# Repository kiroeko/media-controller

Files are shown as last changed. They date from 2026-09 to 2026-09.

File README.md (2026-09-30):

# media-controller

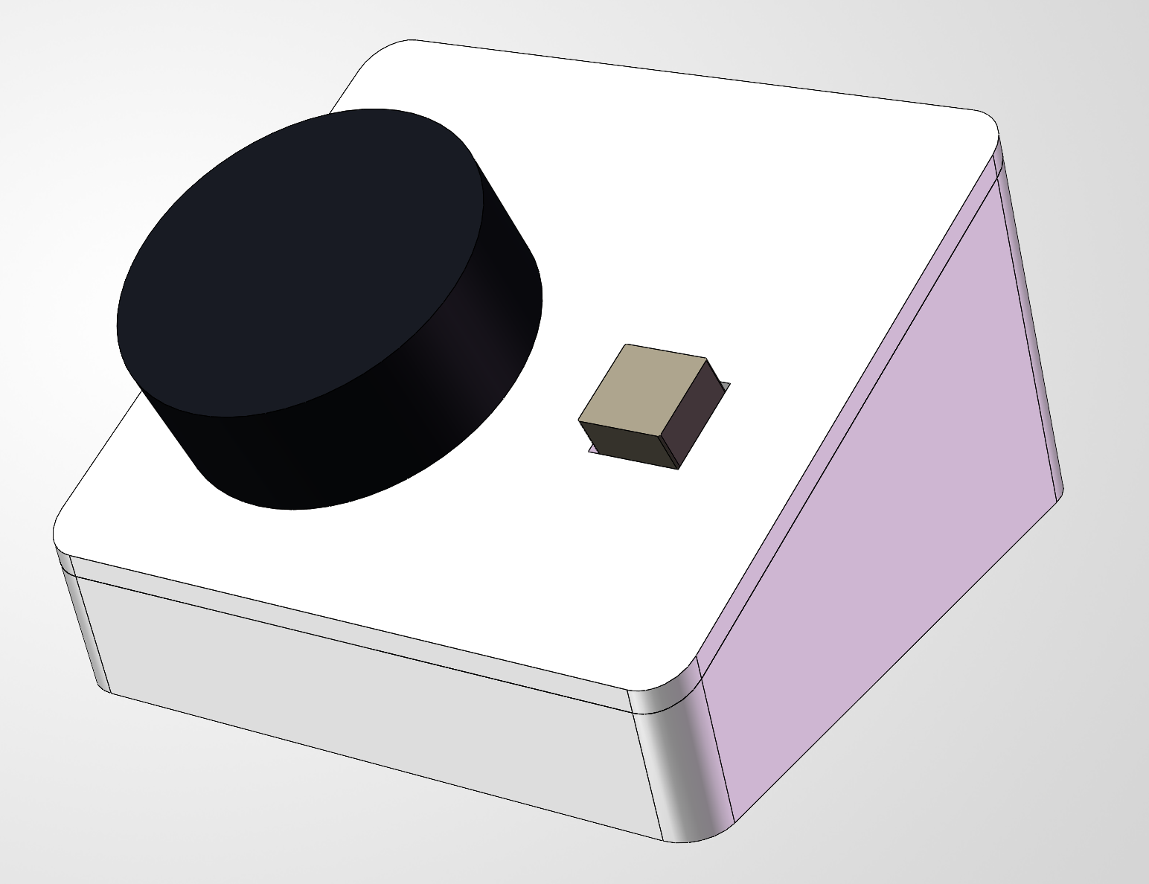
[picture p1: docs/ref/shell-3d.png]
整机外观：20° 斜面平整面板，左旋钮右按钮


一台 USB 媒体旋钮控制台：Type-C 接电脑，转旋钮调音量或切歌，按旋钮播放/暂停，长按静音，LED 自锁开关切换音量与切歌两种模式。电脑把它识别为标准 HID Consumer Control 设备，不需要安装专用驱动。

仓库包含这台设备完整的三部分设计，不只是固件。电气部分由三个现成模块组成，载板只做互连和 3V3/GND 分配，不重新设计电路；两个控件的固定、露出量和按压支撑全部交给外壳结构，载板上不布置它们的安装孔。

| 部分 | 位置 | 工具与格式 | 当前状态 |
| --- | --- | --- | --- |
| 固件 | `src/`、`include/`、`CMakeLists.txt` | C++17，Pico SDK 2.3.1 + TinyUSB | 已在整机上验证交互 |
| 载板 PCB | [hardware/pcb](hardware/pcb/README.md) | 嘉立创 EDA 专业版 `.eprj3` 工程 | v1.1 已下单并组装完成 |
| 外壳 | [hardware/enclosure](hardware/enclosure/README.md) | SOLIDWORKS 2026，导出 STL | 样件版次，待打印试装 |

三个模块是 **Waveshare RP2350-Zero** 主控、**Waveshare Rotation Sensor**（EC11 编码器带按键）和 **YFROBOT LED 自锁开关**，均为已购成品，实物资料在 [hardware/pcb/reference](hardware/pcb/reference/)。主控在调试阶段用带排针的 `-M` 版本，最终装配用无预焊排针版本，自行焊排针后插入载板排母。

## 仓库目录

```text
media-controller/
├─ README.md                 本文件：项目总览与固件说明
├─ CMakeLists.txt            板级定义 waveshare_rp2350_zero；产物 build/media-controller.uf2
├─ pico_sdk_import.cmake     pico-sdk 官方导入脚本
├─ src/                      固件实现，按分层分子目录
│  ├─ main.cpp               入口，只创建应用对象并启动
│  ├─ app/                   板级接线、运行状态与产品行为映射
│  ├─ device/                两个模块的引脚、电平、上下拉与采样节奏
│  ├─ input/                 去抖、格雷码与手势解码，不依赖 Pico SDK
│  └─ usb/                   TinyUSB 描述符、动作队列与报告发送
├─ include/                  头文件，子目录与 src/ 一一对应
├─ docs/
│  └─ ref/                   整机、载板与内部结构的参考渲染图
└─ hardware/
   ├─ pcb/                   载板：制板工程与设计记录
   │  ├─ kiro-media-controller-carrier-v1.1/   原理图、PCB 与拼板源工程
   │  ├─ reference/          三个已购模块的实物资料：主控尺寸图、按钮与编码器照片
   │  ├─ README.md           设计范围、连接方式与三个模块的实测尺寸
   │  ├─ ASSEMBLY.md         连接件规格、焊接步骤与接口方向
   │  └─ TUTORIAL.md         从新建工程到一键下单的分步教程
   └─ enclosure/             外壳：结构模型与打印文件
      ├─ cad/                Music_Controller.SLDASM 整机入口、4 个打印件、6 个 REF_ 参考件
      ├─ print/              4 个打印件的 STL
      ├─ docs/               装配与打印说明、STEP 导入、检查记录与三张剖面图
      └─ README.md           当前版次的结构改动与检查结果
```

`build/` 和 `.vscode/` 不纳入版本管理。硬件两个目录的说明各有侧重：PCB 侧记录实测尺寸、连接件选型和下单流程，外壳侧记录当前版次改了什么、检查到什么程度。SOLIDWORKS 整机入口是 `hardware/enclosure/cad/Music_Controller.SLDASM`，`cad` 里的 `REF_` 零件是器件参考模型，不打印，搬动装配体时要连整个 `cad` 目录一起带走。

下文说明固件的行为、接线、结构和构建刷写。

## 使用方式

模式开关使用 YFROBOT LED **自锁版**：每按一次切换开/关，松手后保持状态。

| LED 自锁开关 | 顺时针旋转 | 逆时针旋转 | 短按旋钮 | 长按旋钮 |
| --- | --- | --- | --- | --- |
| 熄灭：音量模式 | 音量加 | 音量减 | 播放/暂停 | 静音切换 |
| 点亮：切歌模式 | 下一首 | 上一首 | 播放/暂停 | 静音切换 |

旋转方向、模式切换、按键动作和切歌冷却机制已在整机上验证。当前冷却时间延长至 500 ms，时长的实际手感还需上板确认。LED 自锁开关单独通电时，测得灯灭时 `SIG` 对 `GND` 稳定约为 0 V、灯亮时约为 3.3 V，与固件设定的高电平有效极性一致。

在目前使用的 Windows 电脑上，一次音量动作会让系统显示值变化 2；电脑自带的独立音量键也是相同步长。这是主机侧的音量刻度，不能据此判断固件发送了两次动作。

短按在去抖后的松开时识别；长按在去抖后的按下状态持续 700 ms 后识别。手势解码器支持双击，但当前关闭该功能，250 ms 双击窗口不参与判断，也没有绑定媒体动作。

当主机挂起 USB 且允许远程唤醒时，新输入会尝试唤醒主机；成功入队的动作在总线恢复后继续发送。能否唤醒整机睡眠取决于主机配置，不能保证所有睡眠状态都可唤醒。

## 接线

两个模块都接开发板的 **3V3**，并与开发板共地；本项目不从 `5V` 或 `VBUS` 给模块供电。[RP2350 数据手册](https://datasheets.raspberrypi.com/rp2350/rp2350-datasheet.pdf)指出，使用的 GP2～GP5 属于容忍较高输入电压的 FT GPIO，且仅在 IOVDD 已供 3.3V 时才能容忍最高 5.5V 输入。统一使用 3.3V 供电可避免依赖这一条件及不同电源的上电顺序。

| 模块 | 信号 | RP2350-Zero-M |
| --- | --- | --- |
| LED 自锁开关 | `SIG` | `GP2` |
| EC11 Rotation Sensor | `SIA`（A 相） | `GP3` |
| EC11 Rotation Sensor | `SIB`（B 相） | `GP4` |
| EC11 Rotation Sensor | `SW`（内置按键） | `GP5` |
| 两个模块 | `VCC`、`GND` | `3V3`、`GND` |

LED 自锁开关的 `NC` 不接。EC11 模块的 A/B/SW 信号由模块板上拉高，固件不启用 MCU 内部上下拉。模式开关的 `SIG` 也不启用内部上下拉；单独供电实测灯灭时 `SIG` 对 `GND` 稳定约为 0 V，灯亮时约为 3.3 V。

开发板的排针丝印是裸数字，例如丝印 `3` 对应代码中的 `GP3`。接线时请以板上丝印和 [Waveshare RP2350-Zero 官方资料](https://www.waveshare.com/wiki/RP2350-Zero)中的引脚图为准，尤其要区分 `5V`、`GND` 与 `3V3`。

## 代码怎样运行

```text
main.cpp
  └─ MediaControllerApp::run()：初始化并持续轮询
       ├─ YfrobotLedLatchingSwitch / WaveshareRotationSensor：配置 GPIO、读取模块、控制采样节奏
       │    └─ DebouncedSwitch / ButtonGestureDecoder / QuadratureDecoder：只处理采样值
       ├─ 把模式、旋转格数和按键手势映射为媒体动作
       └─ media_hid：把动作排队，经 TinyUSB 发送 HID 报告
```

`main.cpp` 只创建应用对象并启动它。板上引脚编号和“旋转代表音量还是切歌”的规则集中在应用模块。器件类持有引脚，知道模块的高低电平、上下拉和采样节奏，向应用返回稳定状态、手势或机械卡点数。纯输入处理类接收采样值，按需要使用时间戳，不依赖 Pico SDK。`media_hid` 管理 USB 描述符、动作队列以及一次媒体按键的“按下 → 松开”报告。

| 位置 | 职责 |
| --- | --- |
| [src/main.cpp](src/main.cpp) | 固件入口 |
| [include/app/media_controller_app.h](include/app/media_controller_app.h) | 应用接口、运行状态以及板级接线和交互时序常量 |
| [src/app/media_controller_app.cpp](src/app/media_controller_app.cpp) | 初始化、主循环与产品行为映射 |
| [src/device/waveshare_rotation_sensor.cpp](src/device/waveshare_rotation_sensor.cpp) | 配置并读取 Waveshare 旋钮模块的 A/B/SW，A/B 两次采样至少间隔 1 ms |
| [src/device/yfrobot_led_latching_switch.cpp](src/device/yfrobot_led_latching_switch.cpp) | 配置并读取 YFROBOT LED 自锁开关的 SIG |
| [src/input/quadrature_decoder.cpp](src/input/quadrature_decoder.cpp) | 把两位 A/B 相位变化转换为带符号的机械卡点数 |
| [src/input/debounced_switch.cpp](src/input/debounced_switch.cpp) | 将原始有效/无效采样去抖，供模式开关和旋钮按键复用 |
| [src/input/button_gesture_decoder.cpp](src/input/button_gesture_decoder.cpp) | 从去抖后的按下/松开状态识别短按、长按、双击 |
| [include/input/button_gesture.h](include/input/button_gesture.h) | 器件、解码器和应用共用的手势事件与时间配置 |
| [src/usb/media_hid.cpp](src/usb/media_hid.cpp) | TinyUSB 描述符、HID 媒体报告与发送队列 |
| [include/usb/tusb_config.h](include/usb/tusb_config.h) | TinyUSB 编译配置；CMake 将此目录加入头文件搜索路径 |

这里没有额外包装 GPIO、SPI、USB 的通用“物理层”；底层访问直接使用 Pico SDK 和 TinyUSB。以后接屏幕时，屏幕驱动负责面板命令和总线传输；只有像素转换或渲染逻辑变复杂时，才需要单独提取不依赖硬件的编码组件。

设备自身的采样间隔、去抖时长和每格跳变数放在对应类的 `private static constexpr` 常量中，供该类型的所有实例共用。应用的接线和交互时序配置也集中在 `MediaControllerApp` 的类内常量中；读取时间的辅助函数是该类的私有静态函数。输入算法的转换表保存在对应 `.cpp` 文件内。[media_hid.cpp](src/usb/media_hid.cpp) 将 USB 描述符保存为文件内常量；`MediaHidState` 则保存序列号、字符串描述符缓冲区、动作队列和按键发送状态，供 USB 回调在固件运行期间使用。这些状态不暴露给应用层。

配置参数、描述符和查表常量的名称统一使用小写加下划线，例如 `sig_debounce_ms`、`device_descriptor`、`transition_delta`；常量性质由 `constexpr` 或 `const` 表达，名称不加 `k` 前缀。

### 初始化约定

`input` 和 `device` 类型使用默认构造，不显式定义构造函数，也不在构造时访问硬件。调用方通过一次 `init()` 提供所需的外部配置和初始状态。对象默认构造后仍须先调用 `init()`，才能调用 `update()` 或读取结果。

1. `MediaControllerApp::run()` 先调用 `board_init()`，再把接线配置和起始时间交给设备的 `init()`。旋转模块用自身的 `WaveshareRotationSensor::Config` 收拢三个引脚和手势规则；模式开关直接接收 SIG 引脚。
2. 设备的 `init()` 配置 GPIO、读取初始电平，再调用内部输入组件的 `init()`。模块自身的采样间隔、去抖时长和每格跳变数仍由设备实现定义。
3. 输入组件的 `init()` 一次接收算法配置、初始采样以及需要的时间戳，建立状态基准并清空累计结果或待取事件。后续 `update()` 持续处理新采样。

接口参数统一将配置放在前面，时间戳和初始采样放在后面。例如 `DebouncedSwitch::init(debounce_ms, now_ms, raw_active)`，以及 `ButtonGestureDecoder::init(config, now_ms, pressed)`。

### 从旋钮到电脑的一次操作

1. `WaveshareRotationSensor` 在主循环中至少间隔 1 ms 才再次读取 SIA/SIB，组成两位相位状态；SW 在主循环每轮读取。主循环如果延迟，A/B 相的采样也会变慢，不会补读中间状态。
2. `QuadratureDecoder` 查格雷码状态变化，每凑满一格就累计一次正向或反向计数。按本项目的 SIA→GP3、SIB→GP4 接线，查表约定使顺时针卡点为正、逆时针为负。当前主循环每轮最多更新解码器一次，随后立即调用 `take_detents()`，所以此处每轮只会得到 `-1`、`0` 或 `+1`；如果其他调用方连续更新多次后才取走计数，才可能一次得到多格。`DebouncedSwitch` 用时间戳去抖，`ButtonGestureDecoder` 再识别手势。模式自锁开关只使用去抖结果。
3. `MediaControllerApp` 根据模式开关状态，把卡点映射为音量或切歌动作，把短按/长按映射为播放暂停/静音。同一轮先排入按键动作，再排入旋转动作。切歌冷却属于产品交互规则，因此在应用层判断；输入解码器仍处理每个相位变化。
4. `media_hid` 向 TinyUSB 提交 HID Consumer Control 报告；每个动作先发送按下，至少 8 ms 后且 HID 端点就绪时再发送松开。

应用循环不能长时间阻塞，否则会漏掉旋钮相位或按键变化。旋钮的 `take_detents()` 返回的是机械卡点数，不是完整转了几圈。

### 切歌冷却与动作队列

`MediaControllerApp` 不保存待发送动作的队列；它决定输入对应什么媒体动作，再调用 `media_hid_enqueue()`。真正的待发送队列位于 `media_hid`，用来让主循环在 USB 按键发送期间继续读取输入。

1. 音量模式每个有效卡点尝试排入一次音量动作。切歌模式成功排入一次下一首或上一首后，开始固定的 500 ms 冷却期；期间的正反向旋转仍被采样和解码，但不产生切歌动作，也不会留到冷却结束后补发。被忽略的旋转不延长冷却期。只有成功入队才启动冷却；音量与旋钮按键不受它限制。
2. 同一轮同时识别到按键和旋转时，播放/暂停或静音先入队，旋转动作后入队。队列始终按入队顺序发送：新按键不会越过之前排队的旋转动作。
3. 队列使用 16 个数组位置，其中一个保持空闲以区分队列空和满，因此最多有 15 个**待发送**动作。当已有 14 个待发送动作时，旋转动作不能再入队，为按键留出最后一个位置；按键可使用该位置。队列满时新动作直接丢弃，不阻塞、不重试，也不合并或取消旧动作；连续按键同样可能占满队列。
4. USB 层按顺序为每个动作发送“按下”报告，至少 8 ms 后在 HID 端点就绪时发送“松开”报告，然后处理下一个动作。按下报告提交成功时，该动作就从待发送队列移除。切歌冷却从**入队时**计算，不等电脑实际收到动作；若队列积压，停转后仍可能继续发送先前入队的动作。

## 故障排查

| 现象 | 调整位置 |
| --- | --- |
| 顺逆时针相反 | 核对 `SIA`→`GP3`、`SIB`→`GP4` 接线和 [quadrature_decoder.cpp](src/input/quadrature_decoder.cpp) 的方向查表 |
| 灯亮时仍处于音量模式 | 核对 `SIG`→`GP2` 和共地接线；灯亮时 `SIG` 应约为 3.3 V，固件按高电平表示开处理 |
| 一格触发多次，或多格才触发一次 | 实测后调整 [waveshare_rotation_sensor.h](include/device/waveshare_rotation_sensor.h) 的 `transitions_per_detent` |
| 快速旋转漏格 | 检查主循环是否阻塞、USB 队列是否满，以及 [waveshare_rotation_sensor.h](include/device/waveshare_rotation_sensor.h) 的 `encoder_sample_interval_ms` |

[Waveshare Rotation Sensor 的规格页](https://www.waveshare.com/wiki/Rotation_Sensor)标称每圈 20 个脉冲，但没有给出机械卡点数；当前使用 `transitions_per_detent = 4`，实机操作得到预期的每格动作。应用模块的 `button_gesture_config` 设置长按阈值为 700 ms，250 ms 双击窗口当前未启用。方向查表的符号也已按 SIA→GP3、SIB→GP4 接线调整并完成实机验证。

## 构建与刷写

项目使用 Pico SDK v2.3.1、ARM 工具链和 Ninja。`CMakeLists.txt` 选择 pico-sdk 自带的 `waveshare_rp2350_zero` 板级定义；VS Code 用户可以通过 Raspberry Pi Pico 官方扩展导入本目录。CMake 文件顶部的 VS Code 扩展钩子由扩展管理。

在项目根目录执行以下命令，开发调试时显式选择 Debug：

```powershell
cmake -S . -B build -G Ninja -DCMAKE_BUILD_TYPE=Debug
cmake --build build
```

需要 Release 时，显式指定 Ninja；如果 `build/` 已经由 Ninja 生成，可以直接在同一个目录切换构建类型，无需删除它：

```powershell
cmake -S . -B build -G Ninja -DCMAKE_BUILD_TYPE=Release
cmake --build build
```

`cmake --build build` 使用构建目录中已经保存的配置，不会自动选择 Debug 或 Release。设置构建类型后，后续只修改源码时直接运行这条命令即可。

配置命令中的 `-G Ninja` 指定生成器。Windows 上新建构建目录时若省略它，CMake 可能默认选择 Visual Studio，随后 `cmake --build build` 就会调用 MSBuild；VS Code 中的 `cmake.generator` 设置也不会自动应用到手动执行的命令。

当前 Pico SDK 工具链的主要编译参数如下，两种配置生成的 UF2 都可以刷到板子上运行：

| 配置 | 主要编译参数 | 用途 |
| --- | --- | --- |
| Debug | `-Og -g` | 方便调试，适度优化 |
| Release | `-g -O3 -DNDEBUG` | 更强的优化，保留调试符号，默认禁用标准 `assert` |

普通 Ninja 在配置阶段通过 `CMAKE_BUILD_TYPE` 选择构建类型；`--config Release` 用于 Visual Studio、Ninja Multi-Config 等多配置生成器，不用于切换本项目普通 Ninja 的构建类型。参见 [CMake 官方说明](https://cmake.org/cmake/help/latest/variable/CMAKE_BUILD_TYPE.html)。

如果构建日志出现 MSBuild，或者报错找不到 `boot_stage2/Debug/bs2_default.elf`，先检查 `build/CMakeCache.txt` 中的 `CMAKE_GENERATOR`。本项目使用 Ninja 构建；若该目录已经由 Visual Studio 生成，需要重建 CMake 配置缓存后切换生成器：

```powershell
cmake --fresh -S . -B build -G Ninja -DCMAKE_BUILD_TYPE=Release
cmake --build build
```

`--fresh` 需要 CMake 3.24 或更新版本，会重建构建目录内的 `CMakeCache.txt` 和 `CMakeFiles/`，不修改源码。恢复之后，继续使用普通的配置和构建命令即可。Visual Studio 是多配置生成器，`CMAKE_BUILD_TYPE=Release` 不会为它选中 Release，这也是不能只修改构建类型来解决上述问题的原因。参见 [CMake 的 `--fresh` 说明](https://cmake.org/cmake/help/latest/manual/cmake.1.html#cmdoption-cmake-fresh)。

编译产物是 `build/media-controller.uf2`。按住开发板 `BOOT` 键，通过数据线连接电脑；出现 `RPI-RP2` 盘后，将 UF2 文件复制进去，开发板会重启并枚举为 USB HID 媒体控制设备。

第一次刷写时可以先拔下 GP2～GP5 的外设线，只确认电脑能识别 HID 设备，再接回模块核对方向、模式和按键手势。

USB 产品名当前是 `Kiro Media Controller`，定义在 [media_hid.cpp](src/usb/media_hid.cpp) 的字符串描述符中。每块板子的序列号由 RP2350 唯一 ID 生成。首次刷写前修改名称不会遇到旧设备缓存；以后若在相同 VID/PID/序列号下修改描述符，建议同步更新 `device_descriptor` 中的 `bcdDevice`，并让主机重新枚举设备。

当前 VID `0xCAFE` 是 TinyUSB 示例值，并非分配给本项目；对外销售时需要更换为合法取得的 VID/PID。远程唤醒也需要电脑允许，Windows 设备管理器不一定会为此类设备提供或启用唤醒选项。

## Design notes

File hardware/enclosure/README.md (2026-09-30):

# 音乐控制器外壳：当前版本

**用 SOLIDWORKS 2026 打开 [cad/Music_Controller.SLDASM](cad/Music_Controller.SLDASM)。这是唯一的整机入口。**

本目录是 2026-09-27 整理后的当前设计：20° 斜面、左旋钮右按钮、平整面板、内部固定、后部居中 USB-C。它是待实物试装的样件，尚未打印验证。

外壳外观：平整面板，左旋钮右按钮，20° 斜面

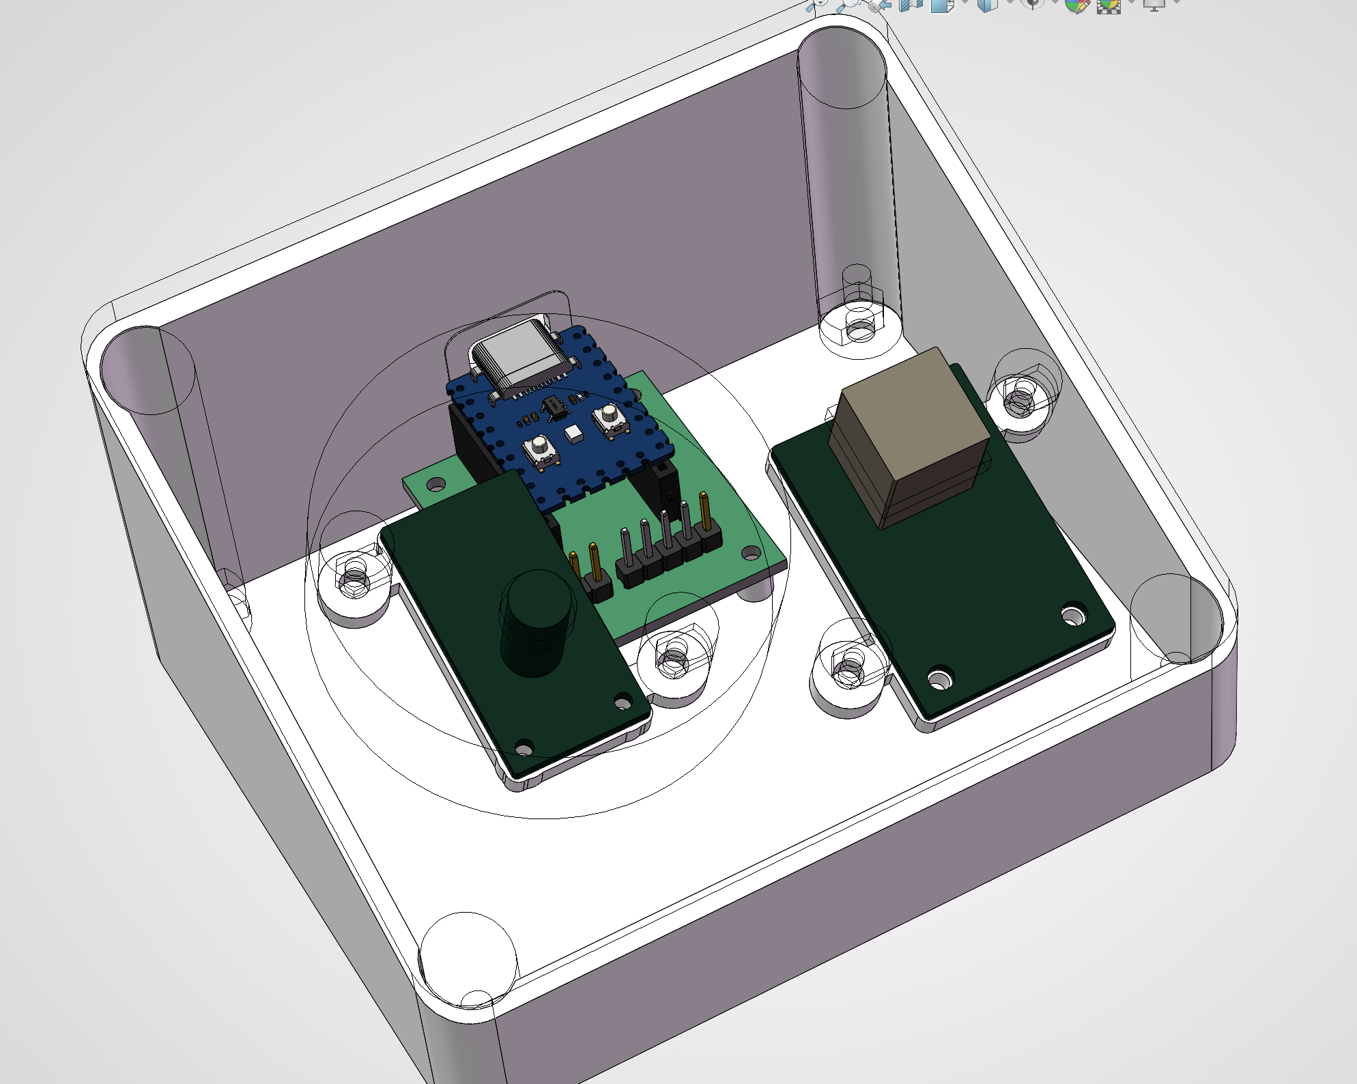
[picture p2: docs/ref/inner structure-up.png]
底壳内部俯视：载板居后中，编码器与按钮模块装在各自托架上


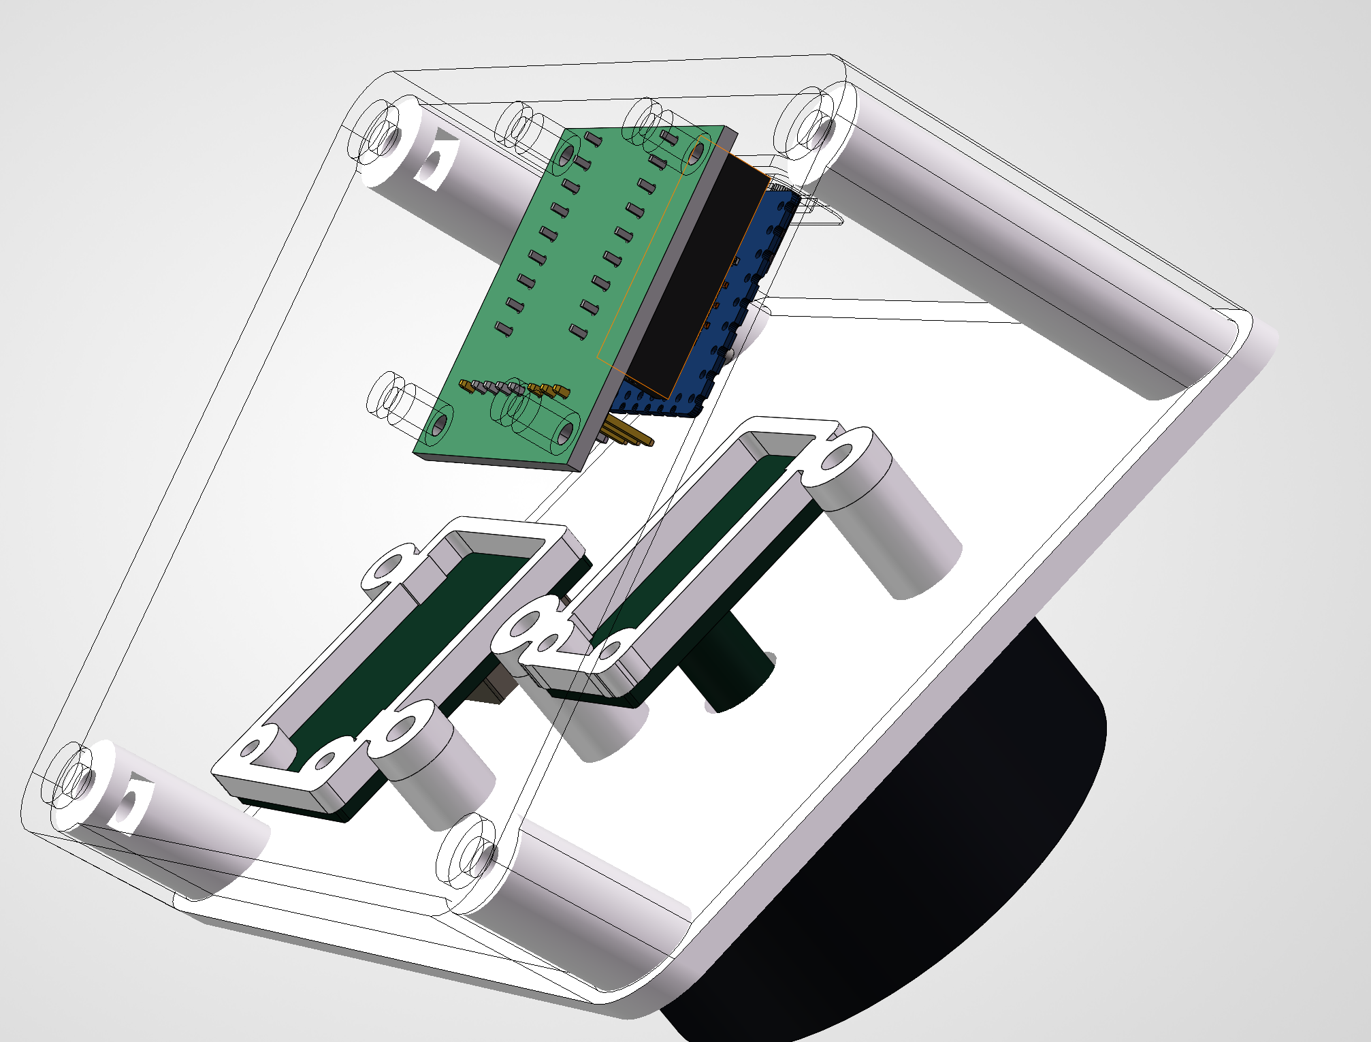
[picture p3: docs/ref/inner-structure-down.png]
上盖内侧：两个托架、固定柱与侧装螺母位置


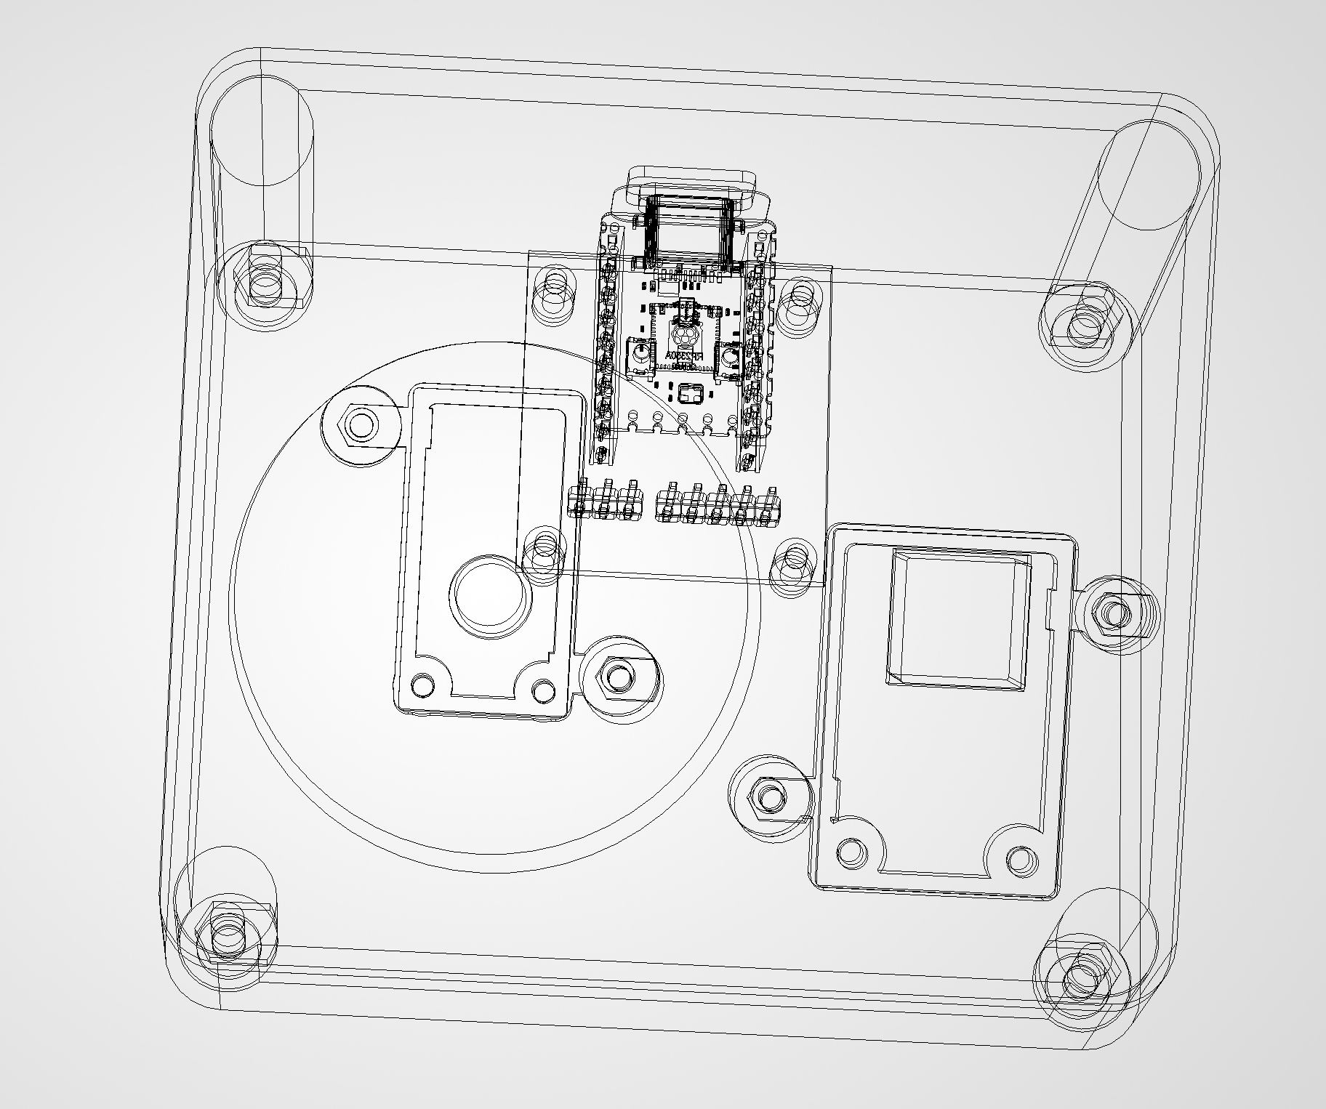
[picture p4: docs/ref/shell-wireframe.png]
整机线框顶视：内部占位、螺丝柱与螺母


**编码器已转为排针朝后，旋钮中心保持原位。** 上盖内对应两根固定柱、螺丝孔及螺母槽已移动，原编码器托架旋转 90° 后继续使用。按实测总长约 48.5 mm，板边外预留取整为 22 mm，额外留约 5.8 mm；以宽 16.92 mm、高 6 mm 的接头与弯线检查范围复核，未碰到现有实体。截面为设计假设，仍需实物确认。结构变化集中在 [上盖 STL](print/Lid_Smooth_20deg.STL)，底壳和两个托架形状不变；四个 STL 已统一从当前 CAD 重新导出。[查看内部布局](docs/ENCODER_REAR_LAYOUT.png)；[装配和检查详情](docs/ASSEMBLY.md#编码器出线复核2026-09-27)。

**已修正上盖八处螺母槽的薄壁角落。** 原矩形槽使最小按钮柱局部仅剩约 0.135 mm；现采用普通六角螺母适配的封闭端，并将右侧按钮柱加粗至 Ø7.6 mm。最终 STL 的槽封闭端截面最小壁厚约 1.37 mm，其余对应部位约 1.57 或 1.65 mm。螺丝孔位置、M2/M3 规格不变。需重新上传当前上盖 STL 给打印厂复审。[查看截面对比](docs/NUT_SLOT_SECTION.png)。

**当前底壳 USB-C 改为圆角内凹结构：外槽 13 × 8 mm、深 1.2 mm，内孔 10.5 × 5 mm，槽底厚 1.5 mm。** 按实测 11.26 × 6.43 mm 线头包胶、插到底后包胶前沿距插座口 1.8 mm 设计，包胶距槽底名义余量约 1.06 mm。小孔周围的槽底遮挡内部，保留装配间隙。重新提交打印审核使用 [print/Base_Smooth_20deg.STL](print/Base_Smooth_20deg.STL)，无需另找新版文件夹。[查看原生装配预览](docs/USB_RECESS.png)。

| 要做什么 | 使用哪个文件 |
|---|---|
| 查看、继续设计整机 | `cad/Music_Controller.SLDASM` |
| 修改底壳 | `cad/Base_Smooth_20deg.SLDPRT` |
| 修改上盖 | `cad/Lid_Smooth_20deg.SLDPRT` |
| 修改旋钮模块托架 | `cad/Encoder_Cradle.SLDPRT` |
| 修改按钮模块托架 | `cad/Button_Cradle.SLDPRT` |
| 3D 打印 | `print` 中的四个 STL，各一件，mm、100% 比例 |
| 看装配尺寸、螺丝与打印方向 | [装配与打印](docs/ASSEMBLY.md) |
| 处理嘉立创 STEP 保存问题 | [STEP 导入说明](docs/STEP_IMPORT.md) |

`cad` 中的六个 `REF_` 零件是整机需要的电子器件参考，不是旧版，也不用打印。请把整个 `cad` 文件夹一起保留或复制，不要单独搬走装配体。

目录只保留当前 CAD、打印文件和说明。旧版、重复导出、临时脚本与测试文件已删除，原 Pictures 工作目录也已清理。无需运行宏或导入 STEP。

10 个组件全部从 `cad` 加载。载板参考为独立实体零件，没有对嘉立创 STEP 的外部文件依赖。当前十个组件重建成功、实体干涉为零；四个打印零件均为单一实体、特征无错误，保存和 STL 导出均为 0 错误、0 警告。整机透视状态在操作前后均为开启，已随装配保存。四个 STL 的闭合、边方向、法向及自交检查通过。槽封闭端的局部壁厚另做截面核对，尚未获得打印厂对本次新文件的复审结论。详见 [检查记录](docs/VERIFICATION.txt)。

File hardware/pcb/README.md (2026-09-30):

# PCB 设计

本目录用于保存媒体控制器载板的嘉立创 EDA 工程，包括原理图、PCB 布局及工程使用的本地库文件。

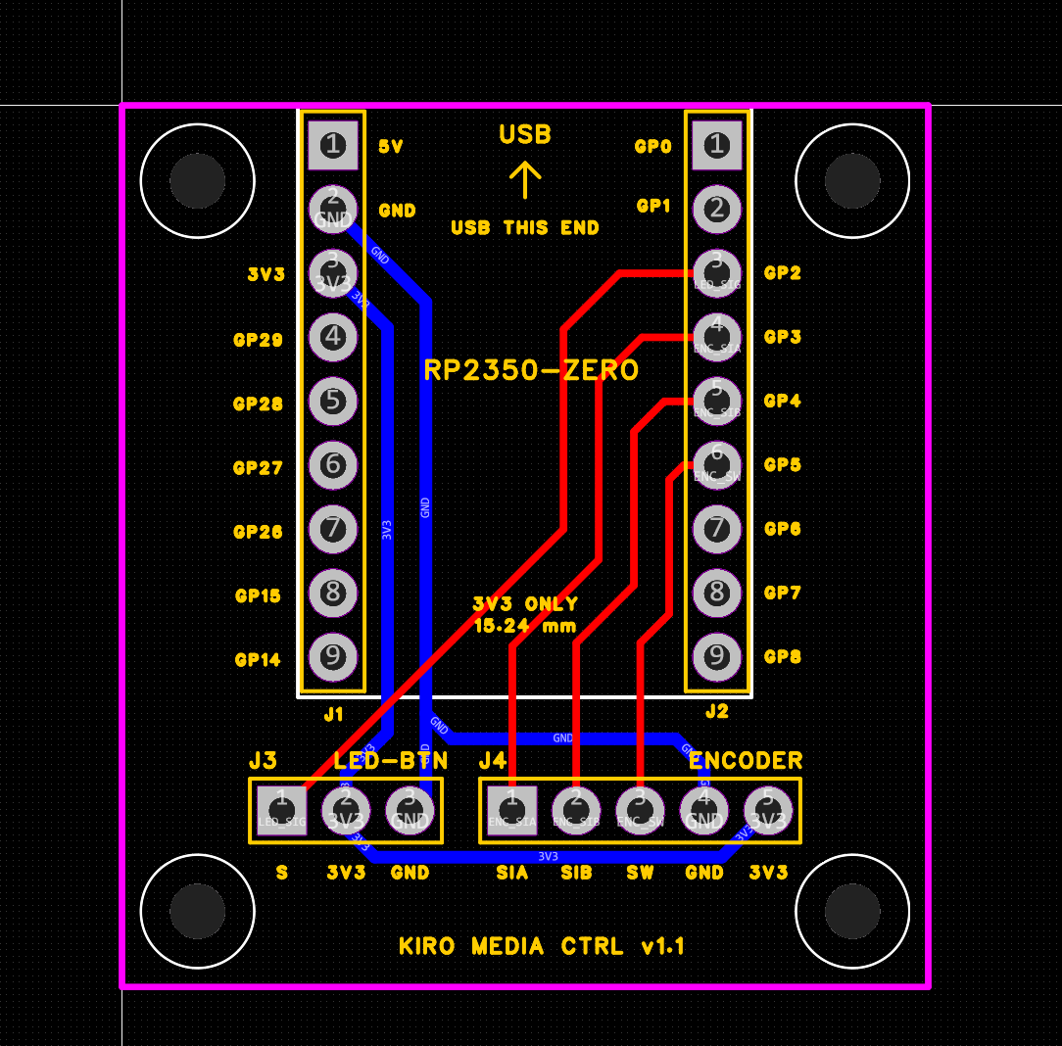
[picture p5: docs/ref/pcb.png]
载板二维布局：J1/J2 两条 1×9 排母、J3 三针与 J4 五针排针、四角固定孔


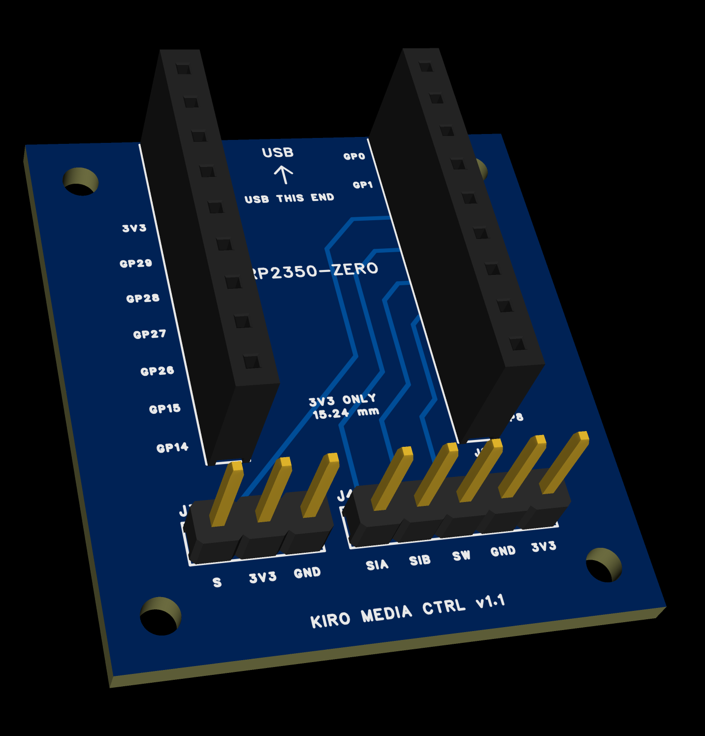
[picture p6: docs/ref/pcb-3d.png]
载板三维：两条排母与 J3/J4 排针装入后的外观


学习从零绘制同类接线板：[从新建工程到制板的分步教程](TUTORIAL.md)。

当前工程入口：[kiro-media-controller-carrier-v1.1.eprj3](kiro-media-controller-carrier-v1.1/kiro-media-controller-carrier-v1.1.eprj3)（嘉立创 EDA 专业版，Git 友好格式）。v1.1 已下单，板子已焊接组装完成（2026-09-30）。请先阅读 [连接件清单与装配说明](ASSEMBLY.md)。

当前 PCB 丝印为 `KIRO MEDIA CTRL v1.1`。可编辑工程使用嘉立创 EDA 的目录格式，直接纳入 Git；保留整个 `kiro-media-controller-carrier-v1.1/`，不要只复制其中的 `.eprj3` 索引文件。

源工程包含 J1～J4 的完整针脚标签，左右标签间距一致，地线统一标为 `GND`。制板使用嘉立创 EDA 一键下单，由客户端自动上传生产文件，不需要手动导出或上传 ZIP；仓库保留可编辑源工程，不保留制造 ZIP。

## 目录与版本管理

| 路径 | 用途 |
| --- | --- |
| `kiro-media-controller-carrier-v1.1/` | 唯一的正式原理图与 PCB 源工程 |
| `ASSEMBLY.md` | 连接件规格、焊接步骤和接口方向 |
| `reference/` | 三个已购模块的实物资料：主控官方尺寸图、LED 按钮与编码器照片 |
| 本文件 | 设计说明与用户确认的测量记录 |

制板前在 EDA 保存工程并运行 DRC，核对下单文件预览；用 Git 提交或标签记录对应的源工程版本，生产资料按订单留存。本地保存或推送 Git 不会自动更新工厂订单。需要分享工程时，可从 Git 获取整个源工程目录；不在仓库重复保存工程压缩包、制造 ZIP、Gerber 解压副本、预览图或生成过程文件。

## 已购硬件与实物资料

三个模块都是已购成品，`reference/` 只保留它们的实物资料，作为封装、接线和外壳核对的依据：

| 已购模块 | 资料 | 用途 |
| --- | --- | --- |
| Waveshare RP2350-Zero（调试用带排针 `-M`，最终装配用无预焊排针版） | [官方尺寸标注图](reference/rp2350-zero-official-dimensions.png) | 主控封装、焊孔排列与排母位置以此图为准 |
| YFROBOT LED 自锁开关 | [模块与原装转接线照片](reference/led-button-side-profile.jpg) | 按钮外形、侧面轮廓与 S/V/G 线序的依据 |
| Waveshare Rotation Sensor | [模块正面照片](reference/rotation.jpg) | 安装孔位置、`SIA/SIB/SW/GND/VCC` 丝印与弯排针方向的依据 |

编码器照片里未装圆帽、已装弯排针；下文实测尺寸记录的是装好日常圆帽的状态。LED 按钮照片里转接线一端是带卡扣的白色插头（接模块插座），另一端是三孔杜邦母头。

检查结论：原理图 DRC 0 错误、0 警告；PCB 原生 DRC 141 项、0 问题。几何摘要（读自 v1.1 源工程）：六个网络 `3V3`、`GND`、`LED_SIG`、`ENC_SIA`、`ENC_SIB`、`ENC_SW` 全部布通；26 个连接器孔和 4 个固定孔；板框 32 × 35 mm，单一矩形；无过孔；连接器焊孔 1.05 mm、焊盘外径 1.9 mm。最小异网铜间距按几何计算为 **0.596 mm**，出现在两处：底层 `3V3` 斜线到 J4.4 `GND` 焊盘、底层 `GND` 斜线到 J1.3 `3V3` 焊盘；相邻连接器焊盘之间为 0.640 mm（2.54 − 1.90），线与线之间最小 1.024 mm。读法见下文「最小异网铜间距怎么读」。这些结论不代替实物焊接和功能测试。

### 最小异网铜间距怎么读

设计规则里的安全间距是**要求**，不是实测值：顶部菜单「设计 → 设计规则」的间距规则/安全间距表格设置两个不同网络图元之间的间距要求。「设计 → 检查DRC」只报违反已启用规则的位置，面板给出错误类型和每条错误的信息、可跳转到对应规则，但不会直接给出全局最小间距。[官方：检查DRC](https://prodocs.lceda.cn/cn/pcb/design-check-drc/)、[官方：设计规则](https://prodocs.lceda.cn/cn/pcb/design-design-rule/)

读实际数值有两条路：

1. **量指定两处**：「工具 → 测量距离」点选两个异网铜对象，读出的就是该处间隙。本板铜对象很少（35 段线、14 个有网络的焊盘），最紧处就是上面列的两处。
2. **扫全局最小**：把安全间距临时调到比预期大的值（例如 0.8 mm）跑一次检查DRC，报出来的就是所有比它紧的位置；逐步下调到 0 问题，最后一次报错的阈值附近即实际最小值。调回正式规则值后再跑一次，确认仍是 0 问题。

## 设计范围

设计方向已由用户收窄为紧凑电气接线板：保留 RP2350-Zero、Waveshare Rotation Sensor 和 YFROBOT LED 自锁开关三个现成模块，PCB 只负责主控连接、3V3/GND 分配及信号互连。LED 和编码器的线既可插接，也可直接焊接；两个控件的固定、露出量和按压支撑交给外壳结构设计，不在接线板上布置这两个模块的定位安装孔，也不要求三个模块共用同一安装平面。接线 PCB 已由 v1.1 完成并组装，外壳结构见 [hardware/enclosure](../enclosure/README.md)。

用户已澄清：最终装配的 RP2350-Zero 没有预焊排针，调试使用的则是 RP2350-Zero-M；不能把调试板的排针高度套用到最终硬件。用户确认能够自行焊接，主控按焊排针后插入连接板排母的方向安排，采用常规约 8.5 mm 高排母与约 2.54 mm 塑料定位条的公针，配合规格见装配说明。编码器和 LED 模块保留原有接口，通过配套杜邦转接线连接 PCB。

接口采用 2.54 mm 间距的通孔焊盘。LED 的 1×3 接口和编码器的 1×5 接口可选焊公排针后插接原配杜邦线，或不装排针、将导线直接焊入同一组通孔；默认保留完整原线并使用插接。每个焊盘均应有清楚的信号丝印。载板设四个 2.2 mm 非金属化固定孔，孔位坐标见装配说明；这些孔与两块控件模块原有安装孔无关。

## 已确认的连接方式

- **RP2350-Zero**：用户明确主控板只有电气焊孔，没有独立的螺丝固定孔。用户自行焊排针，插入载板上对应排母进行连接和支撑。排针布局采用用户提供的官方尺寸图：左右各一排 9 孔、孔距 2.54 mm、两排中心距 15.24 mm；载板对应两条 1×9 排母。通用连接件规格已列在装配说明中，精确装配高度以实际插合为准，不要求用户重复测量图纸已给出的焊孔布局。
- **旋转编码器**：保留模块上的现有五针接口。用户说明配套的五路杜邦转接接头可组合使用，也可拆成独立接头，并确认组合后能完全配合调试主控的连续排针，因此载板接口采用 1×5、2.54 mm 间距公头，按 SIA、SIB、SW、GND、3V3 标注（3V3 对应模块 VCC）。
- **LED 按钮模块**：用户说明模块端为内凹的公头，原配转接线带卡扣，另一端为固定连体三孔杜邦母头。保留完整的原配 4Pin 转 3Pin 杜邦线，载板使用匹配的三针公头，不需要剪断线材或拆改模块插座；模块端空脚不接。用户报告线色对应为 G = 黑、V = 红、S = 白，并确认三孔母头中间为红线 V，两端为黑线 G 和白线 S，即沿插孔排列为 S–V–G（反向观察为 G–V–S）。此处记录用户提供的信息，未做独立电气核验。用户确认三孔母头能完全配合调试主控的连续排针，因此载板接口采用 1×3、2.54 mm 间距公头，按 S、3V3、GND 顺序标注，3V3 位于中间。

### 载板连接关系

用户说明当前调试接线通过面包板分配共用的 3V3 和 GND。载板用铜箔连接这两个公共网络，为 LED 和编码器各自的接口提供电源和地，替代面包板的分线作用。主控的电源针不需要叠插多个杜邦接头。

| RP2350-Zero | LED 接口 | 编码器接口 |
| --- | --- | --- |
| 3V3 | V（红线，中间针） | VCC |
| GND | G（黑线） | GND |
| GP2 | S（白线） | — |
| GP3 | — | SIA |
| GP4 | — | SIB |
| GP5 | — | SW |

上述信号对应沿用项目现有固件和调试接线；两个模块均使用 3V3，不接主控 5V。原理图和 PCB 已按此表连接。

用户补充当前面包板一共使用 14 个接线点：3 个 3V3、3 个 GND，以及 8 个信号接线点。对应的是 6 个独立电气网络：3V3 和 GND 各连接三个端点，GP2/S、GP3/SIA、GP4/SIB、GP5/SW 各连接两个端点。8 个信号接线点不是 8 路独立信号。

按设备划分，主控侧需要 6 个端点（3V3、GND、GP2、GP3、GP4、GP5），LED 侧 3 个端点，编码器侧 5 个端点，合计 6 + 3 + 5 = 14。用户已明确选择沿用主控直接插板的方案：主控插入两条 1×9 排母，其中 6 个主控针位用于本项目连接，主控侧不需要另接六根跳线。外设接口仍为 LED 的 3 针和编码器的 5 针，不另设独立的主控六针转接接口。

因此接线板具有两条 1×9 主控排母的焊孔，以及 1×3 LED、1×5 编码器通孔接口，共 26 个连接器焊孔，其中 14 个接点参与当前电路，其余 12 个主控针位不接网络。物理焊孔总数与用户原面包板上使用的接线点数含义不同，不据 14 个接线点削减主控排母的机械配合位置。

## LED 自锁开关模块实测尺寸

数据由用户于 2026-09-26 使用数显卡尺提供。方向：模块正面朝上，按钮在上、白色插座在下；安装使用插座左右的两个小孔。

| 项目 | 数值（mm） |
| --- | ---: |
| PCB 宽度 | 24.05 |
| PCB 长度 | 35.73 |
| 左、右安装孔内径 | 3.00 |
| 左孔左边缘到左板边 A | 2.00 |
| 右孔右边缘到右板边 B | 2.00 |
| 左孔下边缘到下板边 C | 1.86 |
| 右孔下边缘到下板边 D | 1.86 |
| PCB 板厚 t | 1.60 |
| PCB 下表面到弹起按钮顶面的高度 H | 15.00 |
| PCB 下表面到背面最突出物末端 B | 1.00 |
| 按钮顶面高于 PCB 上表面（H − t） | 13.40 |
| 背面最低点到按钮顶面的整体高度（H + B） | 16.00 |

以 PCB 左下角为原点，X 向右、Y 向上，按实测孔径 3.00 mm 推算：

- 左孔中心：`(3.50, 3.36) mm`。
- 右孔中心：`(20.55, 3.36) mm`。
- 两孔中心距：`17.05 mm`。
- 两孔中心距上板边：`32.37 mm`。

孔位是实测推算值，尚未验证厂家公称尺寸，不自动取整成 17 mm。用户已按统一高度基准提供 `t = 1.6 mm`、`H = 15 mm`、`B = 1 mm`：按钮顶面高于 PCB 上表面 `15 - 1.6 = 13.4 mm`，模块整体高度为 `15 + 1 = 16 mm`。

## 旋转编码器模块实测尺寸

数据由用户于 2026-09-26 提供，模块照片见 [reference/rotation.jpg](reference/rotation.jpg)。方向以模块正面照片为准：两个安装孔位于左侧，5Pin 弯排针朝右；背面照片的左右方向相反。

| 项目 | 数值（mm） |
| --- | ---: |
| PCB 长度 L（左右，不含排针） | 32.30 |
| PCB 宽度 W（上下） | 16.92 |
| 弯排针裸针长度（2026-09-27 补测） | 6.69 |
| 编码器沿 PCB 长边方向总占位（2026-09-27 最新补测） | 约 48.5；当前沿用此前包含接头及导线弯折的测量口径 |
| 排针侧 PCB 板边外占位（由最新总长推算） | 约 16.2 = 48.5 − 32.30；此前单独测得 15.62，后续布局采用较大的 16.2，不再另加裸针长度 |
| 可拆旋钮帽外径 | 50.00 |
| 上、下安装孔内径 | 2.03 |
| 上孔左边缘到左板边 A | 1.35 |
| 下孔左边缘到左板边 B | 1.35 |
| 上孔上边缘到上板边 C | 1.35 |
| 下孔下边缘到下板边 D | 1.35 |
| 带螺纹轴套的实测外径 | 6.81 |
| 轴心距上、下板边（用户确认宽度方向居中） | 8.46 |
| 轴心距非引脚侧板边（用户最新激光放样长度测试） | 12.275 |
| 轴心距 5Pin 引脚侧板边（用户最新激光放样长度测试） | 20.025 |
| PCB 板厚 t | 1.78 |
| PCB 下表面到装好圆帽顶面的高度 H（未按下） | 33.97 |
| PCB 下表面到背面最突出物末端 B | 2.41 |
| 圆帽顶面高于 PCB 上表面（H − t） | 32.19 |
| 背面最低点到圆帽顶面的整体高度（H + B） | 36.38 |
| 圆帽自身轴向高度 K | 18.07 |
| 圆帽下沿距 PCB 下表面（H − K） | 15.90 |
| 圆帽下沿距 PCB 上表面（H − K − t） | 14.12 |

以正面视图的 PCB 左下角为原点，X 向右、Y 向上，按实测孔径 2.03 mm 推算：

- 上孔中心：`(2.365, 14.555) mm`。
- 下孔中心：`(2.365, 2.365) mm`。
- 上下孔中心距：`12.190 mm`。

推算结果保留了半径运算产生的小数位，不代表卡尺测量具有 0.001 mm 精度。未按照片比例或厂家公称尺寸改写用户实测数据。轴套外径 6.81 mm 单独记录，尚未据此确定螺纹规格、螺距或面板开孔尺寸。

用户确认轴心在宽度方向居中，因此其 Y 坐标按 `16.92 / 2 = 8.46 mm` 记录。长边方向采用用户最新标注为“激光放样长度测试”的读数：非引脚侧 12.275 mm、5Pin 引脚侧 20.025 mm；两者合计 32.300 mm，与板长一致。按此前确定的方向，轴心坐标更新为 `(12.275, 8.46) mm`，替换之前的 12.28 mm 结果。保留用户提供的小数位，独立记录的 6.81 mm 螺纹轴套外径不变。

旋钮帽的平面投影半径为 25 mm。按最新轴心坐标计算，圆帽包围盒为 `X = -12.725～37.275 mm`、`Y = -16.54～33.46 mm`；这些仅用于检查初步布局，不能作为精确面板开孔或最终外壳尺寸。用户已按统一高度基准提供 `t = 1.78 mm`、`H = 33.97 mm`、`B = 2.41 mm`、圆帽自身轴向高度 `K = 18.07 mm`，由此得到圆帽顶面高于 PCB 上表面 32.19 mm，模块整体高度 36.38 mm。圆帽下沿距 PCB 下表面 `33.97 - 18.07 = 15.90 mm`，距 PCB 上表面 `15.90 - 1.78 = 14.12 mm`。布局时需结合圆帽与 LED 按钮的位置检查干涉和操作空间，不能只按编码器小 PCB 的轮廓安排两个控件，也不据此直接确定载板外形。

## RP2350-Zero 最终装配版本

用户提供了无预焊排针版本的正反面照片，并明确它与调试用板不同。本轮测量只记录这块实际装配板自身的尺寸，不计尚未安装的排针、排母或其他连接件。

### 官方尺寸图：主控封装与排母位置的依据

用户随后提供并明确优先采用[官方尺寸标注图](reference/rp2350-zero-official-dimensions.png)。后续主控封装、焊孔排列与排母位置按该图标注确定，不按照片像素比例估算，也不随此前实测外形尺寸缩放孔距。图示正面朝上、USB-C 在上，所有尺寸单位为 mm。

| 项目 | 官方图标注或据标注推算的值 |
| --- | --- |
| PCB 公称外形（长 × 宽） | 23.50 × 18.00 |
| 左右两排电气焊孔 | 每排 9 孔，孔距 2.54 |
| 左排孔中心距左板边 | 1.38 |
| 右排孔中心距右板边 | 1.38，由底边标注 3.92 − 2.54 推算 |
| 左右两排孔中心距 | 15.24，由 18.00 − 1.38 − 1.38 推算 |
| 最上方孔中心距上板边 | 1.59 |
| 同排首末孔中心距 | 20.32，由 8 × 2.54 推算 |
| 最下方孔中心距下板边 | 1.59，由 23.50 − 1.59 − 20.32 推算 |
| 底边两角孔之间的附加焊孔 | 5 孔，孔距 2.54 |
| 图示板角圆弧 | R1.00 |

按图中正面方向，各排信号顺序如下：

- 左排自上而下：5V、GND、3V3、GP29、GP28、GP27、GP26、GP15、GP14。
- 右排自上而下：GP0、GP1、GP2、GP3、GP4、GP5、GP6、GP7、GP8。
- 底边五个附加焊孔自左而右：GP13、GP12、GP11、GP10、GP9。

本项目使用的 GP2～GP5、3V3 和 GND 均位于左右两排，可采用两条 1×9、2.54 mm 间距的排针与排母，底边五孔可不焊排针。主控没有独立螺丝固定孔。v1.1 已据此创建两排插座封装并完成 PCB 绘制。

### 用户实测尺寸：装配参考与历史对照

此前实测板材外形为 24.01 × 18.01 mm，与图纸公称值分别保留。用户已指定主控封装以官方图为准，不将两套外形尺寸混用于孔位计算。

| 项目 | 数值（mm） |
| --- | ---: |
| PCB 板材长度（不含 USB-C 伸出部分） | 24.01 |
| 板宽（用户所报实测值） | 18.01 |
| 含 USB-C 伸出部分的总长 | 24.65 |
| USB-C 超出 PCB 板边的长度（24.65 − 24.01） | 0.64 |
| PCB 板厚 t | 1.01 |
| PCB 下表面到 USB Type-C 接口顶面 H | 4.29 |
| USB Type-C 接口高出 PCB 上表面（H − t） | 3.28 |
| PCB 下表面到背面最突出物末端 B | 1.01 |
| 背面最低点到 USB-C 顶面的整体高度（H + B） | 5.30 |

用户确认 24.01 mm 只量 PCB 板材，含 USB-C 的最长处为 24.65 mm。按这组实测长度相减，USB-C 伸出板边约 `24.65 - 24.01 = 0.64 mm`；该值仅作为实测对照，不将实测总长与官方图纸板长相减。USB 接口详细外形暂不追加测量，当前阶段不设计外壳开孔。

- 高度方向以带 USB-C、BOOT 和 RUN 按钮的一面为正面（用户提供的第二张照片）。
- 带 RP2350 芯片、晶振和其他贴片元件的一面为背面（用户提供的第一张照片）。
- `t = 1.01 mm`。用户确认正面最高部件为 USB Type-C 接口，`H = 4.29 mm` 包含板厚；接口顶面高于 PCB 上表面 `4.29 - 1.01 = 3.28 mm`。
- 用户提供 `B = 1.01 mm`，从背面的 PCB 板材表面量到背面最突出元件或焊点的末端。模块整体高度为 `4.29 + 1.01 = 5.30 mm`，不计尚未安装的连接件。
- 用户确认可自行焊接，采用主控焊排针、载板焊排母的插拔连接方式。按官方图使用两排 1×9、2.54 mm 间距连接件，两排中心距 15.24 mm；载板采用常规排母和公针，约 11 mm 板间距为背面元件提供空间，精确高度依实际选件而定。

### 无预焊排针主控的安装方法

用户说明主控需要通过 PCB 安装，且尚不清楚裸板焊孔如何固定。采用以下装配方式：

1. 在 RP2350-Zero 两侧各焊一条 1×9、2.54 mm 间距的公排针。USB-C/BOOT/RUN 面朝上，公排针短端穿过主控焊孔并焊牢，长端朝下用于插接；排针塑料定位条位于主控背面一侧。
2. 接线 PCB 上焊两条对应的 1×9 排母，两排中心距 15.24 mm。主控通过两排公针插入排母完成电气连接、定位和支撑；裸焊孔本身不作为插接触点。
3. 接线 PCB 预留其自身的外壳固定孔，后续用螺丝/支柱固定到壳体；这些孔不需要与主控或两个控件模块的孔位对应。
4. 外壳设计时为主控安排限位或压片，使 USB 插拔时主控不易随插头松脱。排针/排母提供支撑和可拆连接，最终抗拔固定由壳体结构配合完成。

通用连接件规格见装配说明，须给主控背面实测突出 1.01 mm 的元件留出空间，并检查焊接可达性。PCB 封装已创建；实物焊接尚未进行。

## 测量阶段记录：三个硬件的高度和位置

用户要求先测量、暂不建模或继续 EDA 绘制；随后确认机械装配由壳体解决，PCB 收窄为可插接/可焊线的接线板。已记录的控件机械数据保留供后续壳体设计使用，不再作为继续绘制接线板所需的额外测量任务。编码器轴心位置采用上述数值，不再追加该项测量。

三个模块统一以各自 **PCB 板材的下表面** 为高度基准，不以桌面、焊点底端或排针末端为基准：

- `t`：PCB 板材厚度。
- `H`：从 PCB 下表面到正面最高点的垂直距离。按钮保持未按下；编码器装好日常使用的圆帽。
- `B`：从 PCB 下表面到背面最突出物末端的垂直距离，包含伸到背面的焊点、元件或针脚。
- 正面最高点距 PCB 上表面的高度为 `H - t`；整体高度为 `H + B`。
- 编码器另测圆帽自身的轴向高度 `K`（底面到顶面）。装好后的圆帽下沿距 PCB 下表面为 `H - K`。

| 硬件 | 板厚 t（mm） | 正面最高点 H（mm） | 背面突出 B（mm） | 其他 |
| --- | --- | --- | --- | --- |
| LED 自锁开关 | 1.60 | 15.00 | 1.00 | 帽顶距 PCB 上表面 13.40；整体高度 16.00 |
| 旋转编码器（装上圆帽） | 1.78 | 33.97 | 2.41 | K = 18.07；帽顶距 PCB 上表面 32.19；帽下沿距 PCB 下表面 15.90；整体高度 36.38 |
| RP2350-Zero（无预焊排针） | 1.01 | 4.29（USB Type-C 接口） | 1.01 | 接口顶面高出 PCB 上表面 3.28；整体高度 5.30；不计调试板排针高度 |

三个模块的基础尺寸、高度和接口信息已足以开始初步布局规划。上述是模块自身尺寸；控件安装柱高度由外壳确定，主控排母规格见装配说明。基础测量阶段已结束，用户随后授权完成接线 PCB；外壳此后已按这些测量值设计，见 [hardware/enclosure](../enclosure/README.md)。

此前确定的接线板设计事项：按已记录的电气连接表安排主控排母、LED 三针和编码器五针接口，选定连接件型号并留插拔空间，再确定板框与布线。主控电气焊孔排列采用上述官方图，两种杜邦接口均已按实物配合确认采用 2.54 mm 间距，不重复要求测量这些数据。控件露出量、原模块安装孔和支架归入外壳设计，接线板不以这些机械尺寸为布线前提。这套设计事项已在 v1.1 中落地并下单组装。通用连接件规格与装配方法见 ASSEMBLY.md。

## 面板露出量与机械固定：外壳设计的输入

用户已明确目标方向：从外壳外表面沿垂直于模块 PCB 板面的方向量外露尺寸。按钮该向量长度保持 5.3 mm；旋钮在此前明确的 18.9 mm 基础上按用户要求增加 1 mm，更新为 19.9 mm。按板面法线方向记录，不按曲面或斜边路径长度解释，也不把外露量当作圆帽自身高度。以下安装深度计算采用面板与模块 PCB 平行，并沿用此前 H 所对应的未按压状态与控件外端；这两个几何计算前提不改变用户指定的外露目标。

用户补充：旋钮按压行程约 0.5 mm，LED 按钮按压行程约 1 mm。此前用户指出按钮侧面有马鞍面，并提供[实物侧面照片](reference/led-button-side-profile.jpg)；随后进一步确认按钮是方形、直上直下运动，没有阻碍。按钮按方形开口与直线按压处理，适配其实际最大外轮廓并留活动间隙，不需要额外设计贴合马鞍曲面的孔边，也不因此追加曲面测量任务。

建议分工：

- 旋钮：小模块通过既有安装孔固定到壳体专用支架，圆帽先按完整露在外侧考虑，轴穿过面板。只有确认螺纹段与面板的配合后，才能改用螺母夹持面板；目前不假定已有足够螺纹长度。
- LED 按钮：小模块通过既有安装孔固定到面板内侧支架，按所需露出量确定支架高度。按压力由机械支架承受，原配杜邦线只负责电气连接。
- 主控与电气连接板：主控插在排母上；连接板自身固定到壳体内部的合适位置，通过短线连两个控件。它不必位于两个控件正下方，也不承担两者的共同高度定位。

以下按用户指定外露目标推算安装位置，尚未包括制造公差或验证实际配合，不是最终生产尺寸。以面板外表面为共同基准，沿模块 PCB 法线计算：

| 量 | 目标与计算（mm） |
| --- | --- |
| 旋钮沿板面法线的目标外露量 | 19.90 |
| 旋钮帽底到面板的静止间隙 g | 19.90 − 18.07 = 1.83 |
| 旋钮按到底后的名义间隙 | 1.83 − 0.50 ≈ 1.33 |
| 编码器 PCB 下表面位于面板以下的深度 | 33.97 − 19.90 = 14.07 |
| 按钮沿板面法线的目标外露量 | 5.30 |
| 按钮按到底后的外露量 | 5.30 − 1.00 ≈ 4.30 |
| 按钮 PCB 下表面位于面板以下的深度 | 15.00 − 5.30 = 9.70 |
| 两个模块 PCB 下表面的高度差 | 按钮模块比编码器模块高 14.07 − 9.70 = 4.37 |

上述按钮安装计算沿用此前 H 的端点，交互剖面中的按钮外框仅表示占位范围，没有根据照片猜测帽子或开孔的具体长宽。示意采用 2 mm 面板厚度；实际面板材料、厚度、开口大小、支架与紧固件均未选定。旋钮增加 1 mm 外露量后，按到底的名义间隙约为 1.33 mm，比此前更充足；最终装配时仍需进行实际配合检查。这些结构关系已作为外壳设计的输入，实际外壳模型见 [hardware/enclosure](../enclosure/README.md)，其中 20° 斜面、内部固定柱与后部居中 USB-C 的具体尺寸以该目录为准。

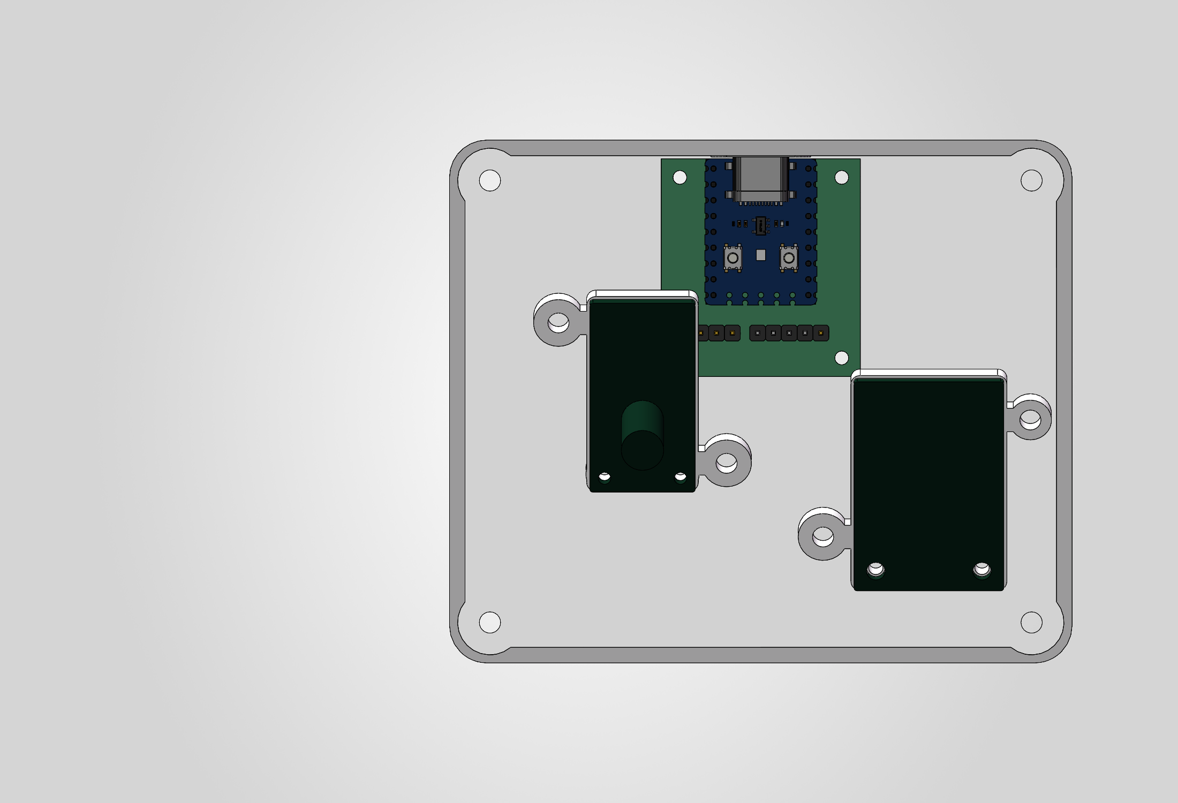
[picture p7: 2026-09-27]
hardware/enclosure/docs/ENCODER_REAR_LAYOUT.png

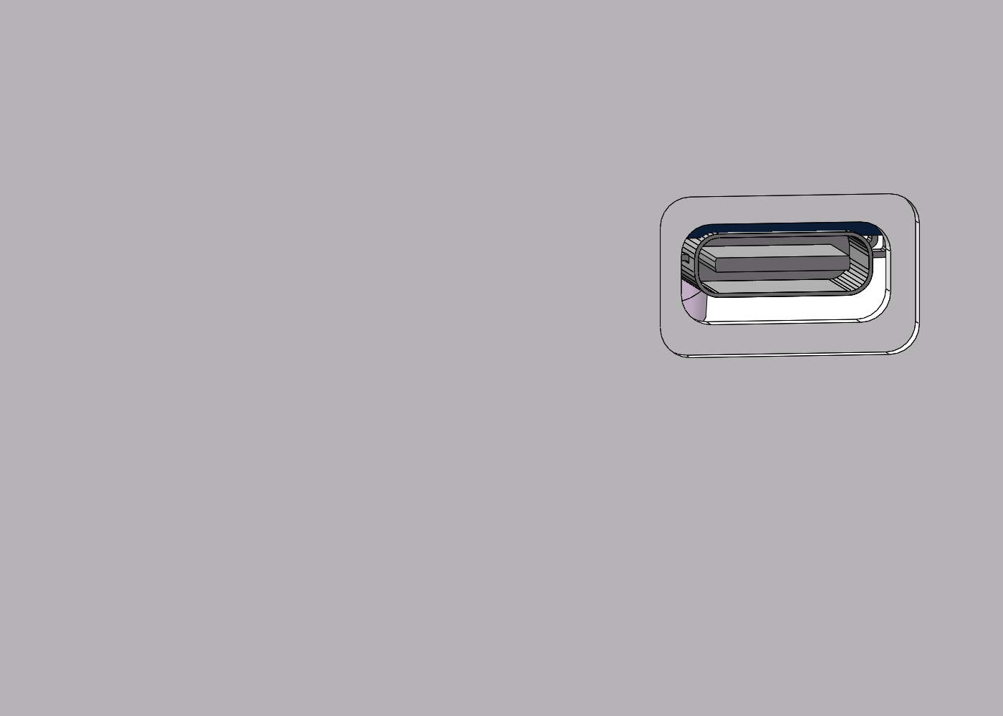
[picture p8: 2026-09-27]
hardware/enclosure/docs/USB_RECESS.png

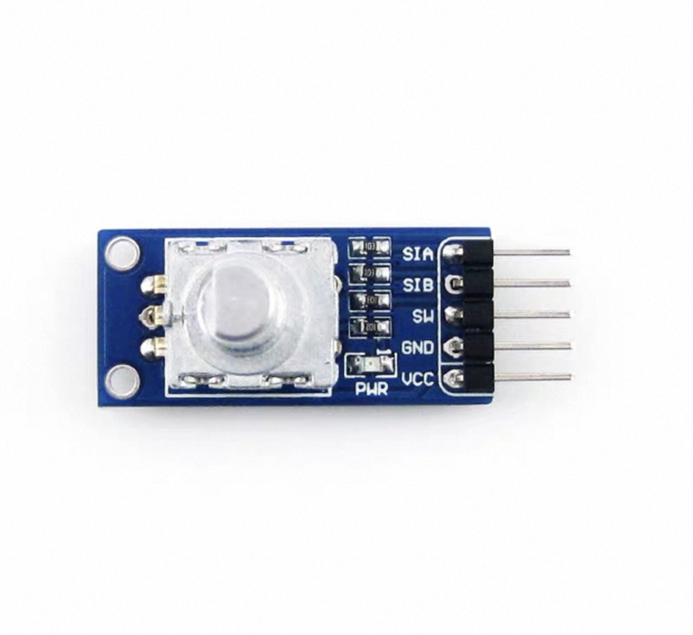
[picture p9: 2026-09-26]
hardware/pcb/reference/rotation.jpg

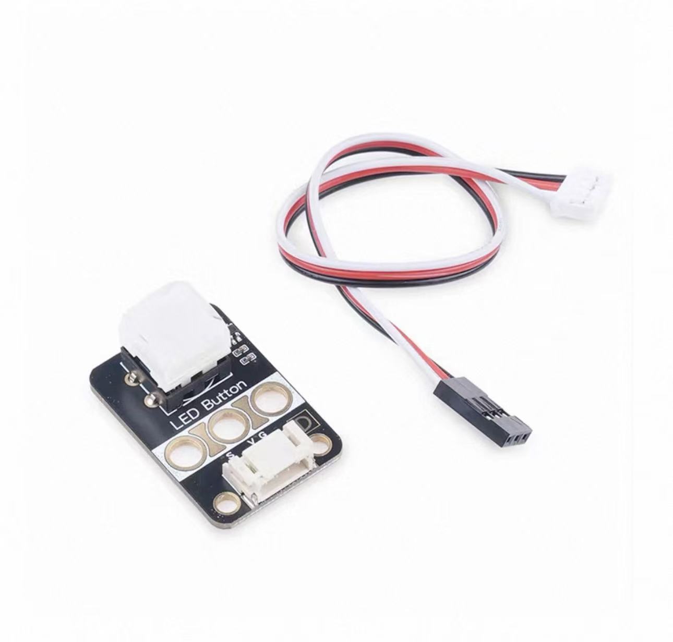
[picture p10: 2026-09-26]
hardware/pcb/reference/led-button-side-profile.jpg

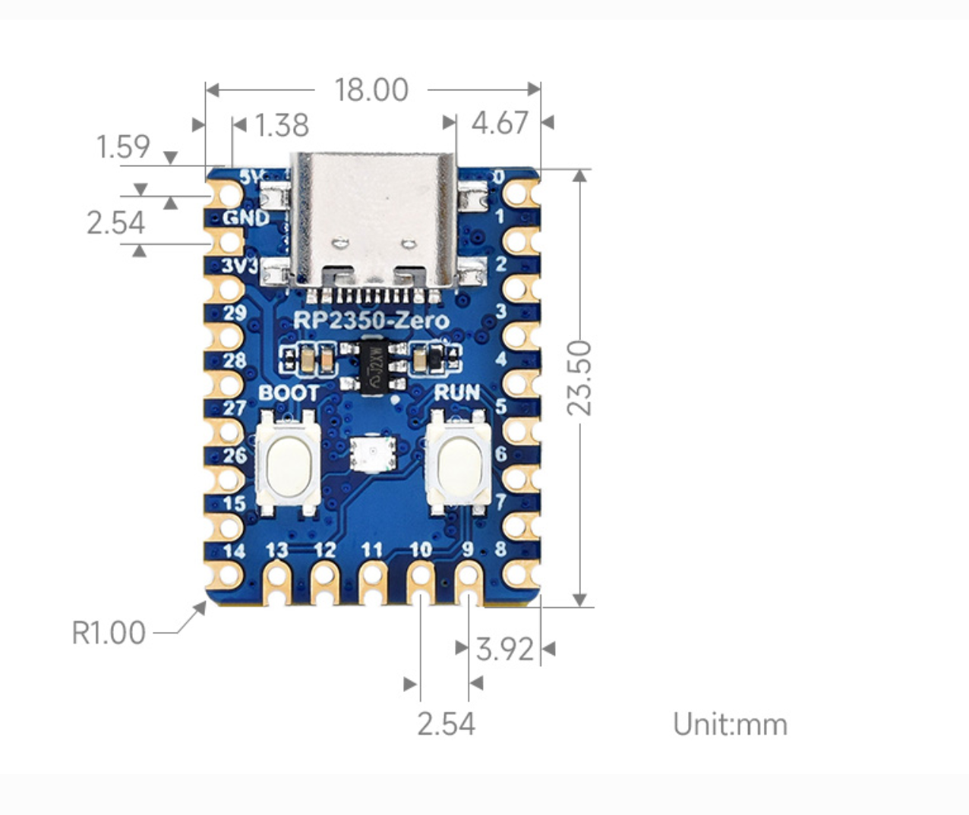
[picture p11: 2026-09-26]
hardware/pcb/reference/rp2350-zero-official-dimensions.png

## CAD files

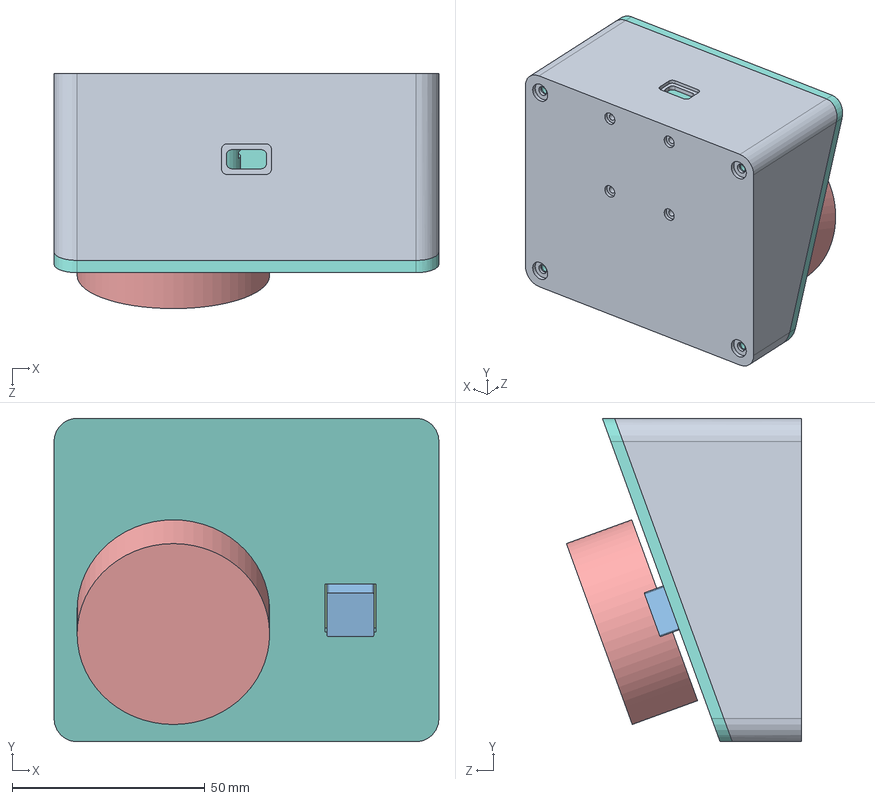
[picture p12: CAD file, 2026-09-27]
hardware/enclosure/cad/Music_Controller.SLDASM
100.0 x 84.0 x 61.1 mm
Base_Smooth_20deg
Lid_Smooth_20deg
REF_Carrier
REF_Encoder
REF_Knob
REF_Button_PCB
REF_Button_Cap
Button_Cradle
Encoder_Cradle

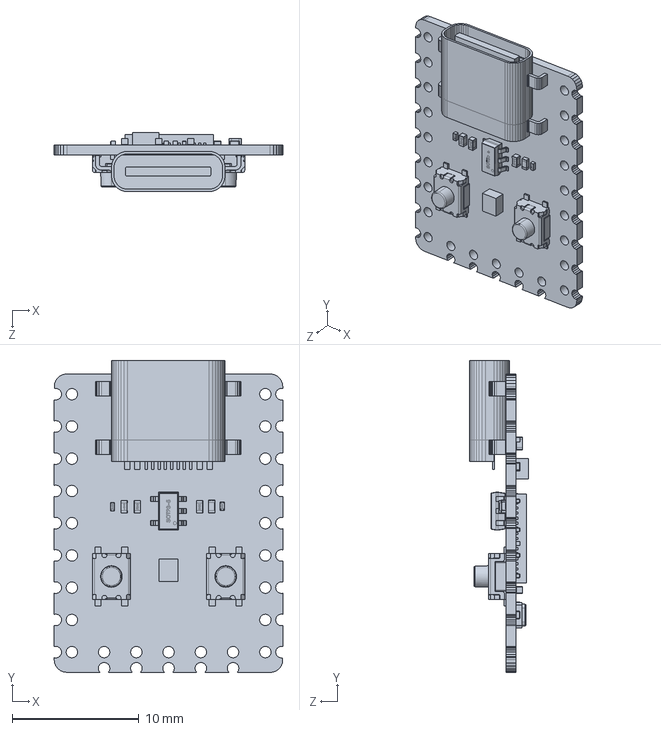
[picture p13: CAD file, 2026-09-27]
hardware/enclosure/cad/REF_RP2350_Official.SLDPRT
18.0 x 24.6 x 4.66 mm

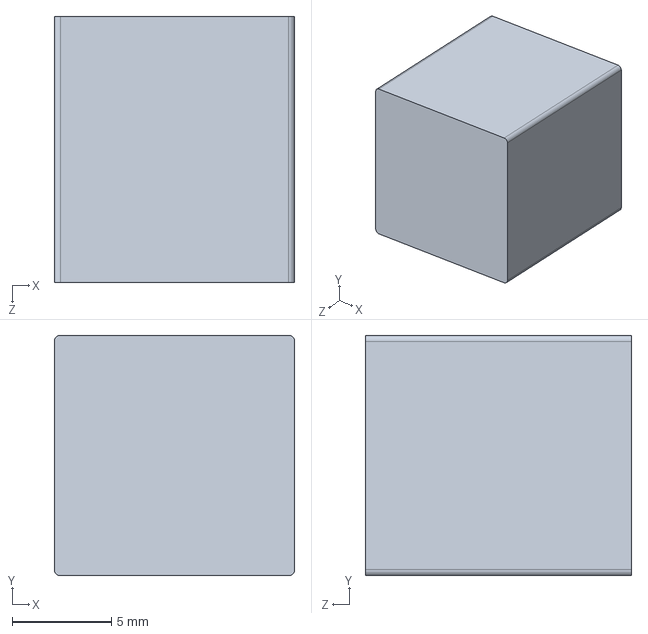
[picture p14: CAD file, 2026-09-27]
hardware/enclosure/cad/REF_Button_Cap.SLDPRT
12.1 x 12.1 x 13.4 mm

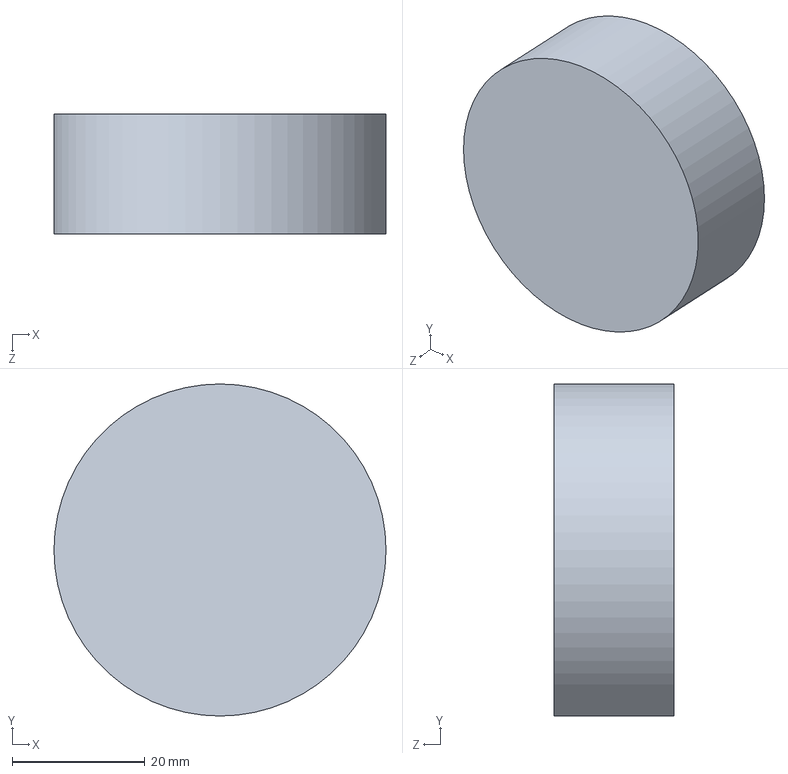
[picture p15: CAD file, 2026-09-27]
hardware/enclosure/cad/REF_Knob.SLDPRT
50.0 x 50.0 x 18.1 mm

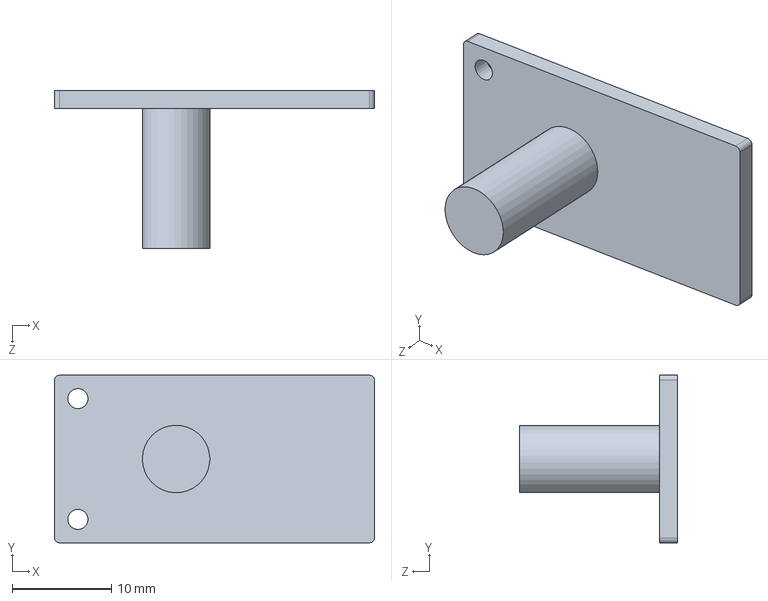
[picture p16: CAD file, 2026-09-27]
hardware/enclosure/cad/REF_Encoder.SLDPRT
32.3 x 16.9 x 15.9 mm

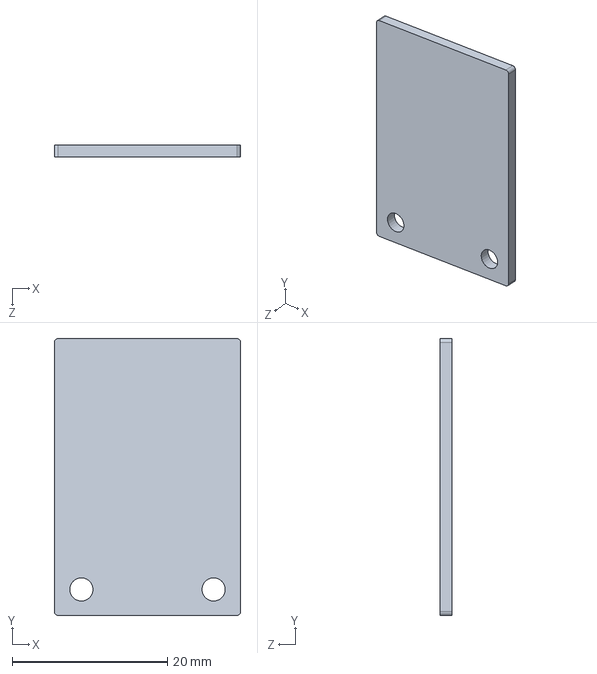
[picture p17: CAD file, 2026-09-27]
hardware/enclosure/cad/REF_Button_PCB.SLDPRT
24.0 x 35.7 x 1.60 mm

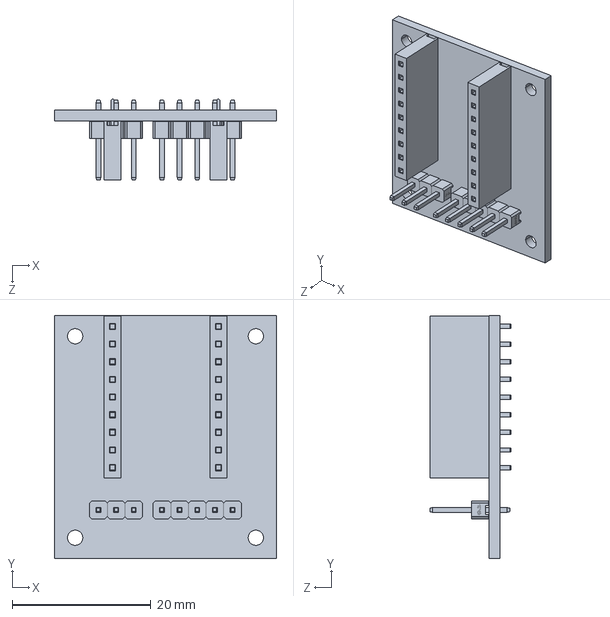
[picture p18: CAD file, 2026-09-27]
hardware/enclosure/cad/REF_Carrier.SLDPRT
32.0 x 35.0 x 11.7 mm

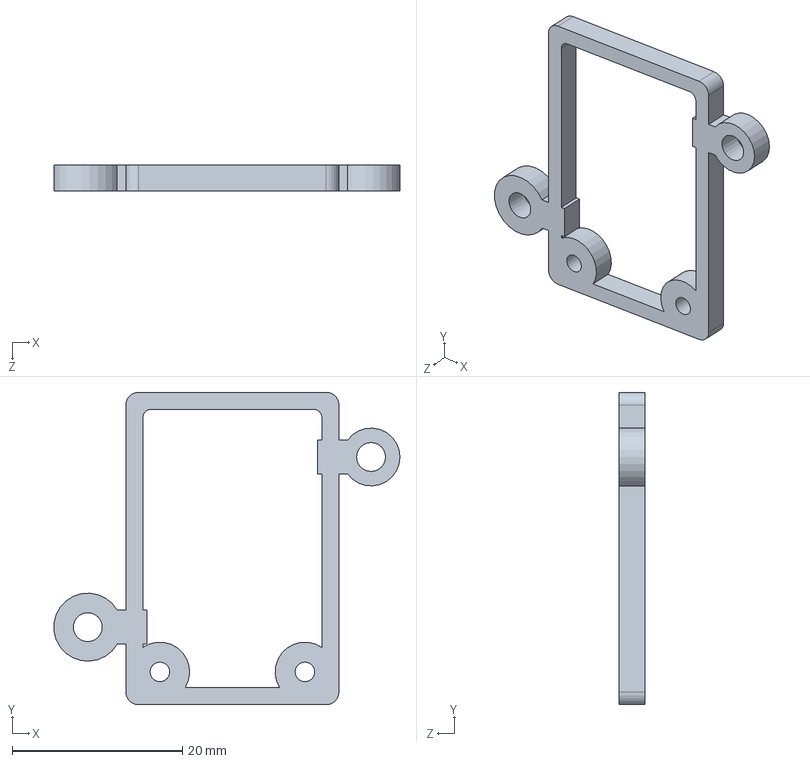
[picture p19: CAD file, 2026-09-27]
hardware/enclosure/cad/Button_Cradle.SLDPRT
40.7 x 36.7 x 3.00 mm

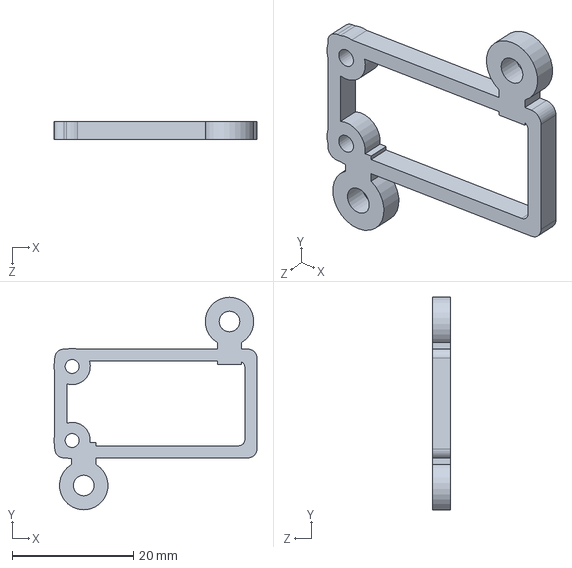
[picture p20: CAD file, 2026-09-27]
hardware/enclosure/cad/Encoder_Cradle.SLDPRT
33.4 x 35.0 x 3.00 mm

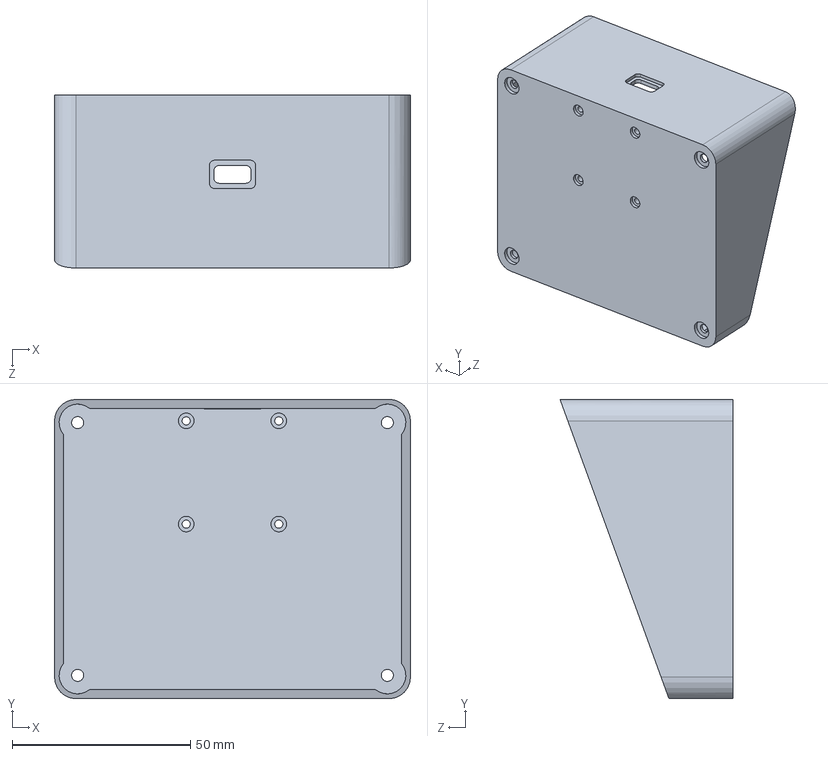
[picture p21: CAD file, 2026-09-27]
hardware/enclosure/cad/Base_Smooth_20deg.SLDPRT
100.0 x 84.0 x 48.6 mm

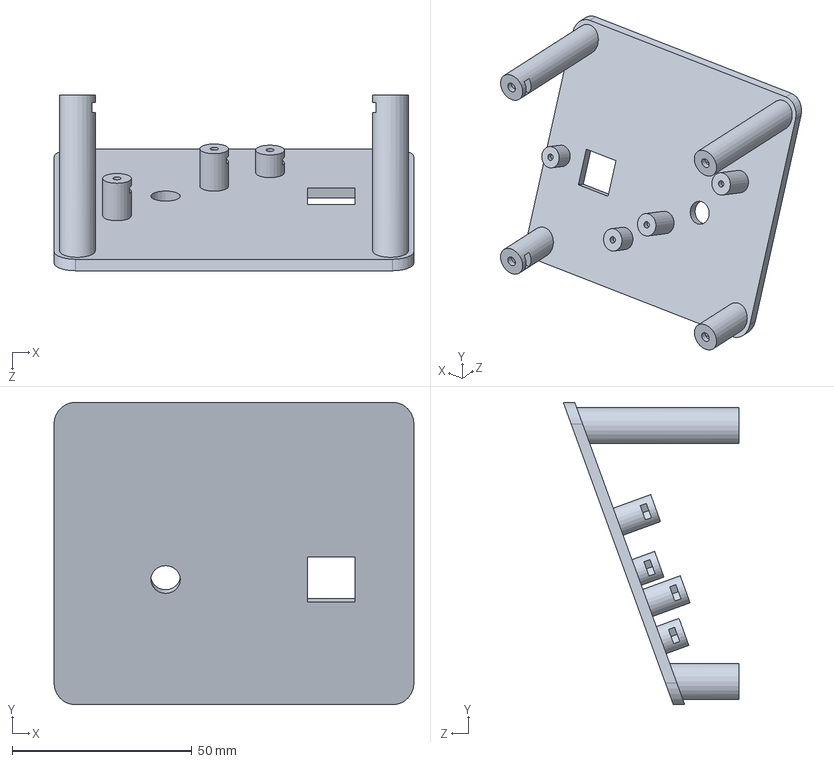
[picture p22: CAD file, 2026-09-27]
hardware/enclosure/cad/Lid_Smooth_20deg.SLDPRT
100.0 x 84.0 x 48.8 mm

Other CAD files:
hardware/enclosure/print/Base_Smooth_20deg.STL
hardware/enclosure/print/Button_Cradle.STL
hardware/enclosure/print/Encoder_Cradle.STL
hardware/enclosure/print/Lid_Smooth_20deg.STL

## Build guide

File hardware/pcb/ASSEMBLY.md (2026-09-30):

# 媒体控制器接线载板 v1.1

32 × 35 mm 的双层接线板。RP2350-Zero 插在载板上，按钮和编码器使用原配线束连接，两个控件由外壳单独支撑。板子已下单并完成焊接组装（2026-09-30）。

## 文件

- 可编辑工程：[kiro-media-controller-carrier-v1.1.eprj3](kiro-media-controller-carrier-v1.1/kiro-media-controller-carrier-v1.1.eprj3)。须保留同目录的 `sch`、`pcb` 和 `panel` 文件夹。
- 制板：通过嘉立创 EDA 一键下单，客户端自动上传生产文件；不需要手动导出或上传 ZIP，仓库也不保留制造 ZIP。
- 原理图和 PCB 预览直接在工程内查看，避免导出副本与手动修改后的工程不一致。

## 需要准备的连接件

| 安装位置 | 数量 | 规格 |
| --- | ---: | --- |
| 载板 J1、J2 | 2 条 | 1×9、2.54 mm 间距、直插单排排母，配合 0.64 mm 方针；采用常规约 8.5 mm 高塑壳款 |
| 主控左右两侧 | 2 条 | 1×9、2.54 mm 间距公排针，0.64 mm 方针；约 2.54 mm 塑料定位条、约 6 mm 插接端、约 3 mm 焊接端 |
| 载板 J3 | 1 条 | 1×3、2.54 mm 直插公排针，约 6 mm 插接端 |
| 载板 J4 | 1 条 | 1×5、2.54 mm 直插公排针，约 6 mm 插接端 |
| 载板固定 | 最多 4 组 | M2 螺丝/支柱，螺丝头或垫圈外径不超过 4.5 mm；长度按后续外壳确定 |

这些是连接件配合规格，未指定供应商品牌或料号。载板连接器焊孔为 1.05 mm，焊盘外径 1.9 mm。采购时核对所选连接件图纸满足上述间距、针径与塑壳尺寸。排母约 8.5 mm 高加公针定位条通常形成约 11 mm 的板间距离，最终高度以实际插合为准；主控背面突出 1.01 mm 的元件需保持悬空。

J3、J4 也可不装排针，直接把导线焊进同一组孔。保留原配线插接即可，不必剪线。

## 方向与接线

从载板有文字的一面看，`USB` 箭头朝上。主控的 USB-C、BOOT、RUN 一面朝上，USB-C 指向箭头。J1 在左，J2 在右。两排中心距 15.24 mm，纵向孔距 2.54 mm。

| 从 USB 端向下数 | J1 左排 | J2 右排 |
| ---: | --- | --- |
| 1（方焊盘） | 5V，本载板未接出 | GP0，未使用 |
| 2 | GND | GP1，未使用 |
| 3 | 3V3 | GP2 → LED S |
| 4 | GP29，未使用 | GP3 → SIA |
| 5 | GP28，未使用 | GP4 → SIB |
| 6 | GP27，未使用 | GP5 → SW |
| 7 | GP26，未使用 | GP6，未使用 |
| 8 | GP15，未使用 | GP7，未使用 |
| 9 | GP14，未使用 | GP8，未使用 |

主控底边另外五个孔不焊排针。不要把主控反面朝上或调转 USB 方向插入。

**J3 LED，从左到右：** `S — 3V3 — GND`，对应白线、红线、黑线。红线在中间，白线靠方焊盘。LED 模块端保留原来的带卡扣插头。

**J4 ENCODER，从左到右：** `A — B — SW — GND — 3V3`，分别对应模块的 `SIA — SIB — SW — GND — VCC`。A 靠方焊盘。以模块丝印确认每根线的去向。

模块或线束上的 `G` 和载板上的 `GND` 都表示地线，接线功能相同。

两种杜邦插头没有防反插结构，插之前对齐丝印；所有模块电源均来自主控的 3V3。当前固件的 GP2/3/4/5 分配保持不变。

## 焊接及首次使用

1. 将两条公排针的短端穿入主控左右两侧孔，塑料定位条位于主控背面，长端朝下。用两条排母暂时套住长端辅助保持平行，再焊主控。
2. 把排母插脚放入载板 J1/J2，确认主控 USB 朝箭头方向。每条先点焊一个脚，核对垂直和平齐，再完成其余焊点。避免长时间加热同一脚。
3. 装 J3/J4 排针，短端穿板焊接，长端朝上；或直接焊入对应导线。
4. 断电时检查焊锡桥；取下主控与模块，用万用表通断档确认 J1.3、J3.2、J4.5 连通，J1.2、J3.3、J4.4 连通，3V3 与 GND 不短路。
5. 插回主控和原配线束，通过主控 USB 供电。确认 LED 按钮、旋转方向和旋钮按压均与现有固件调试结果一致。

USB 插拔时扶住主控。两个控件由独立托架固定并承受按压力，载板通过四个固定孔锁在外壳内部，具体尺寸见 [hardware/enclosure](../enclosure/README.md)。

## 制板及固定尺寸

以下数值取自 v1.1 源工程。

- 2 层，FR-4，板厚 1.6 mm，外层铜厚 1 oz，常规阻焊/白色丝印；可选常规无铅喷锡。本设计全为通孔手焊，不需要钢网或贴片代工。
- 板外形 32 × 35 mm，板框为单一矩形，无内槽；Gerber 板框中心线给出精确外形。
- 26 个 1.05 mm 金属化连接器孔；4 个 2.20 mm 非金属化固定孔；无过孔。
- 原点为左上板角，X 向右、Y 向下。固定孔中心为 `(3,3)`、`(29,3)`、`(3,32)`、`(29,32)` mm，中心距 26 × 29 mm。
- 信号线 0.30 mm，全部走顶层；3V3/GND 线 0.50 mm，全部走底层。6 个网络（`3V3`、`GND`、`LED_SIG`、`ENC_SIA`、`ENC_SIB`、`ENC_SW`）均已布通。
- 板上有拼板工程 `panel/Panel1.epan2`。
- 文档层和钻孔图层用于参考；制板时由 EDA 上传包含实际钻孔数据的生产文件。

按钮外露 5.3 mm、旋钮外露 19.9 mm 及模块原孔位保留在 [测量记录](README.md)；外壳已按这些数据设计，当前模型和打印文件见 [hardware/enclosure](../enclosure/README.md)。

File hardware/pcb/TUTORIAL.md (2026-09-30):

# 从零画一块模块接线 PCB

以本项目的 RP2350-Zero 媒体控制器载板为练习。依据工程、接线表与嘉立创 EDA 专业版官方文档整理，适用于专业版 4.1.60。客户端版本不同，菜单位置可能略有变化。

目标是自己完成一块电气连接等效的板子。连接、孔位和装配方向必须正确，导线的每个拐弯不需要与 v1.1 相同。练习工程取名 `media-controller-practice`，正式工程作为对照。

本文尺寸、间距、线宽和坐标统一使用 **mm**；在 PCB 和封装编辑器中输入这些数值前，先将单位设为 **mm**。

**先认识设计过程。**

```mermaid
flowchart LR
  A[接线表<br/>哪几个脚相连] --> B[原理图<br/>表达电气连接]
  B --> C[符号与封装对应<br/>引脚号对应焊盘号]
  C --> D[PCB布局<br/>真实位置和尺寸]
  D --> E[布线与检查<br/>用铜连接焊盘]
  E --> F[一键下单<br/>上传生产文件]
```

原理图中两个器件相距多远，不决定实物上相距多远；PCB 中的尺寸才对应实物。原理图的导线告诉软件“应该相连”，PCB 的铜线负责实现连接。

**第 1 步：新建练习工程。**

1. 打开嘉立创 EDA 专业版，在开始页选择新建工程，名称填 `media-controller-practice`。也可使用顶部“新建 → 工程”入口；部分客户端在“文件”菜单内。
2. 如果询问保存位置，为练习工程选一个独立文件夹。
3. 展开左侧工程树。新工程通常已有一块板子，以及所属的原理图和 PCB。
4. 打开原理图下面的图页，通常名为 `P1`。如果已打开空白图页，就无需再建一页。
5. 保存工程。目录格式的工程需要保留整个目录，不能只保留 `.eprj3` 入口。

完成标志：标题是练习工程名，左侧能找到原理图和 PCB，中央是原理图画布。[官方：创建工程](https://prodocs.lceda.cn/cn/project/file-new-project/)

**第 2 步：先确定要焊的四个连接器。**

这块载板本身焊接的是连接器。RP2350-Zero、按钮模块、编码器模块都是现成的；练习图用连接器代表它们的接口。

| 位号 | 实物 | 数量 | 间距 |
| --- | --- | ---: | --- |
| J1 | 主控左侧 1×9 直插排母 | 1 | 2.54 mm |
| J2 | 主控右侧 1×9 直插排母 | 1 | 2.54 mm |
| J3 | LED 线束接口，1×3 直插公排针 | 1 | 2.54 mm |
| J4 | 编码器线束接口，1×5 直插公排针 | 1 | 2.54 mm |

点击“放置 → 器件”，也可按 `Shift+F`。分别搜索 `排母 1x9 2.54`、`排针 1x3 2.54`、`排针 1x5 2.54`；搜索不到时试 `1*9`、`1*3`、`1*5` 等写法。

挑选时看符号和封装预览：必须是单排、对应针数、2.54 mm、直插通孔。符号是原理图中的画法，封装是 PCB 上焊盘和外形的画法。只有名称相似还不够，要核对尺寸和编号。

放入两只 9 针、一只 3 针、一只 5 针器件。选中后在属性里将位号改为 J1～J4，备注分别写 `MCU LEFT`、`MCU RIGHT`、`LED`、`ENCODER`。原理图中先把 J1/J2 放左侧，J3/J4 放右侧，留出导线和名称的空间。

不要求搜索到与 v1.1 完全同名的自定义器件；使用尺寸和编号经过核对的通用连接器即可。[官方：放置器件](https://prodocs.lceda.cn/cn/schematic/place-device/)

完成标志：四个器件，合计 26 个引脚，每个器件都带封装。

**第 3 步：分清“第几脚”和“这个脚叫什么”。**

以实物正面朝上、USB 朝上为准，左右两排都从上向下编号 1～9。

| 引脚编号 | J1 左排对应主控脚 | J2 右排对应主控脚 |
| ---: | --- | --- |
| 1 | 5V，本项目不接 | GP0，不接 |
| 2 | GND | GP1，不接 |
| 3 | 3V3 | GP2 |
| 4 | GP29，不接 | GP3 |
| 5 | GP28，不接 | GP4 |
| 6 | GP27，不接 | GP5 |
| 7 | GP26，不接 | GP6，不接 |
| 8 | GP15，不接 | GP7，不接 |
| 9 | GP14，不接 | GP8，不接 |

J3 的 1、2、3 脚依次是 S、3V3、GND；J4 的 1～5 脚依次是 SIA、SIB、SW、GND、3V3。

例如 `J2.3` 表示“J2 的第 3 脚”，它对应主控的 **GP2**，不是 GP3。原理图中的 J2 第 3 脚最终必须映射到 PCB 中 J2 的 3 号焊盘。芯片 GPIO 名称与连接器引脚编号是两回事。[官方：引脚编号与焊盘编号](https://prodocs.lceda.cn/cn/symbol/side-panel-right-pin-property/)

**第 4 步：按这张表连接六个网络。**

“网络”就是应该导通的一组点。一个网络可以连接两个点，也可以像电源一样连接三个或更多点。

| 网络名称 | 主控连接器 | LED 连接器 | 编码器连接器 |
| --- | --- | --- | --- |
| `3V3` | J1.3 | J3.2 | J4.5 |
| `GND` | J1.2 | J3.3 | J4.4 |
| `LED_SIG` | J2.3（GP2） | J3.1 | — |
| `ENC_SIA` | J2.4（GP3） | — | J4.1 |
| `ENC_SIB` | J2.5（GP4） | — | J4.2 |
| `ENC_SW` | J2.6（GP5） | — | J4.3 |

先实际完成一条：

1. 点击“放置 → 导线”，从 J2 的 3 号引脚连接端画出一小段导线，结束绘制。
2. 用“放置 → 网络标签”给这段导线命名 `LED_SIG`。标签必须落在导线上；普通文本没有电气连接作用。
3. 从 J3 的 1 号引脚也画出短线，同样命名 `LED_SIG`。
4. 在同一图页内，这两段同名网络表示电气相连，不需要画一条横跨整页的长线。
5. 使用网络高亮或网络面板，确认这两个端点属于同一网络。

按同样方法完成其余五行。`3V3` 和 `GND` 各有三个端点，都使用一致的名称。模块上写 VCC、V 或 G，并不要求原理图也使用不同名称；本板统一使用 `3V3` 和 `GND`。

专业版中的网络标签会设置导线的名称属性；可以选中导线，在右侧属性中检查网络名。为便于第一次练习，全部连接放在同一图页，避免跨页作用域差异。[官方：网络标签](https://prodocs.lceda.cn/cn/schematic/place-net-label/)

剩余 12 个主控连接器引脚使用“放置 → 非连接标识”，表示“有意不接”。保留它们的物理焊盘，用于完整安装排母；不要把“不接”误理解为要删掉焊盘。

完成标志：6 个使用中的网络，3V3/GND 各 3 个端点，4 个信号网络各 2 个端点。主控 5V 不连接到这两块外设。

**第 5 步：检查原理图与封装映射。**

先执行“设计 → 检查 DRC”。点击检查结果逐项定位，常见问题包括导线没有落在引脚连接点、标签拼写不一致、遗漏非连接标识。不要靠关闭规则把提示藏起来。

打开“工具 → 封装管理器”，逐个核对：J1/J2 都有 1～9 号焊盘，J3 有 1～3，J4 有 1～5，并与符号编号一一对应。只在图旁写 `GP2` 文本，不能改变引脚的实际对应关系。

再人工对照第 4 步的六行接线表。DRC 能检查很多连接与规则问题，但不知道你的线束应当白线接 S、红线接 3V3，也不知道固件把哪个 GPIO 当作编码器输入。

把原理图上的接线表、说明和图框排好位置，避免与元件或导线重叠。可先把接线表放到图的下方，留出独立区域。

完成标志：没有未解决的电气错误，四个器件的符号引脚与封装焊盘对应正确。

**第 6 步：把原理图转换到 PCB。**

在原理图界面点击“设计 → 更新/转换原理图到 PCB”，查看变更列表并确认。进入 PCB 后应看到四个连接器和待连接的飞线。飞线只是提示，还不是工厂会制造的铜线。[官方：原理图更新到 PCB](https://prodocs.lceda.cn/cn/private/designer/design-schematic.html)

后面如要修改电气连接，先改原理图，再更新已有 PCB；更新前保存，检查变更列表。不要为了继续编辑而反复生成互不关联的新 PCB。

**第 7 步：设板框、图层和尺寸。**

把 PCB 显示单位切换为 **mm**。打开“工具 → 图层管理器”，点击左上角“铜箔层”数字右侧的下拉箭头，选择 **2**，再点“确认”。已经是 2 时保持原值；丝印、阻焊、板框等图层继续保留。

本教程后续所有坐标统一为：**左上板角 `(0,0)`，X 向右为正，Y 向上为正，板内 Y 使用负数，单位 mm。表内数值可直接填写，不需要再次取负。** 原点和坐标方向须先与此约定一致。

使用“放置 → 边框/板框”创建宽 **32**、高 **35** 的闭合矩形。板框几何中心是 **`(16.00, -17.50)`**；如果属性使用中心定位，填写这个中心和宽高。若属性使用角点，则四角为 `(0,0)`、`(32,0)`、`(32,-35)`、`(0,-35)`。必须是板框，丝印层上画一个矩形不能代替板框。[官方：板框](https://prodocs.lceda.cn/cn/pcb/place-board-outline/)

各类对象的坐标填写位置：元件表用于选中**整个连接器**后的元件位置；焊盘和安装孔表用于孔中心；文字表用于**对齐方式为“中心”**的文字中心。文字对齐方式不会改变连接器的封装原点。

| 项目 | 本板尺寸 |
| --- | --- |
| 连接器相邻孔中心距 | 2.54 mm |
| J1 与 J2 两排孔中心距 | 15.24 mm |
| 连接器焊孔 | 1.05 mm，金属化通孔 |
| 连接器铜焊盘尺寸 | 宽、高均为 1.90 mm，保留所选封装的焊盘形状 |
| 安装孔 | 2.20 mm，非金属化通孔 |
| 制造板厚 | 1.60 mm |

库里的通用封装可能使用不同孔径或铜环尺寸。若要复现本板，编辑练习工程使用的封装并核对以上尺寸。不同型号连接器仍应以实际厂家图纸为准，不能把这个孔径用于所有排针。

在 PCB/封装编辑中选中焊盘，确认右侧标题为“焊盘”。“图层”设为“多层”；“大小”中的宽、高都填 **1.90**；“钻孔属性”中的形状选“圆形”、直径填 **1.05**、“金属化”选“是”。每次输入后按 Enter 应用，保留焊盘编号和网络。连接器的全部 26 个焊盘都要核对。

直接在 PCB 中修改只作用于选中的焊盘，不会自动修改其他同型号元件。也可以右键元件选择“编辑封装”修改工程库模板，保存后核对同步范围。完成后重新核对全部焊盘的编号和间距。[官方：编辑工程封装](https://prodocs.lceda.cn/cn/pcb/place-device/)

板厚在“工具 → 图层管理器 → 物理堆叠”中查看。如果“当前堆叠厚度”已经是 **1.6 mm**，保持即可；需要修改时，在上方“板厚”输入 **1.6**，点击“自动分配基板厚度”，再点“确认”。实际下单时还要选择板厚 **1.6 mm**；物理堆叠设置不会替代订单参数。[官方：物理堆叠](https://prodocs.lceda.cn/cn/pcb/tools-layer-manager/)

**第 8 步：先放好连接器，再布线。**

先设置整个连接器的位置。点击连接器外框，确认右侧显示元件属性及其位号，再填写位置 X/Y 和旋转角度；如果右侧标题是“焊盘”，应重新选中整个元件。

下面的元件中心坐标适用于当前练习工程使用的封装：J1/J2 为 `HDR-TH_9P-P2.54-V-F-1`，J3 为 `HDR-TH_3P-P2.54-V-M-1`，J4 为 `HDR-TH_5P-P2.54-V-M-3`。这些封装的原点位于中间焊盘附近：J1/J2 的 5 号、J3 的 2 号、J4 的 3 号。J4 库坐标存在小于 0.0001 mm 的舍入偏差，以下按 0.01 mm 给出。

| 整个元件 | 中心 X | 中心 Y | 旋转角度 | 放置后方向 |
| --- | ---: | ---: | ---: | --- |
| J1 左排 | 8.38 | -11.75 | -90°（等同 270°） | 1 号在上，9 号在下 |
| J2 右排 | 23.62 | -11.75 | -90°（等同 270°） | 1 号在上，9 号在下 |
| J3 LED | 8.89 | -28.00 | 0° | 1 号在左，3 号在右 |
| J4 ENCODER | 20.57 | -28.00 | 0° | 1 号在左，5 号在右 |

更换封装后，原点和初始方向可能不同，需要重新换算元件位置。下面的孔中心位置是最终核对依据。**移动整只连接器时使用上表，下面的焊盘表用于核对孔位。**

**J1/J2 黄色丝印框与板框重叠时，先核对丝印尺寸。** 当前通用排母封装的丝印框沿 9 个孔排列方向长约 **23.36 mm**、线宽 **0.254 mm**；示例对应长度为 **23.02 mm**、线宽约 **0.152 mm**。两者的 1 号孔中心都距板顶 **1.59 mm**，但通用封装的上边线中心距板顶仅约 **0.07 mm**，加上线宽后会越过板边。示例上边线中心距板顶 **0.24 mm**，因此能看到间隙。

保留上表中的元件位置和所有焊盘位置，将黄色丝印框调整为下面的尺寸：

1. 在 PCB 中右键 J1，选择“编辑封装”，进入工程封装编辑器。当前库封装在此处的 9 个孔为水平排列，原点在第 5 孔。
2. 选择**顶层丝印层**上的四条外框线，将线宽设为 **0.152 mm**。这个库的框由四条线组成；线宽保留三位小数即可。
3. 按下表调整四条线的端点，使矩形中心为 `(0,0)`，横向长 **23.02 mm**、纵向宽 **2.50 mm**。端点坐标属于**封装局部坐标**，只用于这四条丝印线。
4. 保存后回到 PCB，检查 J1/J2 都已同步。PCB 上的竖框中心仍为 `(8.38,-11.75)`、`(23.62,-11.75)`，宽 **2.50 mm**、高 **23.02 mm**；上边线中心 Y 为 **-0.24 mm**。这里调整的是印刷外框，实际塑壳外形仍按实物和厂家尺寸核对。[官方：编辑工程封装](https://prodocs.lceda.cn/cn/pcb/place-device/)

| 封装编辑器中的丝印线 | 起点 X | 起点 Y | 终点 X | 终点 Y |
| --- | ---: | ---: | ---: | ---: |
| 上侧长边 | -11.51 | 1.25 | 11.51 | 1.25 |
| 下侧长边 | -11.51 | -1.25 | 11.51 | -1.25 |
| 左端短边 | -11.51 | -1.25 | -11.51 | 1.25 |
| 右端短边 | 11.51 | -1.25 | 11.51 | 1.25 |

J1/J2 的全部孔中心：

| 焊盘号 | J1 中心 X | J1 中心 Y | J2 中心 X | J2 中心 Y |
| ---: | ---: | ---: | ---: | ---: |
| 1 | 8.38 | -1.59 | 23.62 | -1.59 |
| 2 | 8.38 | -4.13 | 23.62 | -4.13 |
| 3 | 8.38 | -6.67 | 23.62 | -6.67 |
| 4 | 8.38 | -9.21 | 23.62 | -9.21 |
| 5 | 8.38 | -11.75 | 23.62 | -11.75 |
| 6 | 8.38 | -14.29 | 23.62 | -14.29 |
| 7 | 8.38 | -16.83 | 23.62 | -16.83 |
| 8 | 8.38 | -19.37 | 23.62 | -19.37 |
| 9 | 8.38 | -21.91 | 23.62 | -21.91 |

J3/J4 的全部孔中心：

| 焊盘 | 中心 X | 中心 Y |
| --- | ---: | ---: |
| J3.1 | 6.35 | -28.00 |
| J3.2 | 8.89 | -28.00 |
| J3.3 | 11.43 | -28.00 |
| J4.1 | 15.49 | -28.00 |
| J4.2 | 18.03 | -28.00 |
| J4.3 | 20.57 | -28.00 |
| J4.4 | 23.11 | -28.00 |
| J4.5 | 25.65 | -28.00 |

核对 J1/J2 排距为 `23.62 − 8.38 = 15.24 mm`，相邻孔中心距为 **2.54 mm**。第 9 孔 Y 为 `-1.59 − 8 × 2.54 = -21.91 mm`。J3/J4 位于下方，给两种线束留出插拔空间。以 J1/J2 孔位为基准，核对主控外形约 **18 × 23.5 mm**，USB 朝上；主控底边五个额外焊孔不在本次插座内。

接着添加四个安装孔。点击“放置 → 焊盘”，在空白处放置后按 Esc 退出，选中该焊盘设置：图层为“多层”，网络留空，大小形状为“圆形”、宽高均为 **2.20**，钻孔形状为“圆形”、直径为 **2.20**，**金属化为“否”**。外径与孔径相同，确认没有额外的导电铜环。复制或继续放置到四个，再逐个填写中心坐标并核对金属化属性。[官方：焊盘](https://prodocs.lceda.cn/cn/pcb/place-pad/)

为与示例一致，选中每个安装孔，展开右侧“阻焊/助焊扩展”，将**顶层阻焊扩展、底层阻焊扩展都自定义为 `0 mm`**。本练习的默认焊盘规则为每侧扩展约 **0.051 mm**；若保持“通用/跟随规则”，2.20 mm 孔周围会显示直径约 **2.30 mm** 的阻焊开窗，形成一圈紫色。示例设为 0，开窗边界与孔边重合，因此看不到孔外的紫圈。紫色表示阻焊开窗；孔壁是否金属化仍由“金属化”属性决定。这项自定义只用于四个安装孔，连接器焊盘继续按第 7 步设置。[官方：阻焊扩展规则](https://prodocs.lceda.cn/cn/pcb/design-design-rule/)

| 安装孔 | 中心 X | 中心 Y | 孔径 | 金属化 |
| --- | ---: | ---: | ---: | --- |
| 左上 | 3.00 | -3.00 | 2.20 | 否 |
| 右上 | 29.00 | -3.00 | 2.20 | 否 |
| 左下 | 3.00 | -32.00 | 2.20 | 否 |
| 右下 | 29.00 | -32.00 | 2.20 | 否 |

安装孔内显示的编号是编辑器标记，不会自动成为成品丝印文字。也可使用核对过尺寸的 NPTH 安装孔封装。

这些安装孔固定的是载板。LED/编码器模块仍由外壳支撑。螺丝头/垫圈外径按不超过 4.5 mm 考虑，周围给铜和元件留空间。

**示例安装孔外面的白圈是螺丝头/垫圈占位参考。** 中心实际钻孔直径为 **2.20 mm**；白圈直径为 **4.50 mm**，画在**文档层**，线宽 **0.10 mm**，与安装孔同心。白圈不增加钻孔或铜环，不印到成品，也不会自动禁止铜线或元件进入。

需要画同样的白圈时，选择文档层，用圆形工具绘制四个空心圆，圆心分别填写上面安装孔表的四组坐标；直径填 **4.50**（如果属性显示半径，则填 **2.25**），线宽填 **0.10**。用这些圈检查螺丝头/垫圈是否挤到元件或压到裸露焊盘，实际采用其他尺寸的螺丝头/垫圈时按实物调整参考范围。

尺寸最终用测量工具复核；能打印时，以 100% 实际尺寸打印焊孔图，并核对打印比例后用实物排针对孔。3D 预览不能代替孔距测量。

可在文档层画主控小板的外形参考，帮助检查放置位置。本工程二维视图中的白框就是这个参考；黄色窄框位于顶层丝印层，是两条排母的轮廓。两者代表不同物体，边缘不需要重合。文档层参考框不印到成品板上，黄色丝印在白色字符工艺下会印成白色。核对装配时看焊孔中心距和主控方向，不要为了让两个框重合而移动排母。图层名称比显示颜色更可靠。

完成标志：26 个连接器孔、4 个安装孔；J1/J2 排距 15.24 mm；主控方向与线束针序正确。

**第 9 步：把飞线变成铜线。**

在“设计 → 设计规则”里查看工厂常规两层板规则，练习时启用实时检查。对这块低速、小电流载板，采用下列练习值：信号线宽 0.30 mm，3V3/GND 线宽 0.50 mm；不同网络铜间距至少 0.25 mm，铜到板边至少 0.40 mm。这里的间距是本练习取值，不是复述 v1.1 所有默认规则，更不是所有电路的通用参数。[官方：设计规则](https://prodocs.lceda.cn/cn/pcb/design-design-rule/)

从最容易的一条开始：

1. 选择顶层，使用“布线 → 单路布线”。
2. 从 J2.3 焊盘起线，确认当前网络是 `LED_SIG`，线宽为 0.30 mm。
3. 沿空白区域走到 J3.1 的铜焊盘上，结束布线。转弯先用 45°，路线清楚即可。
4. 看这两个点之间的飞线是否消失；选中铜线，检查它仍属于 `LED_SIG`。
5. 继续完成 `ENC_SIA`、`ENC_SIB`、`ENC_SW`，遇到挡路可移动拐点或重新规划路径。
6. 选择底层，以 0.50 mm 连接 3V3 的三个焊盘，再连接 GND 的三个焊盘。

v1.1 的四个信号网络走顶层，电源和地走底层，没有过孔，也没有铺铜。所有接口是金属化通孔焊盘，本身可以连接顶底两层，所以可以分别从同一个焊盘的顶层或底层出线。

两根线在不同铜层上投影相交，不会自动导通；同层不同网络碰在一起会短路。不能只在空白处切换层，就认为两个铜层之间已经连上；途中换层需要过孔，本练习优先通过调整路径完成。

3V3/GND 每个网络是三个点，连完其中两个还不算完成。也不要把飞线隐藏，当成已经连完。

完成标志：所有要求的连接都已布通，未布线连接数为 0；没有短路或线间距错误。

**第 10 步：加上装配时看得懂的文字。**

每个接口都标完整，未使用的主控脚也标出名称。丝印只说明这个位置对应哪个脚；例如写上 `5V`，不会把原本未接出的 5V 焊盘连接到外设。

先实际放置一个标签，以 J2 最下方的 `GP8` 为例：

1. 在 PCB 中把单位切换为 **mm**，选择 **顶层丝印层**，不要选成顶层铜、阻焊或锡膏层。
2. 使用工具栏的文本工具，在目标焊盘旁边放置文字，然后退出放置状态。
3. 选中文字，打开右侧“属性”。内容填 `GP8`，核对图层为顶层丝印层、旋转角度为 0、镜像为“否”。字体使用默认字体，**对齐方式选“中心”**（水平和垂直都居中）；先设置对齐方式，再填写坐标。
4. 按本板样式，主控针脚文字高度为 **0.75 mm**，线宽为 **0.152 mm**。J3/J4 的针脚文字高度为 0.78 mm。复制现有标签再改内容和坐标，可以保持样式一致。
5. 在“中心 X / 中心 Y”中填位置，`GP8` 填 **X = 26.22、Y = -21.91**。输入后按 Enter 应用，再确认文字确实移动到对应孔旁。下面所有文字表都使用同样的中心对齐和坐标方向。
6. 保存工程，在二维和三维预览中检查标签内容、位置和可读性。

不要一次输入一整列名字再用空格或换行凑位置。每个针脚用一个独立文字对象，文字中心与对应焊盘中心处于同一水平线。

J1/J2 的 18 个针脚文字坐标如下，取自正式板。每一行放两个独立文本；所有文本对齐方式为“中心”、高度 **0.75**、线宽 **0.152**、角度 **0°**。左右两列的 Y 不完全相同，按表逐格填写：

| 焊盘号 | J1 文字 | J1 中心 X | J1 中心 Y | J2 文字 | J2 中心 X | J2 中心 Y |
| ---: | --- | ---: | ---: | --- | ---: | ---: |
| 1 | `5V` | 10.67 | -1.65 | `GP0` | 21.08 | -1.65 |
| 2 | `GND` | 10.92 | -4.19 | `GP1` | 21.08 | -4.00 |
| 3 | `3V3` | 5.71 | -6.73 | `GP2` | 26.22 | -6.67 |
| 4 | `GP29` | 5.40 | -9.34 | `GP3` | 26.22 | -9.21 |
| 5 | `GP28` | 5.40 | -11.88 | `GP4` | 26.22 | -11.75 |
| 6 | `GP27` | 5.40 | -14.42 | `GP5` | 26.22 | -14.29 |
| 7 | `GP26` | 5.40 | -16.96 | `GP6` | 26.22 | -16.83 |
| 8 | `GP15` | 5.40 | -19.50 | `GP7` | 26.22 | -19.37 |
| 9 | `GP14` | 5.40 | -22.04 | `GP8` | 26.22 | -21.91 |

第 1、2 脚文字位于孔排内侧，避开顶部安装孔和螺丝头空间；第 3～9 脚文字位于外侧。外侧文字到孔排中心的距离左右并不相同（左列约 2.98 mm、右列约 2.60 mm），正式板是按“让开黄色丝印框”逐格摆放的，不追求左右对称。

顶部四个标签在主控插上后可能被遮住，用于插装前核对。其余标签保持在外侧。不同名字的字数不同，应按文字中心对齐，而不是比较文字最左或最右的一笔。

J3/J4 按 1 号到末号的顺序，在每个焊盘正下方放一个独立标签。全部对齐方式为“中心”、高度 **0.78**、线宽 **0.152**、角度 **0°**：

| 对应焊盘 | 文字 | 文字中心 X | 文字中心 Y |
| --- | --- | ---: | ---: |
| J3.1 | `S` | 6.35 | -30.47 |
| J3.2 | `3V3` | 8.89 | -30.47 |
| J3.3 | `GND` | 11.43 | -30.47 |
| J4.1 | `SIA` | 15.49 | -30.47 |
| J4.2 | `SIB` | 18.03 | -30.47 |
| J4.3 | `SW` | 20.57 | -30.47 |
| J4.4 | `GND` | 23.11 | -30.47 |
| J4.5 | `3V3` | 25.65 | -30.47 |

编码器两路相位在板上直接写模块丝印名 `SIA`/`SIB`，不缩写成 `A`/`B`。地线统一写为 `GND`；模块或线束上的 `G` 也表示地线。

接口标题、USB 方向、板名和版本号按正式板使用下面这组内容和位置。全部放在顶层丝印层，**对齐方式为“中心”**、角度 **0°**、镜像为“否”、线宽 **0.152**：

| 文字内容 | 文字中心 X | 文字中心 Y | 字高 |
| --- | ---: | ---: | ---: |
| `LED-BTN` | 10.67 | -26.03 | 1.00 |
| `ENCODER` | 24.76 | -26.03 | 1.00 |
| `USB` | 16.00 | -1.17 | 1.10 |
| `USB THIS END` | 16.00 | -4.87 | 0.80 |
| `RP2350-ZERO` | 16.26 | -10.54 | 1.20 |
| `3V3 ONLY` | 16.00 | -19.81 | 0.80 |
| `15.24 mm` | 16.00 | -20.67 | 0.80 |
| `KIRO MEDIA CTRL v1.1` | 16.64 | -33.40 | 1.00 |

`USB` 与 `USB THIS END` 之间还有一个朝上的箭头，用丝印层线段画，指向板顶的 USB 方向。`J1`～`J4` 是元件位号，由软件自动显示，位置可单独调整；接口说明用上面的 `LED-BTN`、`ENCODER` 两个独立文本，不与位号重复。板名和版本号合成一条 `KIRO MEDIA CTRL v1.1`，版本号按实际工程版本填写。正式板的二维视图见 [pcb.png](../../docs/ref/pcb.png)，三维见 [pcb-3d.png](../../docs/ref/pcb-3d.png)。

文字不要压到焊盘开窗、固定孔或其他文字，也要考虑连接器塑壳和螺丝头遮挡；改变字体、字高或文字内容后重新检查。丝印不会导电；把网络名字写在丝印上，不会替你完成电气连接。

完成标志：J1/J2 共 18 个针脚、J3/J4 共 8 个针脚都有对应标签；左右间距一致；拿着板子能判断 USB 朝向、白/红/黑线和编码器线序。

**第 11 步：制造前做两类检查。**

先执行 PCB 的“设计 → 检查 DRC”，逐条处理短路、未连接、间距、铜到板边、孔距和丝印等问题。检查完成后，再打开 2D/3D 预览检查方向与可见的机械冲突。

区分 DRC 结果和 3D 模型提示：如果预览提示 J1～J4“未绑定 3D 模型”，表示所选连接器没有立体外形，预览只有板子和焊盘，不能据此检查塑壳的实际遮挡。这不影响已定义焊盘的制板数据。需要完整装配预览时，绑定尺寸匹配的排针/排母模型；短路、未连接等 DRC 问题仍需单独解决。

然后用自己的接线表复核实际设计：

| 检查对象 | 应该看到的结果 |
| --- | --- |
| 3V3 网络高亮 | J1.3、J3.2、J4.5 |
| GND 网络高亮 | J1.2、J3.3、J4.4 |
| 四路信号 | 与第 4 步的表一一对应 |
| 主控安装 | 两排 1×9、排距 15.24、USB 向上 |
| 固定孔 | 4 个、2.2 mm、非金属化 |
| 孔/焊盘总数 | 26 个连接器通孔，加 4 个固定孔 |
| 板框 | 闭合、32 × 35 mm |
| 针脚丝印 | 26 个针脚均有标签，与第 3 步的引脚表逐一对应 |
| 预览 | 丝印完整、方向正确，文字不压焊盘开窗或固定孔 |

DRC 通过表示通过已启用规则的检查，不等于固件脚位、线序和机械配合一定正确。完成软件检查后，还需按第 12 步验证实物。

**第 12 步：保存、一键下单和验证实物。**

1. 保存原理图和 PCB。
2. 在 PCB 界面点击“PCB/FPC 下单”，由嘉立创 EDA 自动上传生产文件，再到跳转的订单页面继续，不需要手动导出或上传 ZIP。
3. 提交前核对订单页面的文件预览。若修改了铜线、孔位或丝印，先保存并重新检查，再从当前 PCB 发起下单；已有订单不会随本地编辑自动更新。
4. 一键下单时核对文件预览和参数：32 × 35 mm、两层 FR-4、1.6 mm、1 oz、单片出货。本板是手焊通孔连接器，不需要 SMT 和钢网。按本项目的制板参数，表面处理选 OSP；价格和促销以当时页面为准。重点核对预览中的针脚文字、板框和钻孔是否与保存的工程一致。
5. 工程目录纳入 Git，正式下单版本通过提交或标签记录；对应的生产资料按订单留存，便于以后知道制造的是哪一版。
6. 收到板子，先对孔、焊接，再在断电且主控/模块取下时检查连通性和 3V3/GND 是否短路，最后插上模块进行功能测试。具体焊接步骤见 [装配说明](ASSEMBLY.md)。

**下次换一个模块时，先回答五个问题。**

1. 模块供电电压、信号电平、电流是否与主控兼容？已有模块是否已经包含需要的外围电路？
2. 每个信号接哪一个 GPIO，固件是否与接线一致？
3. 实际插头是公头还是母头，针数、间距、编号方向是什么？
4. 哪些位置必须固定，哪些接口需要留出插拔空间？
5. 软件检查和实物检查分别如何证明连接正确？

学会这条流程后，就能把已经验证过的低速模块接线做成转接板。电压转换、电源变换、大电流或高速接口需要另行计算与设计，不能只复制连接器和本板线宽。

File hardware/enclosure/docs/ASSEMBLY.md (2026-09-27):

# 音乐控制器外壳 · 平整面板版

2026-09-27；长度单位均为 mm。桌面操作面前低后高，倾角 20°。这是待实物试装的可打印样件。

## 文件

打开 `../cad/Music_Controller.SLDASM` 查看整机。

打印 `../print` 中的四件：`Base_Smooth_20deg` 底壳、`Lid_Smooth_20deg` 上盖、`Encoder_Cradle` 编码器托架、`Button_Cradle` 按钮托架。不要打印 `REF_` 开头的电子器件参考件。

本目录只保留当前平整面板版。

## 此次修改

- 上盖外表面平整，只留编码器轴孔和按钮开口；四角凸台、正面安装螺丝孔取消。
- 四颗外壳螺丝改从底部旋入上盖内部柱子里的侧装螺母。
- 两个控制模块先固定在独立托架上，再从内部装到上盖盲孔柱。面板正面不穿螺丝。
- 编码器及原托架绕轴心旋转 90°，排针朝后；上盖内两根对应固定柱、螺丝孔、螺母槽随之移位。旋钮中心及按钮位置不变。
- 修复打印厂指出的螺母槽薄壁：八个槽改为六角封闭端，右侧按钮固定柱从 Ø6.8 加粗至 Ø7.6；轴孔、按钮开口、螺丝孔中心不变。
- 上盖使用中性灰默认外观。软件颜色不指定实际打印材料颜色。
- 载板及主控移至后部中间，USB-C 开口中心 X=50。USB-C、RUN、BOOT 所在面朝上，接口朝后。
- 主控用微雪官方 RP2350-Zero STEP 参考模型替换简单占位块。
- 根据打印厂薄壁反馈及外观要求，USB-C 改为圆角内凹结构：外槽 13 × 8、深 1.2，内孔 10.5 × 5；槽底厚 1.5，取代原 0.5 厚薄边。主后壁保持 2.5 厚。

## 外形与位置

| 项目 | 数值 |
|---|---:|
| 外壳宽 × 深 | 100 × 84 |
| 外轮廓圆角 | R6 |
| 前缘／后缘面板外表面高度 | 21.193／51.766 |
| 壁厚／底厚／面板法向厚度 | 2.5／2.5／3 |
| 按钮开口 | 13.3 × 13.3 |
| 编码器轴孔 | Ø8.2 |
| USB-C 包胶避让外槽（宽 × 高） | 13 × 8，R1.5，深 1.2 |
| USB-C 槽底内孔（宽 × 高） | 10.5 × 5，R1.5 |
| USB-C 槽底厚度 | 1.5 |
| USB-C 开口中心 | X=50，Z=22.29 |

USB-C 外槽按实测线头包胶 11.26 × 6.43 取整留余量为 13 × 8，四角 R1.5。它是圆角矩形，不是两端完整半圆，避免圆弧挤占包胶四角的空间。与外槽居中时，包胶左右每侧名义余量 0.87，上下每侧 0.785；按矩形包胶检查圆角处，最小余量约 0.55。考虑官方模型接口中心的竖向偏差后，最小角部余量约 0.26。

外槽范围 X=43.5..56.5、Z=18.29..26.29，槽底在 Y=82.8，距后壁外表面 Y=84 为 1.2。槽底小孔范围 X=44.75..55.25、Z=19.79..24.79，宽 10.5、高 5、R1.5。内侧增加 16 × 10、R2.5 的局部背衬，从 Y=81.3 延伸到后壁，槽底实体厚度为 82.8−81.3=1.5，高于本次工厂提出的 1 mm 要求；主后壁厚仍为 2.5。局部背衬距参考主控 PCB 后边约 0.29，装配检查未发现体积干涉。

线头金属露出长度为 6.9；用户另实测完全插到底后，包胶前沿距插座口为 1.8..2，本版采用较小的 1.8。参考插座最靠外端 Y≈82.065，槽底比插座口向外 0.735，所以插到底时包胶距槽底名义余量为 1.8−0.735≈1.065。这个计算采用实际插合后的距离，不把金属总长当作有效插合深度。

外槽允许包胶进入，小孔周围的槽底遮住大部分内部空间；接口周围仍留装配缝，不构成密封。仍需用该实测线材试插，确认打印公差、实际主控高度及包胶后段没有造成阻挡。[查看原生装配预览](USB_RECESS.png)。

上述 USB 修订更新底壳原生零件和 `../print/Base_Smooth_20deg.STL`。随后的编码器朝后修订另更新上盖原生零件、`../print/Lid_Smooth_20deg.STL` 和整机装配；底壳及两件托架没有因编码器转向而改变。打印时使用当前 `print` 文件夹中的四件，均已统一从当前原生 CAD 重新导出。随后螺母槽薄壁修订再次更新上盖几何，其余三件几何不变。

世界坐标：X 向右、Y 向后、Z 向上。载板参考范围 X=34..66、Y=46..81，底面 Z=7；固定孔中心为 `(37,49)`、`(63,49)`、`(37,78)`、`(63,78)`。后壁 Y=84。

面板局部坐标 U 向右、V 沿斜面向后、W 垂直面板向外，外表面 W=0。旋钮中心 `(31,37)`，按钮中心 `(77,37)`。旋钮帽顶面 W=19.90，未按下按钮顶面 W=5.30。编码器 PCB 底面 W=-14.07，按钮 PCB 底面 W=-9.70。

托架的外侧安装孔 Ø3.4 配 M2 螺丝，理论径向可调约 0.7。实际调整范围还受按钮开口、轴孔、托架边缘、垫片和线束限制；应先居中、试按，再锁紧。模块自身原安装孔使用 M2，位置误差由整个托架调节，不靠扩大模块 PCB 孔解决。

## 螺丝与装配

### 编码器出线复核（2026-09-27）

编码器已绕轴心转 90°，排针朝后，原接头仍可保留。旋钮中心 `(U,V)=(31,37)` 不动，编码器托架本体不改形状，只改变装配方向。上盖内部两根对应固定柱、盲螺丝孔和侧装螺母槽已移位；螺丝规格不变。**此次需要替换打印文件的是 `Lid_Smooth_20deg.STL`。现有编码器托架可继续使用；旧上盖的固定柱位置不适配新方向。**

用户补测裸针长 6.69，此前测得插合后排针侧 PCB 板边到接头及导线弯折外端共 15.62。最新总长约 48.5 沿用包含接头及弯折的口径，减去 PCB 长 32.30，板边外占位采用约 16.2，不再重复加裸针长度。设计先额外留 5，再把板边外预留取整为 **22**，即整套检查长度 **54.3**，比实测总长多约 **5.8**。这是布局余量，不是线材规格规定的最小弯曲半径。

原朝右方案在接头高度处到按钮托架仅约 13.45，小于上述约 16.2 的占位，因此改为朝后。

| 项目（面板局部坐标，mm） | 当前范围／位置 |
|---|---|
| 编码器 PCB | U=22.54..39.46，V=24.725..57.025 |
| 编码器 PCB 底面 | W=-14.07 |
| 排针方向 | +V，沿面板向后 |
| 托架右侧固定柱中心 | U=44.5，V=29 |
| 托架左侧固定柱中心 | U=17.5，V=53 |
| 接头与弯线检查范围 | U=22.54..39.46，V=57.025..79.025，W=-12.29..-6.29 |

检查范围的截面暂按 **16.92 宽 × 6 高**，从编码器 PCB 上表面起算，覆盖 PCB 全宽；这个截面是设计假设，实际包胶高度及弯线横向形状尚未完整测量。用当前原生装配导出的各零件表面与该范围逐三角形检查，没有相交。该范围距主后壁最小约 **3.04**，距上盖内面 **3.29**；其最低点比官方主控参考模型最高点高约 **5.63**。预留区不要再塞入别的线束，接头后的导线自然弯向载板，避免合盖时被拉紧或夹住。

整机现有实体体积干涉检查为 0。上述线束空间检查与实体检查分别进行，不把未建模的真实导线等同于已验证的实体。试装时保持接头和弯线在预留区内；若实际接头高于 6 或导线超出范围，应先复核再合盖，不能靠压线获得空间。

[当前内部布局预览](ENCODER_REAR_LAYOUT.png)：图中为简化参考模块，没有绘出实际排针和弯线；编码器长板的后端为排针侧，上盖、旋钮帽和按钮帽暂时隐藏以显示内部。

### 上盖螺母槽薄壁修正（2026-09-27）

工厂标出的 0.13 mm 来自槽角到柱外壁的距离：旧右侧按钮柱半径 3.4，矩形槽封闭端距柱心 2.5、槽半宽 2.1，因此最薄处为 `3.4−√(2.5²+2.1²)≈0.135`。柱子不是整体掏空，但螺丝孔与侧装螺母槽周围必须保留足够材料。此前实体干涉和 STL 网格检查不能发现或证明这项壁厚要求。

现将八个矩形槽的封闭端改成六角形的两条斜边，匹配普通六角螺母，保留从侧面插入的通道。M2 槽对边 4.2、高 1.8，M3 槽对边 5.8、高 2.8；右侧按钮柱加粗到 Ø7.6，其余柱径不变。原矩形切除特征已压缩，末尾新增命名的六角槽草图与切除特征，仍可直接编辑。普通六角螺母的一对平行边对准槽两侧，尖角朝封闭端；不要按此槽采购方螺母、法兰螺母或热熔嵌件。

| 检查部位 | CAD 理论壁厚 | 导出 STL 截面最小壁厚 |
|---|---:|---:|
| 四角 M3 柱的槽封闭端 | 1.651 | 1.645 |
| 两根编码器柱及左侧按钮柱的槽封闭端 | 1.575 | 1.569 |
| 右侧按钮柱的槽封闭端 | 1.375 | 1.370 |

以上数值是槽中间高度处，从六角封闭端两条斜边到柱外圆轮廓的最短距离，不把有意敞开的装入槽口视作封闭壁，也不等同于全模型壁厚认证。加粗后的按钮柱距底壳右内壁名义净距 0.4；原生装配实体干涉为零。M2/M3 螺丝孔、螺母槽高度位置和原有螺丝长度保持不变。新上盖 STL 应重新上传让工厂审核，再做实物装配验证。

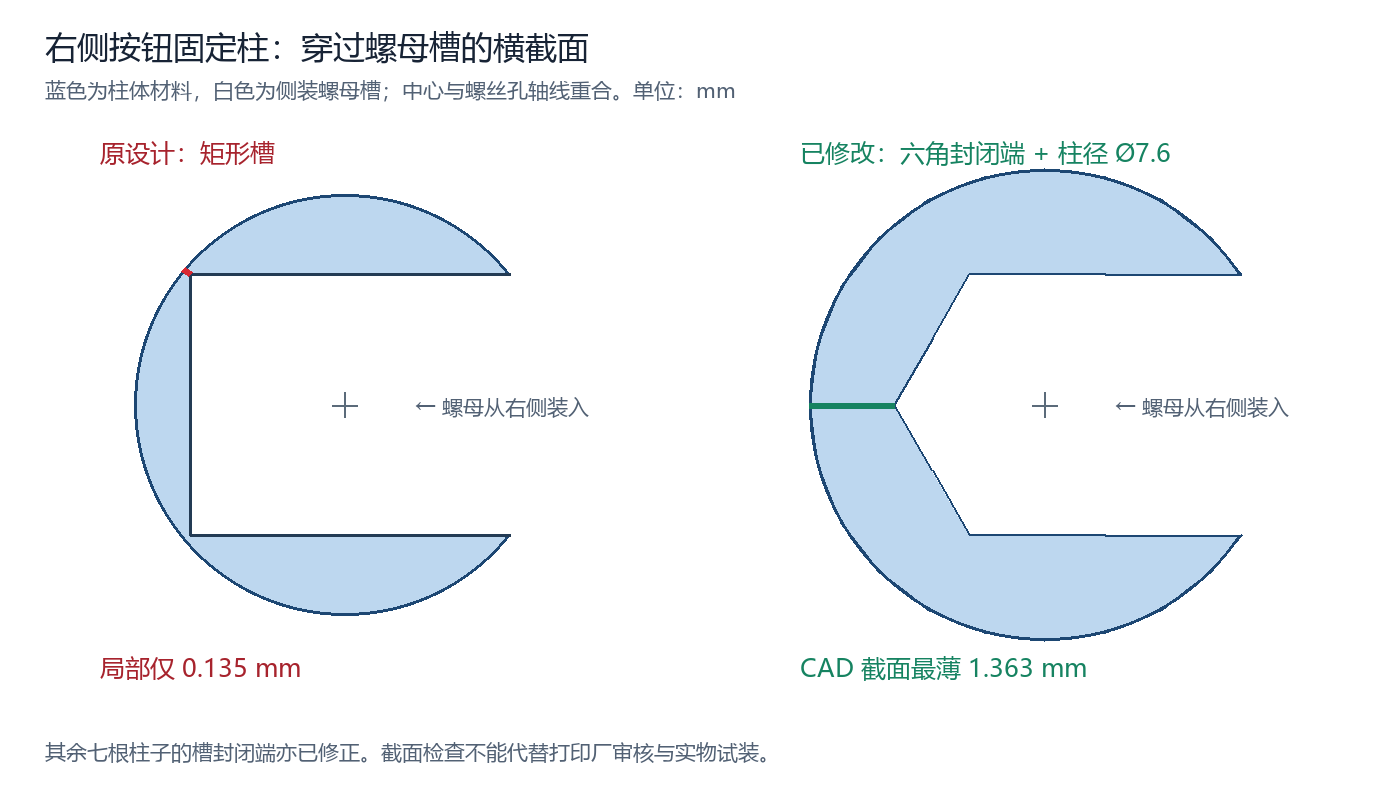
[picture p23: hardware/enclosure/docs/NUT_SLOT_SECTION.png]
右侧按钮柱螺母槽截面对比


### 螺丝清单

| 位置 | 规格 | 数量 |
|---|---|---:|
| 外壳底部四角 | M3×10 螺丝，头径不超过 6.6 | 4 |
| 上盖内部四角 | M3 六角螺母，常见对边 5.5；槽宽 5.8、高 2.8 | 4 |
| 托架固定到盖内柱 | M2×8 螺丝、薄平垫片（外径约 5） | 各 4 |
| 托架固定到盖内柱 | M2 六角螺母，常见对边 4；槽宽 4.2、高 1.8 | 4 |
| 模块 PCB 固定到托架 | M2×8 螺丝、M2 螺母 | 各 4 |
| 模块 PCB 固定到托架 | 薄垫片，编码器侧外径不超过 4.5 | 适量 |
| 载板固定到底壳 | M2×10 螺丝、M2 螺母，板面紧固件外径不超过 4.5 | 各 4 |
| 底面防滑与螺丝头避让 | 约 2 厚自粘脚垫 | 4 |

1. 将四颗 M3 螺母从上盖内部长柱侧面的槽插入；将四颗 M2 螺母装入控制模块安装柱侧槽。
2. 把按钮 PCB 和编码器 PCB 分别固定到托架；编码器排针朝后，与旋钮轴同侧的两个 PCB 安装孔朝前。托架开放中间避让背面电子器件；试装确认器件、插座、焊点没有压在支承边上。
3. 把托架从内部装到上盖。M2×8 螺丝由托架底面向上旋入柱内螺母，先保持略松。校正按钮与轴在开口中的位置，试按确认不擦边，再适度拧紧。
4. 载板安装到四个短柱，主控通过排针插入排母。USB-C、RUN、BOOT 朝上，USB 指向后壁居中开口。
5. 线束留活动余量，先用实际 USB 线试插，确认插入充分且不挤压主控，再合盖。
6. 四颗 M3×10 从底部穿入上盖盲孔柱，分次均匀锁紧，贴脚垫。

控制模块的固定螺丝已从旧版 M2×16 改为 M2×8。外壳四角采用 M3×10，是按底部新固定结构选取，不能仅为了短而任意换成接触不到螺母的长度。试装以实际螺丝头、垫片、螺母尺寸确认啮合和盲孔余量。

## 打印和检查边界

四个 STL 应以 mm、100% 比例导入切片。底壳和托架平底朝下；上盖外表面朝下，平面直接贴床，内部柱朝上。侧装螺母槽、USB 窗口顶边是否加局部支撑，依打印机桥接能力决定。不要让支撑堵死螺母槽。

按钮实测宽 12.11，开口每侧名义余量约 0.595；轴套实测直径 6.81，轴孔径向余量约 0.695。这些余量是为了装配和测量误差保留，不代表已验证打印机精度。

主控官方模型来源：https://www.waveshare.com/wiki/RP2350-Zero ，下载文件名为 `RP2350_Zero_step.zip`，现已转换为 `../cad/REF_RP2350_Official.SLDPRT` 独立零件。官方模型接口宽约 8.94；官方 CAD 的板厚、接口高度与用户实测略有差别，本版接口开口高度仍兼顾用户实测接口高出 PCB 上表面 3.28。主控正面 PCB 表面定位 Z=20.65，实际排针插合高度还需试装核对。不能将官方模型每一处几何都视为实物绝对尺寸。

编码器、按钮和线束仍为简化参考；现有实体检查不包含模块全部小元件和焊锡；编码器接头及弯线另按上文的预留范围检查，不能代替真实线束试装。当前样件未经过实际打印、按压或插拔试验。先试装上盖和两托架，再确认整机。

检查记录见 `VERIFICATION.txt`。原生特征保留为草图、拉伸和切除，后续可直接学习修改，无需运行宏即可打开模型。

## 本版数字检查结果

当前上盖为单一实体，特征检查无错误；编码器朝后装配保存、关闭、重新打开和重建成功，十个组件引用均位于本 CAD 文件夹，现有实体体积干涉为零。四个打印零件在螺母槽修正后统一重建并按 mm 重新导出，均为单实体、无特征错误；全部 STL 的闭合、单壳体、边方向、法向及自交检查通过。上盖调整为外面板朝下的打印方向，不缩放。整机透视状态已保留并保存；保存和导出均为 0 错误、0 警告。八处槽封闭端另做 CAD 表面与导出 STL 截面检查，结果见上文。接头及弯线另按上述假设截面复核通过；尚未做实物打印和试装。

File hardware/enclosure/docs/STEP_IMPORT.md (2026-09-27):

# 嘉立创 STEP 保存问题与本次验证

本机：嘉立创 EDA 专业版 4.1.60，SOLIDWORKS 2026 SP0.0；2026-09-27 实测。

用户遇到的现象是 STEP 能导入、能显示，但保存时报 `.step.SLDASM` 已损坏。报错对象是导入过程生成的装配体；单凭这个提示不能认定原始 STEP 的几何损坏。

## 本工程怎么打开

直接打开 `../cad/Music_Controller.SLDASM`。载板已是 `REF_Carrier.SLDPRT` 独立实体零件，主控也是独立的 `REF_RP2350_Official.SLDPRT`。整机不需要重新导入 STEP，也不依赖原 Pictures 或 Windows Temp 目录。

## 以后导入新载板

1. 在嘉立创打开 PCB，选择 **文件 → 导出 → 3D 文件**。
2. 选择 **STEP**，保留 PCB、元件模型、3D 体。做外壳尺寸参考时，可关闭丝印和信号层线路；本次新样本使用 **质量优先**。
3. 在 SOLIDWORKS 关闭之前导入的那份 STEP 文档。
4. 进入 **工具 → 选项 → 系统选项 → 导入**，取消 **启用 3D Interconnect**，然后重新打开 STEP。
5. 若导入结果是装配体，选择 **文件 → 另存为 → SOLIDWORKS 零件（*.SLDPRT）**，保留全部零部件；不要只保留外表面。
6. 关闭导入文档，再打开保存的 `.SLDPRT`，确认完整载板和连接器都在，并再次保存。
7. 将验证过的 `.SLDPRT` 插入外壳装配体，核对位置和孔距。

独立零件适合作为外壳尺寸参考。PCB 修改后要重新导入并替换参考件，它不会自动跟随原 STEP 更新。测试结束已恢复本机原来的导入设置；若按上述流程操作，仍需要先取消 3D Interconnect。

## 实测结果

| 输入／方式 | 保存结果 | 关闭文档后重开与再次保存 |
|---|---|---|
| 原始 `3D_PCB1_2026-09-27.step`；关闭 3D Interconnect；另存独立零件 | 成功，0 错误、0 警告 | 成功；11 个实体，无外部依赖 |
| 新导出 `Carrier_Quality_NoSilk.step`；质量优先；开启 3D Interconnect；另存装配体副本 | 成功，0 错误、0 警告 | 成功，0 错误、0 警告 |
| 同一个新 STEP；关闭 3D Interconnect；另存独立零件 | 成功，0 错误、0 警告 | 成功；11 个实体 |

测试通过不表示已经证明原报错的唯一原因，也不表示所有导出组合都已测试。新样本的链接装配体在本次测试中未复现报错；正式工程仍使用无外部依赖的原生零件。临时测试装配体没有放入正式 `cad` 目录。

另查出旧的 `Enclosure_Smooth_20deg_v2.SLDASM` 含指向 `AppData/Local/Temp/swx45500/IC~~` 的 RP2350 STEP 装配体引用，所以没有按“v2 看起来更新”把它选作正式版本。

检查记录已合并到 `VERIFICATION.txt`。临时测试模型、重复 STEP 和旧装配体已按要求删除；当前工程需要的几何全部保留在 `../cad` 的原生零件中。

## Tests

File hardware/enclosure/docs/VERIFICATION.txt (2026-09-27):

2026-09-27 当前发布检查：编码器朝后 + 螺母槽薄壁修正 + 保留用户透视视图
本段是最终文件检查；后文为历史修改记录，旧 STL 哈希、仅重导上盖等表述不代表当前发布文件。
最小按钮柱原槽角壁厚约 0.135 mm，按工厂反馈修正，不将网格通过误认为壁厚通过。
八个旧矩形槽压缩，新增六角封闭端槽；M2 对边4.2/高1.8，M3 对边5.8/高2.8 mm。
右侧按钮柱半径由3.4改为3.8 mm；螺丝孔中心、孔径、槽高度位置不变。
四件 STL 从原生 SOLIDWORKS 精细导出，mm；上盖刚性转为面板朝下，不缩放。
接缝坐标量化到0.00001 mm并重算法向；相邻边两面且方向相反；单壳体、闭合、无退化三角面、无自交、正体积、Manifold NoError。
上盖体积增加约135.428 mm³，来自槽角补实与柱径加粗；其余零件形状不变。
透视：操作前 True，操作后 True。四件原生零件与装配保存及导出均 errors=0 warnings=0。
10组件引用全部在cad目录；4打印零件各1实体，特征无错误；装配重建成功，实体干涉0。
22 mm编码器板边外线束检查盒与其他9组件表面相交数均0；仍假设接头截面16.92×6 mm，实物未试装。

最终 STL：
Base_Smooth_20deg.STL: triangles=4046, size_mm=100.000000 x 84.000000 x 48.573502, volume_mm3=45919.162680
SHA256 06c4a44896664eeae07908e0aae9957a1a6005762e719d5f0015d3c0ecec7773
Lid_Smooth_20deg.STL: triangles=4566, size_mm=100.000000 x 94.203613 x 45.312050, volume_mm3=36319.902949
SHA256 39ec7c8b0cb2c030379d3b10406f0e74dbd40a4bdc292306f3445ece45dc7a49
Encoder_Cradle.STL: triangles=1332, size_mm=33.435001 x 35.000000 x 3.000000, volume_mm3=886.810103
SHA256 f9f5dd05b41945ed712f82b0c68a71906d329fc2f4e561f1facb30266933edac
Button_Cradle.STL: triangles=1312, size_mm=40.687248 x 36.730000 x 3.000000, volume_mm3=1051.543800
SHA256 633de2fbe68e6cda8386505e0fee04b4f20fee6e24a6d10581c0d26aa906b643

局部壁厚方法：从槽中间高度的最终导出 STL 截面中，测量六角封闭端两斜边至柱外圆折线的最短段距。
此项不包括有意敞开的侧装入口，不等同于全模型制造认证；待打印厂重新审核与实物试装。
M3_front_left: nominal=1.651368 mm, STL_section=1.645084 mm
M3_front_right: nominal=1.651368 mm, STL_section=1.645084 mm
M3_rear_left: nominal=1.651368 mm, STL_section=1.645084 mm
M3_rear_right: nominal=1.651368 mm, STL_section=1.645084 mm
Encoder_right: nominal=1.575129 mm, STL_section=1.569132 mm
Encoder_left: nominal=1.575129 mm, STL_section=1.569133 mm
Button_left: nominal=1.575129 mm, STL_section=1.569136 mm
Button_right: nominal=1.375129 mm, STL_section=1.369897 mm
右侧按钮柱到底壳内侧名义净距0.4 mm。

原生检查日志：
USER_VIEW_PERSPECTIVE True
ASSEMBLY_REBUILD True
INTERFERENCE_COUNT 0
COMPONENTS 10
REFERENCE REF_Carrier-1 C:\public\hard\media-controller\hardware\enclosure\cad\REF_Carrier.SLDPRT
REFERENCE REF_Knob-1 C:\public\hard\media-controller\hardware\enclosure\cad\REF_Knob.SLDPRT
REFERENCE Base_Smooth_20deg-1 C:\public\hard\media-controller\hardware\enclosure\cad\Base_Smooth_20deg.SLDPRT
PART_REBUILD Base_Smooth_20deg-1 True
SOLIDS Base_Smooth_20deg-1 1
EXPORT Base_Smooth_20deg True errors=0 warnings=0
PART_SAVE Base_Smooth_20deg True errors=0 warnings=0
REFERENCE Lid_Smooth_20deg-1 C:\public\hard\media-controller\hardware\enclosure\cad\Lid_Smooth_20deg.SLDPRT
PART_REBUILD Lid_Smooth_20deg-1 True
SOLIDS Lid_Smooth_20deg-1 1
EXPORT Lid_Smooth_20deg True errors=0 warnings=0
PART_SAVE Lid_Smooth_20deg True errors=0 warnings=0
REFERENCE REF_Encoder-1 C:\public\hard\media-controller\hardware\enclosure\cad\REF_Encoder.SLDPRT
REFERENCE REF_Button_PCB-1 C:\public\hard\media-controller\hardware\enclosure\cad\REF_Button_PCB.SLDPRT
REFERENCE REF_Button_Cap-1 C:\public\hard\media-controller\hardware\enclosure\cad\REF_Button_Cap.SLDPRT
REFERENCE REF_RP2350_Official-1 C:\public\hard\media-controller\hardware\enclosure\cad\REF_RP2350_Official.SLDPRT
REFERENCE Encoder_Cradle-1 C:\public\hard\media-controller\hardware\enclosure\cad\Encoder_Cradle.SLDPRT
PART_REBUILD Encoder_Cradle-1 True
SOLIDS Encoder_Cradle-1 1
EXPORT Encoder_Cradle True errors=0 warnings=0
PART_SAVE Encoder_Cradle True errors=0 warnings=0
REFERENCE Button_Cradle-1 C:\public\hard\media-controller\hardware\enclosure\cad\Button_Cradle.SLDPRT
PART_REBUILD Button_Cradle-1 True
SOLIDS Button_Cradle-1 1
EXPORT Button_Cradle True errors=0 warnings=0
PART_SAVE Button_Cradle True errors=0 warnings=0
FINAL_VIEW_PERSPECTIVE True
ASSEMBLY_SAVE True errors=0 warnings=0
COMPLETE

----- 以下为历史修改记录 -----
2026-09-27 编码器排针朝后修订（当前上盖及整机检查）
本段优先于后面的历史记录。当前文件名不变，无另建版本目录。
修改：cad/Lid_Smooth_20deg.SLDPRT、cad/Music_Controller.SLDASM、print/Lid_Smooth_20deg.STL。
Encoder_Cradle 本体未改，仅绕编码器轴心转 90°；REF_Encoder 装配方向同步转动。
旋钮中心 U=31、V=37 mm；右／左固定柱中心 (44.5,29)、(17.5,53) mm。
盲螺丝孔及侧装螺母槽随固定柱移位，螺丝规格不变。
USB-C 底壳几何保持下方圆角内凹修订。

测量：含插头及弯线总长约 48.5 mm，PCB 长 32.30 mm，板边外约 16.2 mm。
设计：板边外预留 22 mm，总检查长度 54.3 mm，较实测多约 5.8 mm。
接头截面假设为 PCB 全宽 16.92 mm × 高 6 mm，从 PCB 顶面起算；不是线材规格。
检查盒（面板 U,V,W）：[22.54,57.025,-12.29]..[39.46,79.025,-6.29] mm。
与原生 CAD 导出的其余 9 个组件表面逐三角形做分离轴检查，相交三角形数均为 0。
后壁净距约 3.03736 mm；面板内面净距 3.29 mm；主控最高点上方间隙保守下界 5.63491 mm。

新上盖：精细二进制 STL，mm；刚性旋转到外面板朝下，平移至正坐标，不缩放。
接缝坐标量化至 0.00001 mm，保留全部三角形，按最终顶点重算法向。
网格检查数据：
{
  "triangles": 4534,
  "sha256": "4381fe2a8261d03cec309184516e383b2263be7f973bce82e8f2b389ee9dfd22",
  "bounds_mm": [
    [
      0.0,
      0.0,
      0.0
    ],
    [
      100.0,
      94.20361328125,
      45.312049865722656
    ]
  ],
  "normalization_max_vertex_delta_mm": 1.1476992733331114e-05,
  "topology": {
    "boundary_edges": 0,
    "connected_components_number": 1,
    "edges_number": 6801,
    "faces_number": 4534,
    "genus": 10,
    "incident_faces_on_non_two_manifold_edges": 0,
    "incident_faces_on_non_two_manifold_vertices": 0,
    "is_mesh_two_manifold": true,
    "non_two_manifold_edges": 0,
    "non_two_manifold_vertices": 0,
    "number_holes": 0,
    "unreferenced_vertices": 0,
    "vertices_number": 2249
  },
  "self_intersecting_faces": 0,
  "edge_pairs": true,
  "edge_winding_consistent": true,
  "manifold_status": "Error.NoError",
  "volume_mm3": 36184.4748778236,
  "panel_origin_world_mm": [
    0.0,
    -4.618527782440651e-14,
    21.192533317427774
  ],
  "cable_box_panel_mm": [
    [
      22.54,
      57.025,
      -12.29
    ],
    [
      39.46,
      79.025,
      -6.29
    ]
  ],
  "cable_box_world_bounds_mm": [
    [
      22.54,
      55.73727840183484,
      29.147409681115217
    ],
    [
      39.46,
      78.46263691907885,
      42.31000855899538
    ]
  ],
  "cable_box_surface_collisions": {
    "Base_Smooth_20deg-1": 0,
    "Button_Cradle-1": 0,
    "Encoder_Cradle-1": 0,
    "Lid_Smooth_20deg-1": 0,
    "REF_Button_Cap-1": 0,
    "REF_Button_PCB-1": 0,
    "REF_Carrier-1": 0,
    "REF_Knob-1": 0,
    "REF_RP2350_Official-1": 0
  },
  "rear_wall_clearance_mm": 3.0373630809211534,
  "panel_inner_clearance_mm": 3.29,
  "mainboard_vertical_gap_lower_bound_mm": 5.634911051277019,
  "encoder_total_reserved_length_mm": 54.3,
  "cable_cross_section_assumption_mm": [
    16.92,
    6
  ]
}

原生保存和重开记录：
LID_REBUILD True
LID_PREVIEW True
LID_SAVE True errors=0 warnings=0
ASSEMBLY_SAVE True errors=0 warnings=0
ASSEMBLY_REOPEN errors=0 warnings=32
ASSEMBLY_REBUILD True
COMPONENTS 10
REFERENCE REF_Carrier-1 C:\public\hard\media-controller\hardware\enclosure\cad\REF_Carrier.SLDPRT
REFERENCE REF_Knob-1 C:\public\hard\media-controller\hardware\enclosure\cad\REF_Knob.SLDPRT
REFERENCE Base_Smooth_20deg-1 C:\public\hard\media-controller\hardware\enclosure\cad\Base_Smooth_20deg.SLDPRT
REFERENCE Lid_Smooth_20deg-1 C:\public\hard\media-controller\hardware\enclosure\cad\Lid_Smooth_20deg.SLDPRT
LID_SOLIDS 1
REFERENCE REF_Encoder-1 C:\public\hard\media-controller\hardware\enclosure\cad\REF_Encoder.SLDPRT
REOPEN_AXIS REF_Encoder-1 0,0.939692620785908,0.342020143325669
REFERENCE REF_Button_PCB-1 C:\public\hard\media-controller\hardware\enclosure\cad\REF_Button_PCB.SLDPRT
REFERENCE REF_Button_Cap-1 C:\public\hard\media-controller\hardware\enclosure\cad\REF_Button_Cap.SLDPRT
REFERENCE REF_RP2350_Official-1 C:\public\hard\media-controller\hardware\enclosure\cad\REF_RP2350_Official.SLDPRT
REFERENCE Encoder_Cradle-1 C:\public\hard\media-controller\hardware\enclosure\cad\Encoder_Cradle.SLDPRT
REOPEN_AXIS Encoder_Cradle-1 0,0.939692620785908,0.342020143325669
REFERENCE Button_Cradle-1 C:\public\hard\media-controller\hardware\enclosure\cad\Button_Cradle.SLDPRT
INTERFERENCE_COUNT 0
LAYOUT_PREVIEW True
FINAL_SAVE True errors=0 warnings=0
COMPLETE

原生内部布局预览：ENCODER_REAR_LAYOUT.png。参考模块未画实际排针和线束。
数字检查通过；未经过实物试装或打印厂复审。旧上盖应替换为当前上盖 STL，其他打印件无需因本次转向重传。

===== 以下为 USB-C 修订及更早检查历史；各段“本次”指当时修订 =====
2026-09-27 USB-C 圆角内凹修订（当前底壳检查）
当前入口：cad/Music_Controller.SLDASM
当前打印底壳：print/Base_Smooth_20deg.STL
本段优先于下方历史记录；上盖及两件托架的打印 STL 未改动。

实测包胶 11.26 × 6.43 mm，金属头露出 6.9 mm。
用户实测完全插入后包胶前沿到插座口 1.8..2 mm；本版按 1.8 mm。
外槽 13 × 8 mm，R1.5，深 1.2 mm；中心 X=50、Z=22.29 mm。
外槽边界 X=43.5..56.5、Z=18.29..26.29 mm；槽底 Y=82.8 mm。
内孔 10.5 × 5 mm，R1.5；边界 X=44.75..55.25、Z=19.79..24.79 mm。
局部背衬 16 × 10 mm、R2.5，Y=81.3..84 mm；槽底厚 1.5 mm。
主后壁 Y=81.5..84 mm，厚 2.5 mm。
USB 插座参考最外端 Y=82.0651945 mm；槽底前移 0.7348055 mm。
插到底包胶距槽底名义余量 1.8−0.7348055=1.0651945 mm。
局部背衬距主控 PCB 后边名义余量约 0.29137 mm。
包胶矩形四角在外槽圆角内；按官方插座竖向中心复核，最小角部余量约 0.25569 mm。
小孔周围槽底遮挡内部，仍保留装配间隙，不是密封结构。

当前原生特征：
USB_Pocket_Backing_Y81p3_to84
USB_Socket_Opening_10p5x5_R1p5
USB_Cable_Recess_depth1p2_floor1p5
旧直通孔相关特征已抑制，新特征为草图、拉伸及切除。
原生单一实体；遍历特征错误数 0；重建 True。
底壳关闭重新打开 errors=0、warnings=0；保存 True、errors=0、warnings=0。
整机关闭重新打开 errors=0、warnings=32（需要重建）；重建 True。
整机保存 True、errors=0、warnings=0。
本轮首次访问已打开整机时 warning=128 为 AlreadyOpen，并非损坏。
跨组件体积干涉检查：0；包括隐藏实体，不计重合接触，不做参考零件内部多实体自干涉。
原生底壳及整机的后部斜视预览已检查，docs/USB_RECESS.png 为整机原生导出图。

STL 由当前原生底壳重新导出，mm、精细、二进制，保留原点。
对接缝坐标以 0.00001 mm 量化，最大顶点位移 0.00001144409 mm；
保留全部三角形，按最终顶点重新计算存储法向量。
SHA-256: a811fd3ed507400d3e65361c9801615f80f676fd8dd1d163336221ff0a864394
Triangles: 4046
Unique vertices: 2007
Size mm: 100 × 84 × 48.5735016
Volume mm^3: 45919.1626803
Connected components: 1
Boundary edges: 0
Non-manifold edges / vertices: 0 / 0
Self-intersecting faces: 0
All edges paired with opposite winding: True
Independent manifold3d status: Error.NoError，正体积。
内孔 767 个截面射线样本无阻挡；槽底 714 个样本厚度 1.5 mm；
局部背衬周边 688 个样本交点符合 Y=81.3..84；所有截面检查失败数 0。

检查范围：数字模型与网格检查通过，尚未实物打印、试插或获得厂方复审。
重新向打印厂提交当前 Base_Smooth_20deg.STL；其余打印件无需因本次 USB 修订重传。

===== 以下为此前直通孔修订及文件整理历史记录，不是当前几何 =====
2026-09-27 USB-C 薄壁修订（当前底壳检查）
当前入口：cad/Music_Controller.SLDASM
当前打印底壳：print/Base_Smooth_20deg.STL
以下最新记录优先于后面的文件整理历史记录；其余三个打印件未修改。

线材实测：包胶宽 11.26 mm，高 6.43 mm；金属头露出 6.9 mm。
最终开口：13 × 8 mm 直通，中心 X=50、Z=22.29 mm。
开口边界：X=43.5..56.5、Z=18.29..26.29 mm。
后壁 Y=81.5..84 mm，厚 2.5 mm。原外侧沉口的 0.5 mm 薄边已去除。
草图放大并将切除设为从 Y=81 到 Y=85 mm，贯穿全部后壁厚度。
原生特征：USB_C_cable_clearance_13x8；单一实体，特征错误数 0。
原生底壳保存：True，errors=0，warnings=0。
关闭并重新打开底壳：errors=0，warnings=0。
装配 10 个组件的引用均在当前 cad 目录。
装配重开：errors=0，warnings=32（swFileLoadWarning_NeedsRegen，需要重建）。
执行 ForceRebuild3：True；装配再次保存：True，errors=0，warnings=0。
该提示不是 STEP 文件损坏；本轮没有改动任何参考零件或其位置。

STL 由修改后的原生底壳重新导出，单位 mm，原点和外形尺寸保留。
对浮点接缝进行 0.00001 mm 坐标量化，最大顶点位移 0.00001145 mm；
未增删三角形、未改变三角形顺序，按最终顶点重新计算存储法向量。
SHA-256: 0fd41c0f227a2d322a193bd71c01fab6d2ada973f9dc743907d7129dd7616a56
Triangles: 3582
Unique vertices: 1775
Size mm: 100 × 84 × 48.5735016
Volume mm^3: 45826.4942
Connected components: 1
Boundary edges: 0
Non-manifold edges / vertices: 0 / 0
Self-intersecting faces: 0
All edges paired with opposite winding: True
Stored normal dot geometric normal minimum: 0.9999999679
Independent manifold3d status: Error.NoError，正体积。
开口内部 27 × 17 = 459 条穿过后壁的射线均无阻挡。
孔左右、上下周围 6 个抽查位置，后壁交点均为 Y=81.5 和 Y=84 mm，厚 2.5 mm。
原生底壳导出预览已检查：开口为单一直通矩形，没有旧薄边台阶。

参考装配 USB 插座外端包围盒约 Y=82.065 mm，距后壁外表面约 1.935 mm。
包胶与开口居中时，左右单侧名义余量 0.87 mm，上下单侧 0.785 mm。
检查说明：模型与网格检查通过，不等于厂家审核或实物试插通过。
尚需重新提交底壳给打印厂复核；线材后段形状、实际插合深度和打印公差需试装确认。

===== 以下为本次 USB 修订之前的文件整理历史记录 =====
2026-09-27 外壳文件整理与检查记录
当前入口：cad/Music_Controller.SLDASM
正式 CAD 的 10 个零件和 4 个 STL 与原工作目录 SHA-256 核对一致。
以下为整理期间的原始检查输出；首次打开曾出现 warning=32，保存后最终重开为 0 错误、0 警告。
未进行实物打印或试装。

===== migration_check.txt =====
stage activate
stage get pack
stage options
stage names
PACK C:\Users\kiro\Pictures\kiro_media_controller_3d\Enclosure_Smooth_20deg.SLDASM => C:\public\hard\media-controller\hardware\enclosure\cad\Music_Controller.SLDASM
PACK C:\Users\kiro\Pictures\kiro_media_controller_3d\Base_Smooth_20deg.SLDPRT => C:\public\hard\media-controller\hardware\enclosure\cad\Base_Smooth_20deg.SLDPRT
PACK C:\Users\kiro\Pictures\kiro_media_controller_3d\Lid_Smooth_20deg.SLDPRT => C:\public\hard\media-controller\hardware\enclosure\cad\Lid_Smooth_20deg.SLDPRT
PACK C:\Users\kiro\Pictures\kiro_media_controller_3d\REF_Carrier.SLDPRT => C:\public\hard\media-controller\hardware\enclosure\cad\REF_Carrier.SLDPRT
PACK C:\Users\kiro\Pictures\kiro_media_controller_3d\REF_Encoder.SLDPRT => C:\public\hard\media-controller\hardware\enclosure\cad\REF_Encoder.SLDPRT
PACK C:\Users\kiro\Pictures\kiro_media_controller_3d\REF_Knob.SLDPRT => C:\public\hard\media-controller\hardware\enclosure\cad\REF_Knob.SLDPRT
PACK C:\Users\kiro\Pictures\kiro_media_controller_3d\REF_Button_PCB.SLDPRT => C:\public\hard\media-controller\hardware\enclosure\cad\REF_Button_PCB.SLDPRT
PACK C:\Users\kiro\Pictures\kiro_media_controller_3d\REF_Button_Cap.SLDPRT => C:\public\hard\media-controller\hardware\enclosure\cad\REF_Button_Cap.SLDPRT
PACK C:\Users\kiro\Pictures\kiro_media_controller_3d\Button_Cradle.SLDPRT => C:\public\hard\media-controller\hardware\enclosure\cad\Button_Cradle.SLDPRT
PACK C:\Users\kiro\Pictures\kiro_media_controller_3d\Encoder_Cradle.SLDPRT => C:\public\hard\media-controller\hardware\enclosure\cad\Encoder_Cradle.SLDPRT
PACK C:\Users\kiro\Pictures\kiro_media_controller_3d\REF_RP2350_Official.SLDPRT => C:\public\hard\media-controller\hardware\enclosure\cad\REF_RP2350_Official.SLDPRT
SetNames=True
Pack status=0
Pack status=0
Pack status=0
Pack status=0
Pack status=0
Pack status=0
Pack status=0
Pack status=0
Pack status=0
Pack status=0
Pack status=0
COLD REOPEN errors=0 warnings=0
COMPONENT COUNT=10
COMPONENT Button_Cradle-1 => C:\public\hard\media-controller\hardware\enclosure\cad\Button_Cradle.SLDPRT
SOLID BODIES=1
COMPONENT REF_Button_Cap-1 => C:\public\hard\media-controller\hardware\enclosure\cad\REF_Button_Cap.SLDPRT
SOLID BODIES=1
COMPONENT Encoder_Cradle-1 => C:\public\hard\media-controller\hardware\enclosure\cad\Encoder_Cradle.SLDPRT
SOLID BODIES=1
COMPONENT REF_RP2350_Official-1 => C:\public\hard\media-controller\hardware\enclosure\cad\REF_RP2350_Official.SLDPRT
SOLID BODIES=130
COMPONENT Base_Smooth_20deg-1 => C:\public\hard\media-controller\hardware\enclosure\cad\Base_Smooth_20deg.SLDPRT
SOLID BODIES=1
COMPONENT REF_Encoder-1 => C:\public\hard\media-controller\hardware\enclosure\cad\REF_Encoder.SLDPRT
SOLID BODIES=1
COMPONENT REF_Knob-1 => C:\public\hard\media-controller\hardware\enclosure\cad\REF_Knob.SLDPRT
SOLID BODIES=1
COMPONENT REF_Button_PCB-1 => C:\public\hard\media-controller\hardware\enclosure\cad\REF_Button_PCB.SLDPRT
SOLID BODIES=1
COMPONENT Lid_Smooth_20deg-1 => C:\public\hard\media-controller\hardware\enclosure\cad\Lid_Smooth_20deg.SLDPRT
SOLID BODIES=1
COMPONENT REF_Carrier-1 => C:\public\hard\media-controller\hardware\enclosure\cad\REF_Carrier.SLDPRT
SOLID BODIES=11
SAVE=True errors=0 warnings=0

===== final_check.txt =====
OPEN errors=0 warnings=32
FRONT PREVIEW=True
REAR PREVIEW=True
STEP EXPORT=True errors=0 warnings=0
SAVE=True errors=0 warnings=0
FINAL REOPEN errors=0 warnings=0
COMPONENTS=10
REF_Encoder-1 => C:\public\hard\media-controller\hardware\enclosure\cad\REF_Encoder.SLDPRT
REF_Carrier-1 => C:\public\hard\media-controller\hardware\enclosure\cad\REF_Carrier.SLDPRT
Base_Smooth_20deg-1 => C:\public\hard\media-controller\hardware\enclosure\cad\Base_Smooth_20deg.SLDPRT
Lid_Smooth_20deg-1 => C:\public\hard\media-controller\hardware\enclosure\cad\Lid_Smooth_20deg.SLDPRT
REF_RP2350_Official-1 => C:\public\hard\media-controller\hardware\enclosure\cad\REF_RP2350_Official.SLDPRT
Button_Cradle-1 => C:\public\hard\media-controller\hardware\enclosure\cad\Button_Cradle.SLDPRT
Encoder_Cradle-1 => C:\public\hard\media-controller\hardware\enclosure\cad\Encoder_Cradle.SLDPRT
REF_Button_Cap-1 => C:\public\hard\media-controller\hardware\enclosure\cad\REF_Button_Cap.SLDPRT
REF_Button_PCB-1 => C:\public\hard\media-controller\hardware\enclosure\cad\REF_Button_PCB.SLDPRT
REF_Knob-1 => C:\public\hard\media-controller\hardware\enclosure\cad\REF_Knob.SLDPRT
STORED DEPENDENCY=Base_Smooth_20deg
STORED DEPENDENCY=C:\public\hard\media-controller\hardware\enclosure\cad\Base_Smooth_20deg.SLDPRT
STORED DEPENDENCY=Lid_Smooth_20deg
STORED DEPENDENCY=C:\public\hard\media-controller\hardware\enclosure\cad\Lid_Smooth_20deg.SLDPRT
STORED DEPENDENCY=REF_Carrier
STORED DEPENDENCY=C:\public\hard\media-controller\hardware\enclosure\cad\REF_Carrier.SLDPRT
STORED DEPENDENCY=REF_Encoder
STORED DEPENDENCY=C:\public\hard\media-controller\hardware\enclosure\cad\REF_Encoder.SLDPRT
STORED DEPENDENCY=REF_Knob
STORED DEPENDENCY=C:\public\hard\media-controller\hardware\enclosure\cad\REF_Knob.SLDPRT
STORED DEPENDENCY=REF_Button_PCB
STORED DEPENDENCY=C:\public\hard\media-controller\hardware\enclosure\cad\REF_Button_PCB.SLDPRT
STORED DEPENDENCY=REF_Button_Cap
STORED DEPENDENCY=C:\public\hard\media-controller\hardware\enclosure\cad\REF_Button_Cap.SLDPRT
STORED DEPENDENCY=Button_Cradle
STORED DEPENDENCY=C:\public\hard\media-controller\hardware\enclosure\cad\Button_Cradle.SLDPRT
STORED DEPENDENCY=Encoder_Cradle
STORED DEPENDENCY=C:\public\hard\media-controller\hardware\enclosure\cad\Encoder_Cradle.SLDPRT
STORED DEPENDENCY=REF_RP2350_Official
STORED DEPENDENCY=C:\public\hard\media-controller\hardware\enclosure\cad\REF_RP2350_Official.SLDPRT

===== legacy_import.txt =====
Original 3DInterconnect=True; MultibodyAsPart=False
TEST 3DInterconnect=False MultibodyAsPart=True
IMPORT errors=0
Doc type=2 title=3D_PCB1_2026-09-27.SLDASM
SAVE independent part=True errors=0 warnings=0
Preferences restored

===== legacy_reopen.txt =====
REOPEN errors=0 warnings=0
SOLID BODIES=11
EXTERNAL DEPENDENCIES=none
SECOND SAVE=True errors=0 warnings=0

===== quality_test.txt =====
TEST 3DInterconnect=True
IMPORT errors=0
IMPORT document type=2
SAVE=True errors=0 warnings=0
REOPEN errors=0 warnings=0
SECOND SAVE=True errors=0 warnings=0
TEST 3DInterconnect=False
IMPORT errors=0
IMPORT document type=2
SAVE=True errors=0 warnings=0
REOPEN errors=0 warnings=0
SOLIDS=11
SECOND SAVE=True errors=0 warnings=0
TESTS COMPLETE; preferences restored

===== smooth_print_validation.json =====
[
  {
    "file": "Base_Smooth_20deg.STL",
    "units": "mm",
    "triangles": 3746,
    "size_mm": [
      100.0,
      84.0,
      48.5735
    ],
    "solid_volume_mm3": 45891.95,
    "manifold_edges": true,
    "orientation": "flat base down"
  },
  {
    "file": "Button_Cradle.STL",
    "units": "mm",
    "triangles": 1360,
    "size_mm": [
      40.67299,
      36.73,
      3.0
    ],
    "solid_volume_mm3": 1051.547,
    "manifold_edges": true,
    "orientation": "flat base down"
  },
  {
    "file": "Encoder_Cradle.STL",
    "units": "mm",
    "triangles": 1380,
    "size_mm": [
      33.435,
      34.97149,
      3.0
    ],
    "solid_volume_mm3": 886.864,
    "manifold_edges": true,
    "orientation": "flat base down"
  },
  {
    "file": "Lid_Smooth_20deg.STL",
    "units": "mm",
    "triangles": 4636,
    "size_mm": [
      100.0,
      94.19937,
      45.31051
    ],
    "solid_volume_mm3": 36184.073,
    "manifold_edges": true,
    "orientation": "flat exterior panel down; inspect nut-slot bridging"
  }
]

清理完成后的独立启动检查：
已删除旧 Pictures 工作目录、source、export、preview，共 160 个旧版、重复或测试文件。
彻底退出并重新启动 SOLIDWORKS 2026，从当前 cad/Music_Controller.SLDASM 打开。
10 个组件在特征树完整显示，无丢失文件或损坏弹窗；随后 Ctrl+S 保存，无报错。
当前交付目录包含 1 个装配体、10 个零件、4 个打印 STL、入口说明和 3 份文档。

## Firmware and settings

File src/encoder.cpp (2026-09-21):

#include "input.h"

namespace {
// Gray-code transitions per detent = 4 × pulses per revolution ÷ detents per revolution; the Waveshare module is 20 pulses/rev with detents unmarked, so measure before trusting this value.
constexpr int8_t kAccumulatorPerDetent = 4;

// One sample per millisecond: mechanical bounce settles well inside that, and
// missing a turn would need two Gray steps within a window (~25 rev/s by hand).
constexpr int32_t kSampleIntervalMs = 1;
}  // namespace

DebouncedInput::DebouncedInput(uint gpio, bool active_high, InputPull pull)
    : gpio_(gpio), active_high_(active_high), pull_(pull) {}

void DebouncedInput::init(uint32_t now_ms) {
    gpio_init(gpio_);
    gpio_set_dir(gpio_, GPIO_IN);

    if (pull_ == InputPull::Up) {
        gpio_pull_up(gpio_);
    } else if (pull_ == InputPull::Down) {
        gpio_pull_down(gpio_);
    } else {
        gpio_disable_pulls(gpio_);
    }

    candidate_active_ = read_active();
    stable_active_ = candidate_active_;
    last_raw_change_ms_ = now_ms;
}

void DebouncedInput::update(uint32_t now_ms) {
    const bool raw_active = read_active();
    if (raw_active != candidate_active_) {
        candidate_active_ = raw_active;
        last_raw_change_ms_ = now_ms;
    }

    if (candidate_active_ != stable_active_ &&
        static_cast<uint32_t>(now_ms - last_raw_change_ms_) >= kDebounceMs) {
        const bool was_active = stable_active_;
        stable_active_ = candidate_active_;
        if (!was_active && stable_active_) {
            activated_ = true;
        }
    }
}

bool DebouncedInput::is_active() const {
    return stable_active_;
}

bool DebouncedInput::take_activated() {
    const bool result = activated_;
    activated_ = false;
    return result;
}

bool DebouncedInput::read_active() const {
    const bool pin_is_high = gpio_get(gpio_);
    return active_high_ ? pin_is_high : !pin_is_high;
}

QuadratureEncoder::QuadratureEncoder(uint pin_a, uint pin_b, uint pin_switch)
    : pin_a_(pin_a), pin_b_(pin_b), switch_(pin_switch, false, InputPull::Up) {}

void QuadratureEncoder::init(uint32_t now_ms) {
    gpio_init(pin_a_);
    gpio_set_dir(pin_a_, GPIO_IN);
    gpio_pull_up(pin_a_);

    gpio_init(pin_b_);
    gpio_set_dir(pin_b_, GPIO_IN);
    gpio_pull_up(pin_b_);

    previous_state_ = read_state();
    last_sample_ms_ = now_ms - 1;
    switch_.init(now_ms);
}

void QuadratureEncoder::update(uint32_t now_ms) {
    if (static_cast<int32_t>(now_ms - last_sample_ms_) < kSampleIntervalMs) {
        return;
    }
    last_sample_ms_ = now_ms;

    // Valid quadrature transitions are one Gray-code step apart.
    static constexpr int8_t kTransitionDelta[16] = {
        0, -1, 1, 0,
        1, 0, 0, -1,
        -1, 0, 0, 1,
        0, 1, -1, 0,
    };

    const uint8_t state = read_state();
    quadrature_accumulator_ += kTransitionDelta[(previous_state_ << 2U) | state];
    previous_state_ = state;

    if (quadrature_accumulator_ >= kAccumulatorPerDetent) {
        ++pending_turns_;
        quadrature_accumulator_ -= kAccumulatorPerDetent;
    } else if (quadrature_accumulator_ <= -kAccumulatorPerDetent) {
        --pending_turns_;
        quadrature_accumulator_ += kAccumulatorPerDetent;
    }

    switch_.update(now_ms);
}

int QuadratureEncoder::take_turns() {
    const int result = pending_turns_;
    pending_turns_ = 0;
    return result;
}

bool QuadratureEncoder::take_switch_pressed() {
    return switch_.take_activated();
}

uint8_t QuadratureEncoder::read_state() const {
    return static_cast<uint8_t>((gpio_get(pin_a_) ? 0b10 : 0) |
                                (gpio_get(pin_b_) ? 0b01 : 0));
}

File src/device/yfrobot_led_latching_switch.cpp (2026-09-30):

#include "device/yfrobot_led_latching_switch.h"

// 保存并配置 SIG 引脚，再将去抖时长、时间基准和初始采样交给去抖组件。
void YfrobotLedLatchingSwitch::init(uint sig_pin, uint32_t now_ms) {
    sig_pin_ = sig_pin;

    gpio_init(sig_pin_);
    gpio_set_dir(sig_pin_, GPIO_IN);
    // 使用已验证的接法，不启用 MCU 内部上下拉。
    gpio_disable_pulls(sig_pin_);

    // 单独供电实测灯灭时 SIG 约 0 V、灯亮时约 3.3 V，直接把高电平作为有效状态。
    sig_.init(sig_debounce_ms, now_ms, gpio_get(sig_pin_));
}

// SIG 高电平为开、低电平为关；读取后交给去抖逻辑。
void YfrobotLedLatchingSwitch::update(uint32_t now_ms) {
    sig_.update(now_ms, gpio_get(sig_pin_));
}

// 返回自锁开关的稳定闭合状态。
bool YfrobotLedLatchingSwitch::is_on() const {
    return sig_.is_active();
}

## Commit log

2026-09-21 审计整改：USB 身份、唤醒、采样与下拉配置
    - 序列号改为 RP2350 OTP 唯一 ID（pico_unique_id），PID 自定义 0x40A1，bcdDevice 递增规则写入 README
    - 实现 remote wakeup：睡眠中转动/按下先唤醒，动作恢复后发出；挂起时排空队列，主机未使能唤醒时睡眠输入持续丢弃
    - 编码器 A/B 采样节流到 1kHz，每格跳变数提为 kAccumulatorPerDetent（取值待台架）
    - DebouncedInput 下拉配置改为 InputPull 枚举；GP2 取值待台架真值表
    - HID 端点 bInterval 10ms -> 1ms
    - 接线表丝印名改为实物 SIA/SIB/SW，README 同步全部行为与已知限制
2026-09-22 构建：-Wconversion 限定为只检查自有源文件
    全量 87 个文件在 -Wconversion 下是 0 警告，但那 84 个第三方 .c 的转换警告
    我们无法修复，SDK 升级随时会把构建弄脏，因此用 set_source_files_properties
    只对本工程的三个 .cpp 启用。
    实测依据：-isystem 对头文件警告的抑制真实存在（本项目 57 个 -isystem vs
    5 个 -I），揭开后 main.cpp 的 system 头链上仅 1 条，且位于 newlib stdio.h，
    不是 pico-sdk。验证方式为 compile_commands.json 的开关分布 + 全量重建 0 警告。
2026-09-22 重构：拆分输入类文件，QuadratureEncoder 改名 RotationSensor
    DebouncedInput 与正交解码是两套不同逻辑，此前同居 input.h / encoder.cpp。
    现在一类一对：debounced_input.{h,cpp} 与 rotation_sensor.{h,cpp}。
    改名理由：该类同时建模模块自带的按下按键，旧名只反映了一半职责，读代码时
    会让人以为 take_switch_pressed() 来自别处。main.cpp 的变量随之改名。
    纯移动 + 改名，实现逐字未变（与 HEAD 分段 diff 验证，仅差文件末尾空行）。
    节流闸门与按键去抖的耦合因此留到下一个独立提交，便于分别评审。
    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
2026-09-22 重构：LED 自锁按键获得器件级类型 LatchingButton
    建模规则改为一个物理器件一个类型。此前 LED 按键在 main.cpp 里裸建
    DebouncedInput，与 RotationSensor 不对称：两个物理器件，只有一个有类型。
    器件事实随之归位：SIG 高有效、上下拉待定，从 main.cpp 的调用参数移入
    latching_button.cpp 的 kSigActiveHigh / kSigPull。main.cpp 不再直接依赖
    debounced_input.h，只认识两个器件对象。
    README 的调参表与已知隐患块改指新位置，项目结构表补上建模规则说明。
2026-09-22 重构：提取 QuadratureInput，机制层统一 [修饰词]Input 命名
    正交解码是机制而非器件逻辑，从 RotationSensor 提取为独立类型。算法本体
    （16 项格雷码表 + 累加器 + 每格阈值）不再碰 GPIO，只接受 state、产出格数；
    gpio_get 胶水留在器件层的 read_state()。kAccumulatorPerDetent 随算法走，
    kSampleIntervalMs 留在器件层——采样率是器件的事，解码是机制的事。
    顺带修掉节流耦合：按钮去抖改为每次循环轮询，只有相位采样受 1ms 闸门约束，
    去抖分辨率不再隐式依赖编码器采样率。新增 seed() 建立基线，替代旧代码里
    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
2026-09-22 文档：机制层命名约定改为按方向分 Input/Output 两族
    上一版约定只给了输入方向，屏幕这类输出器件说不通。补上 Output 族，
    并加入更深的一条规则：SDK 已提供的机制不重写、不包装，机制层只放
    SDK 没有的东西。这同时解释了为何机制层目前只有 Input 一族。
2026-09-22 重构：机制层统一 Channel、器件层统一 Sensor，分层约定写入 README
    机制层：DebouncedInput → SwitchChannel，QuadratureInput → QuadratureChannel，
    文件同步改名。Input/Output 两族后缀被否决——双向机制（如将来的 I2C 触摸，
    既写配置又读状态）是一个通道两种方法，方向不该进后缀；Channel 方向中立。
    器件层：LatchingButton → ModeSensor（按感知的物理量命名），RotationSensor
    保持；实例变量统一 [角色]_sensor，main.cpp 现为 mode_sensor / rotation_sensor。
    README 新增"分层与命名约定"：通道层责任一句话（持有信号的时间与电气细节，
    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
2026-09-22 重构：采样节流下沉到 QuadratureChannel，通道自管节奏
    README 约定写明"采样节奏"归通道层，但 kSampleIntervalMs 与 last_sample_ms_
    此前住在 RotationSensor（器件层），update() 因此混合了器件组合与通道节流两件
    事，且与 SwitchChannel 自管 kDebounceMs 不对称。
    现 QuadratureChannel 自带闸门：update(now_ms, state) 内部判窗，
    seed(now_ms, state) 建立基线与首帧时间。RotationSensor::update 退化为
    "推进两个通道"，不再持有任何节奏状态。
    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
2026-09-22 重构：删除方向反转 flag，src 按 channel/sensor 分层建目录
    kInvertEncoderDirection 删除。它表达的是接线事实却住在策略层；台架若测出
    顺时针为负，交换 kEncoderSiaPin 与 kEncoderSibPin 即可——用物理修正物理，
    不留一个可能永远为 false 的软件标志位。README 实测表首行同步为新做法。
    src 下新建 channel/ 与 sensor/ 两个子目录，include 路径加层名前缀
    （如 channel/switch_channel.h、sensor/rotation_sensor.h），分层在 include
    处即可见。CMake 源清单与 README 全部路径同步。
    构建 0 警告，-Wconversion 覆盖全部 6 个自有编译单元。
    [rotation_sensor.cpp, switch_channel.cpp]
2026-09-22 重构：器件层后缀 Sensor 改为 Device，记录方向约定的权威来源
    Sensor 装不下非感知类器件（将来的显示屏不是 sensor），Device 才普适；
    文件夹 src/sensor/ → src/device/，实例后缀 _sensor → _device。约定段补
    退出条件：不再代表物理模块的类型不属于器件层，应上移策略层。
    README 记录方向符号的来源：微雪官方示例 rotation.c 在 A 下落沿按 B 电平
    定符号，与本仓库查表在相同接线下符号一致，分辨率也一致（1 事件/电气周期）。
    官方波形标题与其代码符号不自洽，故顺时针对应音量加或减无权威答案，属产品
    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
2026-09-22 对齐官方示例：EC11 三路不再叠加 MCU 内部上拉
    微雪官方 rotation.c 不配置任何上下拉，其波形空闲高，两份证据都说明模块
    自带上拉；我们此前在 A/B 上叠加 gpio_pull_up、给自带按键传 InputPull::Up，
    属冗余假设。现三路统一 InputPull::None，上拉配置只留在 SwitchChannel 的
    电气约定里（通道层职责），README 同步改写。
    顺带整理 main.cpp 的 include 顺序。重构至此收口。
2026-09-22 手势检测进通道层：SwitchChannel 产出短按/长按/双击事件
    按压的时间语义（按住多久、两次间隔多近）是信号在时间上的细节，按本仓库
    约定归通道层；绑定什么动作是策略层的事，暂不绑定。
    - SwitchGesture {None, Short, Long, Double}；短按在松开时判定，长按 ≥700ms
    越过阈值即发，双击间隔 ≤300ms 且默认关闭（开启后短按需等间隔窗，故留到
    绑定双击动作那天再开）。
    - 行为变化：播放/暂停从按下边沿改到松开时发出（释放时判定语义）。
    - 移除被手势取代的 take_activated / take_switch_pressed。
    - RotationDevice 转发 take_switch_gesture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
    [switch_channel.cpp]
2026-09-22 绑定长按 = 静音切换（HID_USAGE_CONSUMER_MUTE 0xE2）
    0xE2 在 Windows 侧是 toggle，一次长按交替静音/取消，固件不需要第二个
    usage。绑定动作不改变任何描述符字节（报告是 Consumer 页 16-bit usage
    数组），故不递增 bcdDevice——上一轮 commit 信息里"绑完递增"的说法有误。
    README 行为表与手势段同步；台架清单新增"长按静音"可验项。
2026-09-22 头文件迁入 include/，与 src/ 平行分层
    include/ 专放头文件：层目录镜像（include/channel、include/device），公共头
    （media_hid.h、tusb_config.h）放 include/ 根。include 字符串带层名前缀且
    保持不变，故源文件零改动；CMake 的 include 目录从 src 改为 include。
    README 结构表与约定段同步。
2026-09-22 手势阈值改为构造参数：什么算长按归装配层
    去抖窗口是电气属性，留在通道内的编译期常量；长按时长与双击窗口
    是人机约定，降级为默认实参（kLongPressMs/kDoubleGapMs），调用方可
    按设备覆盖。detect_double 保持第 4 位，使「只开双击检测、吃默认阈值」
    的调用仍写作四个实参。
    README 顺带修正措辞：释放时判定只适用于短按，长按到阈值即发。
    [switch_channel.cpp]
2026-09-22 四个头文件补齐函数与成员注释：写状态角色，不复述类型
    成员注释说明它在状态机里的职责和不变量，而不是重复名字能告诉你的
    东西：last_sample_ms_ 是「上次通过节流的时刻」而非「最近一次调用」，
    pending_turns_ 的 int8 容量依赖调用方持续排空，pin_a_/pin_b_ 由器件
    直接读数而 SW 归通道自己管。
    函数注释写契约与踩坑条件：update() 的调用间隔必须远小于去抖窗口，
    否则一次完整的按下-释放会整体消失而不是被合并；take_gesture() 事件
    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
2026-09-22 main.cpp 与 media_hid.h 补齐函数与枚举注释
    media_hid.h 是对外契约，写清四件事：usage 全部落在描述符的
    USAGE_MAX 0x03FF 之内（加动作不必改描述符）、Mute 是主机侧 toggle
    所以一个 usage 覆盖两个方向、队列实际容量是 16 格中的 15 格（留一格
    使 head==tail 只可能表示空）、吞吐被按下/松开成对报告限死在约 100/s。
    main.cpp 补上循环不变量：每轮推进输入、排空两个信箱、再服务总线，
    其中任何一步都不得阻塞——去抖窗口、1ms 相位采样门和 8 位格数计数器
    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
2026-09-22 格数计数器改为显式饱和，消除 int8_t 有符号溢出 UB
    不可达不是正确性依据。++pending_turns_ 在 127 上是有符号溢出、未定义
    行为；实测（宿主机 MSVC 直接跑这个类）灌入 +200 格不排空，take_turns()
    返回 -56 —— 符号翻转，一次顺时针变成一记猛烈的逆时针。
    改为到达上限即停：正向饱和在 127，负向在 -128（int8_t 本来就能表示
    -128，不是笔误）。格数照常被消耗掉，所以 accumulator_ 在无人排空时也
    保持有界。代价是"少报"而不是"倒着报"。
    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
2026-09-24 fix: clamp quadrature transitions per detent to one
2026-09-24 fix: restore immediate short press behavior
    [button_gesture_decoder.h]
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2026-09-25 docs: correct RP2350 GPIO voltage guidance
2026-09-25 fix: track pending button short press explicitly
    [button_gesture_decoder.h]
2026-09-25 refactor: clarify button config and HID queue admission
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2026-09-25 fix: align encoder direction with clockwise controls
    [waveshare_rotation_sensor.cpp]
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2026-09-25 docs: clarify button gesture state and update flow
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2026-09-25 fix: clear gesture press state on release
    [button_gesture_decoder.h]
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2026-09-25 refactor: return button gestures short first
    [button_gesture_decoder.h]
2026-09-26 refactor: initialize input and device components through init
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2026-09-26 refactor: keep switch debounce constant in its class
2026-09-26 refactor: keep rotation sensor constants in its class
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2026-09-26 hardware: add RP2350 carrier PCB and manufacturing files
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2026-09-27 feat: add current controller enclosure CAD and print files
    [Base_Smooth_20deg.SLDPRT, Base_Smooth_20deg.STL, Button_Cradle.SLDPRT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]
2026-09-27 fix: reinforce recessed USB-C opening for enclosure printing
    [Base_Smooth_20deg.SLDPRT, Base_Smooth_20deg.STL, Button_Cradle.SLDPRT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]
2026-09-27 Fix enclosure nut-slot walls and rear-facing encoder clearance
    [Base_Smooth_20deg.SLDPRT, Base_Smooth_20deg.STL, Button_Cradle.SLDPRT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]
2026-09-30 docs: describe the repo as firmware + PCB + enclosure, align docs to carrier v1.1
    - Top README: product intro, three-part status table and repository tree
    replace the firmware-only framing; reference renders linked.
    - hardware/pcb: point at kiro-media-controller-carrier-v1.1, record the board
    as ordered and assembled, add a purchased-module reference section, and
    carry geometry read from the v1.1 source (32x35 outline, hole pattern,
    trace widths, six nets, 0.596 mm min different-net clearance and how to
    read it in EasyEDA Pro).
    - TUTORIAL: corrected against the actual board (J4 column was off by
    1.02 mm; silkscreen texts and coordinates; ENC_SIA/ENC_SIB net names).
    - enclosure RE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
